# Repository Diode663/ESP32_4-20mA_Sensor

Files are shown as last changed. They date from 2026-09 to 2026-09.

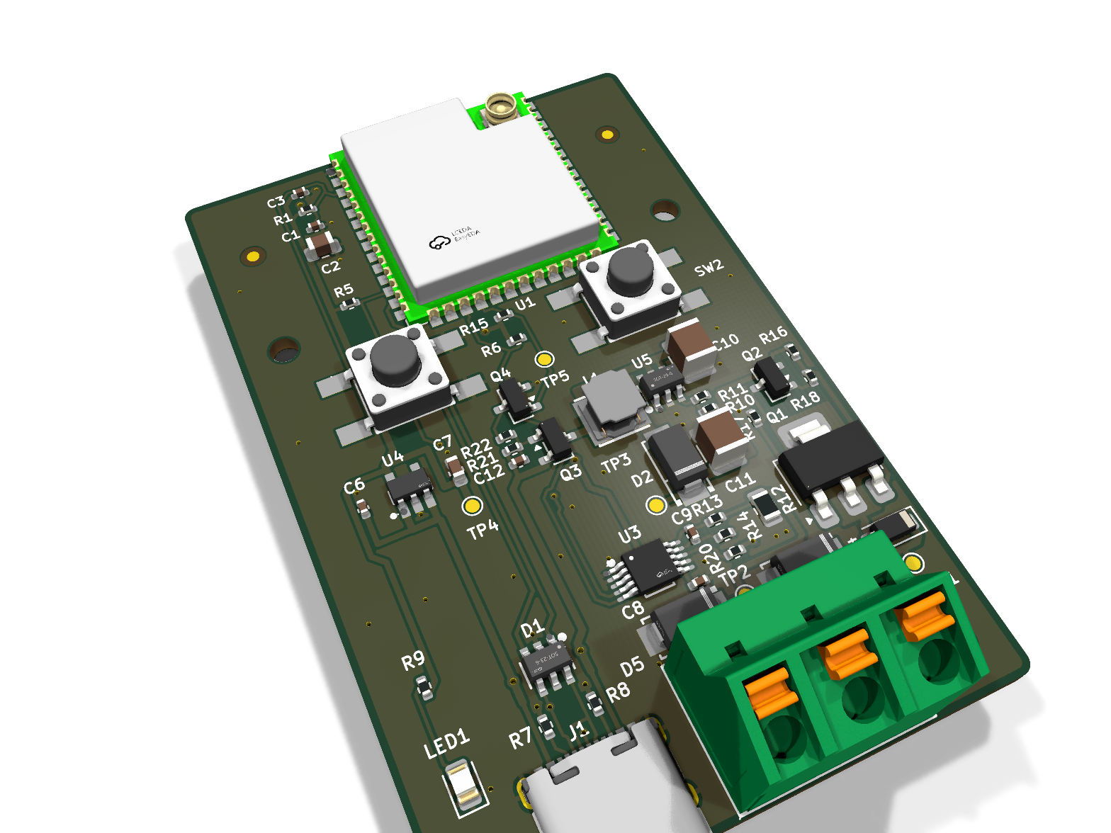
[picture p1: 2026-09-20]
render/pcb_angled.png

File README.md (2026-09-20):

# ESP32 4-20mA ESPHome Sensor Board

Single-channel industrial 4-20mA current-loop reader, USB-C powered, built for ESPHome.

## Rev G at a glance (2026-09-20)

Rev G is the result of a second, independent design review
(`docs/Design_Review_2026-09-20_second_pass.md`). Every circuit change below
was simulated first; the decks are in `sim/` and run on KiCad's own bundled
ngspice.

| Change | Why |
|---|---|
| Limiter is now **constant-current**: R19 removed, R16 18 ohm, Q1 -> BCP53-16 (SOT-223) | Rev F's foldback could park a transmitter at ~9 V / 14 mA after a short or a hot-plug and report that as the reading |
| **D4** (1N4148W) in series after Q1 | a surge on `LOOP_V` drove Q1 backwards into the 24 V rail from ~25 V, long before the TVS conducted |
| **D3 -> SMAJ28A to GND**, new **D5** SMAJ12A from `LOOP_RTN` to GND | one TVS across the pair handled only differential surges; common-mode went through the shunt into the INA226 |
| **Soft-start load switch** Q3/Q4/R21/R22/C12 ahead of the boost | VBUS saw ~27 uF at attach against USB's 10 uF limit; it now sees 1 uF, and `MT_EN` low truly disconnects the loop supply |
| **J2 is 3-pin**: GND, mA in, +24 V out | a 3-wire or self-powered (sourcing) transmitter could not be connected at all |
| **J2 is a one-piece push-in block**, KEFA KF250NH-5.0-3P (`C976567`) | no separate plug to order or lose; solid and ferruled wire pushes straight in, the orange button releases it or opens it for bare stranded wire |
| **U1 is the ESP32-S3-WROOM-1U-N4** (`C2980296`): U.FL connector, external antenna | antenna goes on the enclosure, not inside it. **The board is unchanged** - see below |
| L1 4.7 -> **22 uH** | a quarter of the ripple current at this light load |
| Boost and INA226 re-placed to their **datasheet layout figures** | switched-current loop 28 -> 19 mm^2 with C11's ground 3.8 mm from U5's (was 9.7); C8 1.5 mm from VS (was 8.0, on the wrong side of the chip) |
| Top M2 holes moved from the corners to y = 16.8 mm | they were level with the antenna, 9.6 mm from the module |
| `pcblib`: swaps changed footprints, DRC runs with `--schematic-parity` | the board had kept 1.5 mm test pads the schematic dropped for 1.0 mm, and nothing could see it |

**State:** 28 nets / 35 no-connects match the specification exactly, ERC 0
errors, schematic parity clean, placement DRC 4 (all deliberate silk-at-edge)
+ 5 library-internal, 52 parts + 4 holes + 3 fiducials, BOM 34 lines / 47
placements. **Placed and routed** - 0 unconnected, DRC unchanged at 4 + 5; see
[Routing](#routing).

**Firmware:** `firmware/` holds the ESPHome configuration, and both of the
things this board's firmware had to do are done there:

1. A reading is published as *unknown*, not as a plausible number, whenever
   the loop is not trustworthy - including `LOOP_V` below 20 V with current
   flowing. On a sustained short (`LOOP_V` < 3 V) it drops `MT_EN`, which now
   removes the supply entirely, retries three times and then latches off.
2. Two-point calibration at 4 mA and 20 mA, captured from Home Assistant with
   a reference source and stored in flash. R12's 1 % tolerance and 200 ppm/°C
   drift and R20's fixed gain error all come out together; one point cannot
   remove them.

The firmware is a reusable ESPHome package, pulled by URL, so another board
built from this design tracks the same definition.

It also classifies faults to NAMUR NE43 and detects a backwards-wired sourcing
transmitter, which reads as negative current through the shunt. Validated on
ESPHome 2026.9.0: config clean, and it compiles to 47 % of the N4's
application partition. See `firmware/README.md`.

### Going back to the PCB-antenna module

The -1U was swapped in **without touching the board**, deliberately. Espressif's
datasheet gives the -1 and the -1U one land pattern (Figures 10 and 11 carry
identical dimensions; the -1 only adds the antenna area), so the new footprint
`WIFIM-SMD_ESP32-S3-WROOM-1U` copies the old one's 61 pads and its origin
unchanged and differs only in body outline and 3D model. The outline, the
6.5 mm the antenna would overhang, the keep-clear at the top edge and the
lowered top mounting holes are all still laid out for the -1.

To revert, change one line in `generate_schematic.py` (the old line is kept
there as a comment) and re-run both generators. No copper moves.

With the -1U fitted the radio has **no antenna of its own**: the U.FL pigtail
and antenna in `bom/non-bom-items.csv` are required, and the connector is
U.FL / IPEX generation 1 - the smaller Gen 3/4 (MHF3/MHF4) plugs do not mate.

## Calibration

**Do this before you trust a reading.** R12 is a 1 % shunt with 200 ppm/°C
drift, and R20 adds a fixed 1.19 % gain error to the voltage reading. A single
point cannot remove both a gain and an offset error, which is why there are
two. The firmware ships with the identity calibration, so an uncalibrated
board is out by whatever its own components happen to be.

You need a loop calibrator, or any adjustable current source you trust to
better than the accuracy you want out of the board.

1. Wire the calibrator into **J2 pins 3 and 2** as if it were a 2-wire
   transmitter — the board supplies the 24 V and the calibrator sinks the
   current. An active source works too: push into pin 2, return on pin 1, and
   turn *Loop power* off first so the two supplies do not fight.
2. Set **4.000 mA**. Watch the `Loop current (raw)` entity and wait for it to
   settle — the median filter takes about 3 s, so give it ten.
3. Press **Calibrate: capture 4 mA**.
4. Set **20.000 mA**, wait again, press **Calibrate: capture 20 mA**.
5. Read the **Calibration** entity. It reports the pair you captured together
   with the resulting gain and offset, for example
   `4mA=4.0123  20mA=19.9871  gain=1.00212  offset=-0.0208 mA`.
   A gain more than a couple of percent from 1.000 means something is wrong —
   check the shunt and the wiring rather than accepting it.

A capture is **refused** if the raw reading is more than 2 mA away from the
reference it claims to be, and the log says so. That is deliberate: it stops a
mistimed press silently destroying the calibration.

The result is written to flash and survives reboots and OTA updates.
**Calibrate: reset to factory** puts back the values compiled into the YAML.

Recalibrate if the board's ambient temperature changes substantially: the
shunt's 200 ppm/°C over a 40 °C swing is 0.8 % of reading, about 0.13 mA
across the span. Full procedure and the entity list are in
[`firmware/README.md`](firmware/README.md).

## Project files

```
esp32-4to20ma-board.kicad_pro     Project file
esp32-4to20ma-board.kicad_sch     The schematic — one A2 sheet (generated)
schematic.pdf                     PDF of the schematic
esp32-4to20ma-board.kicad_pcb     Board, 40x61mm portrait — placed and routed
setup_fab.py                      Stackup, netclasses, board rules, .kicad_dru (run before routing)
route_board.py                    Routes the board: scripted critical nets + replayed autoroute + pours
routelib.py                       Routing library (from the kicad-pcb-placement skill): drawing, the
                                  Freerouting hand-off, replay, DRC and pour reports
routing/autoroute.json            Freerouting's result, replayed by route_board.py
routing/drc.json                  The last full DRC report
build_package.py                  Builds fab/: gerbers zip, BOM, CPL, order notes (DRC-gated)
jlc_cpl.py, jlc_rotations.json    CPL exporter and this board's sourced rotation corrections
jlc_compare.py                    Derives those corrections from JLCPCB's own footprints
fab/                              The JLCPCB upload, regenerated by build_package.py
place_components.py               Places every part; the source of truth for the layout
pcblib.py                         PCB builder (from the kicad-pcb-placement skill)
.pcbgen-backup/                   Backups of the board and of the original footprints
sym-lib-table / fp-lib-table      Project-local + KiCad-standard library references
libraries/                        Project-local symbols, footprints, 3D models from LCSC
datasheets/manifest.json          Which manufacturer datasheet was read for each
                                  IC, and where to get it — the PDFs themselves
                                  are copyrighted and not in this repository
firmware/                         ESPHome configuration — a shared package plus
                                  a thin per-device file. See firmware/README.md
bom/bom.csv                       BOM with LCSC part numbers, for JLCPCB turnkey
bom/non-bom-items.csv             Parts to order that aren't on the board
bom_report.py                     Regenerates bom/bom.csv from the schematic
docs/Design_Review_2026-09-20.md  Design review (schematic + placement, pre-fab)
docs/Design_Review_2026-09-20_second_pass.md   Second, independent review - what Rev G fixes
sim/                              ngspice decks for the limiter, surge path and USB inrush
analysis/                         Analyzer JSON per run, tracked by manifest.json
generate_schematic.py             Generates the schematic — the source of truth
schlib.py                         Schematic builder (from the kicad-schematic-layout skill)
.schgen-backup/                   Automatic backups of any sheet the generator overwrote
verify_schematic.py               Diffs KiCad's extracted netlist against the spec
netlist_report.py                 Regenerates netlist_report.txt
netlist_report.txt                Pin-level connectivity listing for rework
erc_report.txt                    Verification output (0 errors)
render/pcb_top.png                3D top view, written by place_components.py
render/pcb_angled.png             3D angled view
render/pcb_bottom.png             3D bottom view
render/copper_top.svg, copper_bottom.svg   The copper layers as drawn
render/pcb.svg                    Vector top view
render/pcb_top_pad_overlay.png    The top view with the real pad rectangles drawn
                                  over it — how the J2 pitch error and the three
                                  misplaced 3D models were caught
```

## Schematic organisation

The schematic is **one A2 sheet**. At 47 parts plus five test points the design still isn't complex
enough to justify hierarchy, which would only add page-flipping. The sheet has
four sections, tiled in signal-flow order:

```
USB-C INPUT & ESD   ->   3.3 V REGULATOR & LED   ->   ESP32-S3 MODULE
24 V BOOST CONVERTER   ->   LOOP CURRENT LIMITER   ->   LOOP TERMINAL & MEASUREMENT
TEST POINTS, sheet notes
```

One block per **circuit**, seven in all (it was twelve). The boost converter is
one block with its load switch, input and output in it, not three; the module is
one block with its reset, boot, pull-ups, decoupling and strapping notes, not
"module" and "support circuitry". Reference sheets for these parts are drawn the
same way - Adafruit's ESP32-S3 Feather divides its sheet into "POWER AND
FILTERING", "USB TO SERIAL CONVERTER", "LIPO CHARGING" and so on, with the module
and everything that serves it in one region.

Drawing conventions throughout:

- **Flow and orientation:** signals flow left to right; supplies come in from
  the top and grounds leave at the bottom.
- **Power rails:** `GND`, `+3V3`, `+5V` and `+24V` are drawn as power-port
  symbols, not text labels.
- **Links between sections:** the sections connect by net label — `USB_P` and
  `USB_N` from USB-C to the ESP32-S3, and `I2C_SDA` and `I2C_SCL` from the
  ESP32-S3 to the INA226.
- **Wires vs labels:** components are wired with real wires and junctions.
  Short labelled stubs are used only where a wire would cross another net: the
  USB-C flip pairing, the CC pulldowns, the MT3608's FB/SW pins and the INA226
  sense lines. There are no wire crossings on the sheet.
- **Blocks and notes:** each circuit is drawn inside `s.block_start(title)` /
  `s.block_end()`, with its design calculations as notes *inside* the block.
  No rectangle is typed by hand: `schlib` derives each outline from what is in
  the block (parts, field text, labels, notes, measured at KiCad's own glyph
  widths) plus 5 mm, and `arrange()` flows the blocks across the page in the
  order they are declared. `check_text()` then reads KiCad's render and fails
  on any string or part body within 0.8 mm of an outline. Run against the old
  hand-boxed sheet that check reports about a hundred such faults (`I2C_SCL`
  on the module box's edge, the strapping notes across another, `+24V` on the
  limiter's top line); on this sheet, none.

### Regenerating

`generate_schematic.py` is the source of truth. Edit it rather than the
`.kicad_sch` file, which gets regenerated:

```bash
python3 generate_schematic.py && python3 netlist_report.py
```

The generator re-checks the geometry and verifies the drawn netlist against its
`NETS` spec, using KiCad's own netlister. It also runs ERC, then a text check.
The text check reads KiCad's rendered SVG and flags any reference, value,
label or note that is drawn sideways, lies on a wire, or overlaps a part.

If the sheet was changed in KiCad since the last run, the generator refuses to
overwrite it. It backs the file up to `.schgen-backup/` first; port your edits
into the script, then rerun with `--force`.

### PCB after the switch to one sheet

Footprints are linked to schematic symbols by the symbols' sheet path, and
flattening the hierarchy changed every path. Update the PCB like this:

1. Run **Tools → Update PCB from Schematic**.
2. Tick **"Re-link footprints to schematic symbols based on their reference
   designators"**. All references are unchanged, so every footprint re-links.
3. Expect local net names to change prefix, e.g. `/USB-C Input…/CC1` → `/CC1`.
   The board has almost no routing yet, so nothing is lost.

From now on, UUIDs are deterministic, so regenerating won't break the links
again.

## Routing

The board is **routed**: 0 unconnected items, DRC at the same 4 + 5 it had as a
bare placement (four deliberate silk-at-edge warnings, five inside library
footprints), schematic parity clean. Two scripts, run in this order after
`place_components.py`:

```bash
"C:\Program Files\KiCad\10.0\bin\python.exe" setup_fab.py
"C:\Program Files\KiCad\10.0\bin\python.exe" route_board.py
```

`setup_fab.py` writes the JLCPCB 2-layer stackup (JLC0216A, 1.6 mm), the
netclasses (`USB` 0.25/0.20 mm pair, `POWER` 0.4 mm, `LOOP` 0.3 mm with 0.25 mm
clearance, `GND`) and a three-rule `.kicad_dru`. The board constraints are the
ones in *Fabrication rules* below, unchanged.

`route_board.py` is a **hybrid**. It removes every track, via and copper zone
and redraws them, so it is safe to run again after any placement change - and
it **discards hand edits to tracks**; change the script, or stop using it.

| Scripted (255 segments and vias) | Why it is not left to an autorouter |
|---|---|
| MT3608 boost | Figure 3: CIN returns to pin 2 *under* the IC, COUT returns down the east side of D2, the switch node is two stubs under 2 mm, FB is 1 mm from pin 3 to the divider |
| INA226 taps | Figure 30: the two taps enter the shunt pads on their inner faces as a pair; load current enters and leaves on the outer faces. R14.1 is on GND by name only, so the pour is kept off it - it sees the shunt pad and nothing else |
| USB-C fan-out, D1, the pair | see below |
| +5V, +3V3 and +24V trunks, the 24 V loop | widths, and the one place each may change layer |
| Q1's copper | tab and pin 2 are one area top and bottom (40 + 45 mm2), six vias under the body |
| every ground via, both pours | the bottom pour is **one unbroken piece** of 2179 mm2 |

Freerouting 2.4.1 does the rest - EN, IO0, MT_EN, I2C, the load-switch gate
network, the LED and the +3V3 branches: 113 segments, 7 vias. It runs only with
`route_board.py --autoroute`; its result is stored in `routing/autoroute.json`
and replayed on every ordinary run, so the board is reproducible (two runs give
byte-identical tracks) without Java and without re-rolling the autorouter. Run
`--autoroute` again if a part that only it touches moves. Runs differ: each one is
judged by KiCad's own DRC on a trial board and repeated (up to three times) until
nothing is left open, and `FREEROUTING_BEST_OF=3` keeps the best of three. Look at
the result either way - one re-roll here passed DRC with the bottom ground in two
pieces. It expects
`~/tools/freerouting/` (or `FREEROUTING_HOME`) to hold `freerouting-2.4.1.jar` and a Java
25 runtime; it runs headless, with the fan-out stage and telemetry off.

Three things about KiCad 10 + Freerouting 2.4.1 that cost time and are handled
in `routelib.py`: KiCad exports existing tracks as `(type route)`, which an
autorouter may rip up, so the DSN is patched to `(type protect)`; KiCad's
`ImportSpecctraSES` then refuses the session file, so the script reads the SES
itself and takes only unprotected items on nets it did not route; and
Freerouting does not count a track that ends inside a pad, off its centre, as
connected, so whatever it adds to a fully scripted net is dropped as a duplicate.

**USB.** J1's D+/D- pads read N P N P. The *outer* two (B7, B6) are the main
path - D- west, D+ east - which is the order both D1 (turned 180 degrees) and
module pins 13/14 want, so the pair never crosses itself. A6 joins D+ on the top
layer; A7 joins D- by the only bottom strap in the pair, 2.9 mm. The two VBUS
pins are joined on the board by a 4.8 mm bottom link under D1, which also feeds
D1's pin 5 (a receptacle's VBUS pins are only joined inside a plug). The pair
is 39.6 / 43.8 mm including those stubs; at the S3's 12 Mbit/s full speed the
4 mm difference is about 25 ps against an 83 ns bit.

**Where the bottom ground is cut**, all of it: the two USB-entry links above,
one SDA hop of 9.8 mm that passes under the pair at 45 degrees, +3V3 to the
pull-ups and U3 (39 mm in two runs, about 1 mA), and LOOP_V's sense tap to R20
(10.5 mm). Nothing crosses under the boost converter.

**Placement changes routing asked for** (all in `place_components.py`): D1
turned 180 degrees and moved up 1.5 mm; R7 and R8 moved into the lanes between
VBUS and the pair, 2 mm from their pins; R10/R11 moved beside U5, which lets
+24V reach the limiter on the top layer; C9 up 0.1 mm; R6 and R15 swapped so
each pull-up sits under its own pin (before that, MT_EN took a 25 mm detour
under the module).

Still open after routing: nothing has been measured. EMC and Q1's temperature
are as designed, not as tested.

## Fabrication package (JLCPCB)

```bash
"C:\Program Files\KiCad\10.0\bin\python.exe" build_package.py
```

writes `fab/`: `esp32-4to20ma-board_gerbers.zip` (9 layers + separate PTH and NPTH drill
files + drill maps), `_bom.csv` (34 lines, 47 parts), `_cpl.csv` (47 placements) and
`ORDER_NOTES.txt`. It refuses to build unless DRC is clean apart from the two accepted
errors inside J1's library footprint, the BOM is read from the board so it is exactly
what is placed, and the build stops if BOM and CPL designators differ or the board
disagrees with `bom/bom.csv`.

Three things to know before ordering:

- **Standard PCBA, not Economic.** JLCPCB lists the ESP32-S3-WROOM-1U-N4 (`C2980296`)
  as "PCBA Type: Standard Only". J2 is the one through-hole part; it is "Economic and
  Standard", wave-soldered, and rides along.
- **Rotations were derived, not guessed.** `jlc_compare.py` fetches JLCPCB's own
  footprint for each part's LCSC number and matches it to the board's, pad number to
  pad number. Every project-library footprint is already at JLCPCB's zero with zero
  origin offset. Only the four stock-KiCad transistor footprints differ - Q1 (SOT-223)
  and Q2, Q3, Q4 (SOT-23) need +180 - and those are in `jlc_rotations.json`, each with
  its evidence. None of it has been seen in JLCPCB's placement preview yet:
  `ORDER_NOTES.txt` says what each part should look like there. LED1's polarity rests on
  pad 1 being the cathode in their footprint (its silk says so; their symbol could not
  be fetched to confirm) - a reversed LED only stays dark.
- **All 34 lines were in stock at LCSC on 2026-09-20**, thinnest: U1 1,702, J2 1,990,
  R12 4,810, C10/C11 8,605. Nine manufacturer names in the BOM were wrong (the Samsung
  capacitors were listed as CCTC, the FOJAN resistors as Uniroyal, LED1 as
  "Nichia-compatible" - it is Nationstar) and were corrected in `generate_schematic.py`;
  every MPN and LCSC number was already right.

## PCB placement

Components are placed on a **40 × 61 mm** two-layer board,
portrait, with 1 mm rounded corners, by `place_components.py` on top of
`pcblib.py`. Run it with KiCad's Python:

```bash
"C:\Program Files\KiCad\10.0\bin\python.exe" place_components.py
```

**Re-running resets every part to the table.** Once you start adjusting
placement by hand, editing the `PLACEMENT` table is the only safe way to
change it. `pcblib` enforces this: it hashes the board each time it writes,
and if the file has changed since, it backs it up to `.pcbgen-backup/` and
refuses. Port your changes into the table, then run with `--force`.

Each run also:

- imports any footprint the schematic has and the board lacks, and reloads
  every footprint from its library, so schematic and `.kicad_mod` changes
  both reach the board without a trip through the KiCad GUI;
- re-links every footprint to its schematic symbol by UUID and assigns pad
  nets from KiCad's own netlist, so the ratsnest is right immediately and
  *Update PCB from Schematic* finds nothing to change;
- puts each reference designator where it clears pads, silkscreen, its
  neighbours and the board edge, at 0.15 mm stroke (JLCPCB's minimum);
- checks courtyard overlaps, **pad-to-pad gaps between different parts**,
  off-board parts and keep-out intrusions before saving, and aborts rather
  than writing a broken board. The pad-gap check matters: 8 of these 52
  footprints draw their courtyard around the body and leave the pads
  outside it (SW1 by 2.66 mm), so courtyard clearance flatters them. It
  caught the buttons sitting 0.35 mm from the module's pad row and the CC
  resistors 0.21 mm from J1 — both legal for DRC, both far too tight;
- runs DRC and **splits it in two** — placement problems, which are yours to
  fix, and problems inside a single library footprint, which moving parts
  cannot fix. Expect **4** and **5** respectively, 0 unconnected items, and
  `schematic parity: clean`. (Run it after moving a part and it will report
  shorts until `route_board.py` has been run again - the old tracks are still
  where the part used to be);
- prints the span of the critical nets, so the claims below are measurable
  rather than asserted;
- writes `render/pcb_top.png`, `render/pcb_angled.png` and `render/pcb.svg`.

All 5 placement-level warnings are `silk_edge_clearance`, on J1 where the
USB-C shell meets the board edge and on U1 where the module crosses the top
edge to overhang it - both deliberate.

`tidy_references` orders parts by `_part_extent()` (pads, silkscreen and
courtyard, deliberately blind to the text) with a natural sort on the
reference as tie-break, so repeated runs give byte-identical designator
positions. In Rev G it also searches further: the same eight spots with the
text turned upright, then both again up to 2 mm out, and it treats other
parts' courtyards as obstacles - pads and silk alone left the middle of the
SOT-223 looking like free board, and it put R12's designator there.

That still cannot solve the lower-right corner, which holds the limiter, the
sense network, two TVS diodes and the terminal. `REF_PINS` in
`place_components.py` places 18 designators by hand, each checked against DRC.

Five test points (`TP1`-`TP5`, 1.0 mm bare pads) sit on `LOOP_V`, `LOOP_RTN`,
`+24V`, `+3V3` and `MT_EN`. They are real schematic symbols - that is the only
way they get a net - but carry `in_bom=False`. Until Rev G the *board* still
held 1.5 mm pads: `pcblib` never propagated a footprint changed in the
schematic. It does now, and `Board.drc()` runs with `--schematic-parity`.

Four M2 holes: the bottom pair 3.5 mm in from the corners beside the
connectors, the top pair at y = 16.8 mm beside the buttons - 19 mm from the
antenna (Espressif asks for ~15 mm clear of metal) and 1.8 mm clear of the
button pads for a 4.6 mm standoff.

Three fiducials (`FID1`/`FID2`/`FID3`, 1 mm copper in a 2 mm mask opening)
sit at (4, 7), (36, 7) and (36, 54) mm — an L, 4 mm in from the edges, which
clears JLCPCB's 3.85 mm minimum. They are board-only footprints: no schematic
symbol, excluded from the BOM and from the placement file, so they cannot
become orphan designators in a PCBA upload.

`pcblib.py` is the shared library from the `kicad-pcb-placement` skill; it is
copied in so the project stays self-contained.

### Why the board is this shape

**Portrait, 40 × 61 mm.** About the minimum for this part set. The
measured extents are 2.40 mm of margin left and right — set by the M2
mounting holes, not by any component — J1's shell flush with the bottom edge,
and C3 1.80 mm from the top. Width is pinned by the bottom edge: J2's
courtyard is 12 mm wide (it includes the mating plug), J1's is about 10, and
the two corner mounting holes take 6 mm between them. Height is pinned by the
vertical stack: module 19 mm, buttons 7, boost 14, sense chain 10, connectors
10. The extra 1 mm over the first attempt buys ~1 mm of clearance either side
of the buttons.

**The antenna overhangs the top edge.** The board stops level with the start
of the module's pad rows, so 6.5 mm of antenna hangs in free air —
Espressif's best case, and better than any keep-out on a populated board. The
module is then soldered on three edges with that 6.5 mm unsupported, so the
enclosure needs clearance around it and must not press on it. There is no
antenna keep-out zone any more: the overhang replaced it. At routing time,
keep the ground pour back from the top edge.

**Both connectors are on the bottom edge**, as asked. Note that J2 is a
*vertical* plug-in header — the mating plug drops in from above — so its
position at the edge is for cable dressing, not because it needs edge access.

| Area | What's there | Why |
|---|---|---|
| Top, antenna overhanging | ESP32-S3 module, centred | No PCB under the antenna at all |
| Upper left | C3 at pin 2 (3V3), R1/C1 at EN, C2 bulk, R5 at pin 12 | The module's 3V3, EN and SDA pins are all on the left flank; each part sits level with the pin it serves |
| Below the module | RESET and BOOT buttons, R6 and R15 in the gap between them | SCL (17) and the loop enable IO10 (18) come out of the module's bottom edge, right where their pull-ups sit |
| Left, middle | AP2112K LDO + C6/C7 | Between its 5 V source at the bottom and its 3.3 V loads above |
| Right, middle | MT3608 boost: C10, L1, U5, D2, C11 in one tight loop, FB divider by the FB pin | Per the MT3608 datasheet, and the furthest point on the board from the antenna |
| Right, lower | INA226, shunt R12, R13/R14 tapping its two ends, C9 | Kelvin sense per the INA226 datasheet; U3 faces the shunt with its inputs and the MCU with its I²C |
| Bottom left | USB-C, D1 ESD clamp directly above it, CC pulldowns either side, LED on the left edge | D+/D− run connector → clamp → module with nothing in the way |
| Bottom right | 4-20 mA terminal J2, TVS D3 just above it aligned with its pins | Field wiring lands at the edge and is clamped immediately |

Measured after placement:

| Net | Span | Comment |
|---|---|---|
| `/MT_SW` | 5.45 mm | the boost switching node — the one that matters |
| `/LOOP_RTN` | 9.68 mm | terminal to shunt |
| Kelvin taps | 1.69 mm | R13 and R14 each sit against the shunt pad they measure |
| `/USB_P` / `/USB_N` | 35–36 mm | the cost of portrait: connector at the bottom, module at the top. Fine for the S3's 12 Mbps full-speed USB, but route them as a pair over unbroken ground |
| `/I2C_SDA` / `/I2C_SCL` | 28–35 mm | 400 kHz, length is irrelevant |

### Loop short-circuit protection

A boost converter cannot disconnect its output: `Vin -> L1 -> D2 -> Vout` is a
DC path that conducts with U5 disabled. Shorting Loop+ to Loop- therefore fed
~1.35 A from the 5 V rail straight through the shunt, destroying R12 (about
6 W in an 0805) and browning out the board.

The fix is a series element, which costs only compliance voltage, never
accuracy, because the transmitter regulates the loop current:

| | |
|---|---|
| Q1 | PNP pass element, **BCP53-16 in SOT-223** (80 V, 1.5 W) |
| R16 | 18 ohm sense; Q2 steals Q1's base drive once the drop across it reaches a Vbe |
| R18 | 1 k in Q2's base - limits its base current, nothing more |
| R17 | 47 k base bias, ~0.5 mA; BCP53-16 hFE >= 100 turns that into 50 mA |
| D4 | 1N4148W in series after Q1: blocks `LOOP_V` from driving Q1 backwards |

`Ilim = Vbe(Q2) / R16`: **35 / 33 / 30 / 27 mA at -20 / 25 / 60 / 85 C**
(`sim/6_rev_g_limiter.py`), so a 24 mA over-range reads at any temperature.
R16 + Q1 + D4 cost 1.2 V: **22.8 V at J2 with 20 mA flowing**.

**It is deliberately not a foldback limiter, and Rev F's was a mistake.** A
2-wire transmitter is a constant-current load: it draws the same current at
any voltage above its lift-off, so its load line can cross a foldback curve
twice, and the lower crossing is stable. After a short was cleared, or a
transmitter was plugged into a live J2, Rev F could sit at ~9 V / 14 mA
indefinitely with the process at 20 mA - and report 14 mA
(`sim/recover.py`). Its short-circuit current was also the small difference of
two ~0.6 V terms and fell to zero by ~65 C. Cold power-up happened to work,
which is why it looked fine.

The price is dissipation: a dead short puts the whole rail across Q1,
24 V x 35 mA = **0.85 W**. That is what the SOT-223 is for - pour `LOOP_C`
generously around the tab and stitch it to the bottom layer. Firmware should
also drop `MT_EN` on a sustained short; with the Rev G load switch that
removes the supply entirely rather than leaving 4.6 V behind.

### Field protection

Each field wire has its own TVS **to ground**, within 6 mm of its terminal
pin: D3 (SMAJ28A, clamps at 45 V) on `LOOP_V`, D5 (SMAJ12A, clamps under
20 V) on `LOOP_RTN`. Rev F had one SMAJ36A *across* the pair, which did
nothing for a common-mode surge: that returned through R12, and the INA226's
inputs saw `I x 3.32 ohm` through only 10 ohm. D5 sits at 80 mV in normal
operation and leaks nanoamps, so it costs no accuracy; and D3's leakage no
longer flows through the shunt.

D4 matters as much as the TVS. `LOOP_V` was Q1's collector, and a PNP's
collector-base junction is a diode: from ~25 V it conducted backwards, the
emitter-base junction avalanched at ~7 V of reverse bias, and the surge went
into the 24 V rail through R16 - toward U5's SW pin, rated 30 V absolute - all
before the old 36 V TVS reached breakdown (`sim/4_reverse_conduction.py`).
With D4 the reverse current is zero to beyond D3's clamp. It is a 1N4148W
rather than a Schottky because it sees the clamp minus the rail in reverse.

### Soft-start load switch

Q3 (AO3401A) sits between VBUS and everything the boost hangs on it: C10, and
C11 through L1/D2. Q4 (2N7002) turns it on from `MT_EN`; U5's own EN now rides
on its switched input. C12 is gate-to-**source** on purpose - a gate-to-drain
(Miller) capacitor was tried first and fails at hot-plug, because with the
drain at 0 V it drags the gate low as VBUS steps up and turns Q3 hard on for
the very edge it is meant to soften. Simulated (`sim/7_usb_inrush.py`): VBUS
sees **1.0 uF at attach, down from 26.8 uF** (USB allows 10), then a 0.33 A
peak 4 ms later as the boost input charges.

The INA226's VBUS tap moved to the **field side** of the limiter, so a short
shows up twice over: the current reads saturated (anything past 24.67 mA) and
the loop voltage collapses. Firmware can tell a shorted field pair from an
open one.

### J1's hole clearance, and why the rule moved

All four `hole_clearance` errors were inside J1's own footprint — its two
0.70 mm NPTH locating pegs against its own pads, nothing to do with placement.
JLCPCB publishes **0.20 mm** NPTH-to-track for 2-layer boards; this project was
running a stricter 0.25 mm, so half the errors existed only because of our own
rule. `min_hole_clearance` is now 0.20 mm and the count drops to two.

The two that remain (0.1812 mm, 0.019 mm inside JLCPCB's limit) are an
**accepted deviation**: they are on the *duplicated* GND pads — A1/B12 and
B1/A12 are the same nets on both sides of the receptacle — so a drill breakout
into one would not open the connection. If JLCPCB objects at DFM review, the
fallback is to trim those two pads by ~0.07 mm, which costs about 6 % of their
solder area and clears even the old rule.

### Fabrication rules (JLCPCB, 2-layer)

Board Setup now carries JLCPCB's published capabilities. Where the board was
already stricter it was left alone — being tighter than the fab is a design
choice, being looser is a defect:

| Rule | Was | Now | JLCPCB |
|---|---|---|---|
| Minimum clearance | **0.0 (off)** | 0.127 | 0.127 |
| Silkscreen line width (default) | 0.10 | 0.15 | 0.15 |
| Silkscreen text thickness (default) | 0.10 | 0.15 | 0.15 |
| Track width | 0.153 | 0.153 | 0.127 |
| Via diameter / annular ring | 0.5 / 0.13 | unchanged | 0.45 / 0.125 |
| Through-hole diameter | 0.3 | unchanged | 0.2 |
| Copper to board edge | 0.5 | unchanged | 0.3 required, 0.5 recommended |

The important one is **minimum clearance, which was 0.0** — DRC had no global
spacing floor at all, only the netclasses' own 0.2 mm. The track and via size
menus were empty and are now populated with 0.25/0.4/0.6/0.8 mm tracks and
0.6/0.3, 0.8/0.4 vias, all above JLCPCB's floor.

JLCPCB does not publish a hole-to-copper figure, so `min_hole_clearance`
stays at the widely cited 0.25 mm — which is what J1's four remaining errors
are measured against. See below.

### Library-footprint fixes

The EasyEDA-sourced footprints in `libraries/esp32-4to20ma-board.pretty/`
had three real problems. All three are now fixed; the originals are in
`.pcbgen-backup/footprints-*/`.

| Part | Was | Now | Why |
|---|---|---|---|
| U1 | 12 thermal vias in the ground pad, unnumbered, 0.25 mm drill, 0.075 mm ring, paste over an open hole | pad `41`, 0.30 mm drill, 0.60 mm pad (0.15 mm ring), no paste, mask opening on the front only | Unnumbered meant they carried no net, so they grounded nothing *and* read as a foreign net inside the pad they sit in — that alone was 24 clearance errors. The drill and ring were below the board minimums. Paste over an open hole wicks solder away from the joint; tenting the back stops it running through |
| J1 | two 0.7 mm locating pegs defined as plated holes with pad = drill, so no copper ring at all | `np_thru_hole` | They are mechanical locating posts, not connections |
| J2 | 3D model pointed at `WJ5.08-LI`, a different part | KiCad's `PhoenixContact_MSTBVA_2,5_2-G-5,08_1x02_Vertical` | Cosmetic. A stand-in of the same class, pitch and pin count — its body renders a little larger than the real WJ2EDGVC, which is 9.5 × 5.6 mm |

That took the footprint-level DRC count from **59 to 7**, and the board from
96 unconnected items to 88 (the 12 vias now join GND).

**A fourth problem, found on 2026-09-20 by looking at the 3D render:**

| Part | Was | Now | Why |
|---|---|---|---|
| J2 | pads at ±2.50 mm — a **5.00 mm pitch** | ±2.54 mm, **5.08 mm** | `C8445` is `WJ2EDGVC-5.08-02P`; LCSC's own parametrics say `P=5.08mm`. The footprint was 0.08 mm narrow across the pair. With a 1.70 mm drill and ~1.0 mm pins it would still have assembled, so DRC and the netlist never saw it — but it was wrong, and it is the kind of error that only shows up when a part will not seat |
| D2 / D3 / D5 (SMA) | courtyard ±2.16 × ±1.30 mm, drawn round the body — the 2 × 2 mm pads at ±2.2 stuck 1 mm out of it | ±3.45 × ±1.55 mm, pads + 0.25 | Rev G. With the pads outside the courtyard, a layout that was courtyard-legal put two SMAs dead against a test pad: DRC reported `shorting_items`. |
| L1 (FNR4030) | courtyard ±2.00 mm square; pads reach ±2.30 | ±2.55 × ±2.25 mm | Rev G, same cause. |
| J2 (3-pin) | — did not exist | `CONN-TH_WJ2EDGVC-5.08-3P` | Rev G. Derived from the corrected 2-pin footprint: same profile, one more 5.08 mm position, body 17.2 mm. LCSC `C8412`. **Superseded the same day by the KF250NH below; the footprint is kept in the library, unused.** |
| J2 (KF250NH-5.0-3P) | — new | `CONN-TH_KF250NH-5.0-3P`, with symbol and STEP/WRL model | From LCSC/EasyEDA (`C976567`) via `easyeda2kicad`. Checked against KEFA's drawing before use, because the last EasyEDA terminal footprint had the wrong pitch: 5.00 mm pitch, 14.1 × 10.0 mm body, pins 5.70 mm from the wire-entry face, Ø1.5 drill against Ø1.4 +0.1 — all correct. Symbol pins changed from *unspecified* to *passive*. |
| U1 (WROOM-1U) | — new | `WIFIM-SMD_ESP32-S3-WROOM-1U` | The **existing** footprint's 61 pads and origin copied unchanged, with the 19.2 mm body outline and the -1U 3D model from EasyEDA (`C2980296`). EasyEDA's own -1U footprint was *not* used: its pad centres sit 0.15 mm further in than the verified pattern already on the board. Model offset 0.54 mm, checked in the render. |

**And three 3D models were misplaced** — cosmetic for fabrication, since gerbers,
drill, paste and CPL all come from the 2D layers, but they make the render
useless for judging mechanical fit, which is exactly what a render is for:

| Part | Offset added | Why |
|---|---|---|
| U1 | `0, 3.700, 0` | The model is centred on its own body; the footprint origin is at the centre of the **pad array**, and the module's 6.5 mm antenna end carries no pads. The body was drawn 3.7 mm down the board |
| J1 | `0, -1.190, 0` | Same class of problem — the USB-C shell is not centred on the pad array |
| J2 | `-2.540, 0, 0` | The Phoenix stand-in's origin is on **pin 1**, not between the pins, so the body sat one half-pitch to the right |

Verified by measuring the rendered bodies against the footprints' silkscreen
outlines: all three now agree to within 0.2 mm. `render/pcb_top_pad_overlay.png`
is the render with the real pad rectangles drawn on top, which is how the
mismatch was confirmed rather than eyeballed.

`place_components.py` calls `refresh_footprints()` before placing, so
library fixes reach the board — KiCad stores its own copy of every
footprint, and editing a `.kicad_mod` alone changes nothing.

**Still open, both judgement calls rather than mistakes:**

- **4 × `hole_clearance` on J1.** The two NPTH locating pegs sit 0.18 mm and
  0.22 mm from the neighbouring USB-C pads, against a `min_hole_clearance`
  of 0.25 mm in Board Setup. That is the connector's real geometry, not an
  error — the part is simply dense. Check what your fab actually allows for
  a non-plated hole next to copper; if it is 0.15 mm, relax the rule rather
  than shaving the pads.
- **3 × `silk_over_copper`** on J1, SW1 and SW2, where each footprint's own
  outline crosses its own pads. Cosmetic; fabs clip silkscreen at the mask
  automatically.

**Not a footprint problem, but worth noting:** J2 is the *board-side header*
only. The mating plug — the screw-terminal half the field wires land in — is
a separate part and is not in the BOM. It is a vertical part: the plug drops
in from above, so nothing about it requires the board edge.

### Why it's no longer hierarchical

Rev B used a root block diagram plus four sub-sheets. The old sheets are in
`.schgen-backup/flatten-*/` and in KiCad's Local History.

## Design summary

- **MCU**: ESP32-S3-WROOM-1U-N4 (4MB flash, U.FL connector for an external antenna), dual-core LX7, Wi-Fi/BLE, **native USB** — no USB-UART bridge chip.
- **Power in**: USB-C receptacle, data+power (no PD negotiation — plain 5V/500mA sink). CC1/CC2 have 5.1kΩ pulldowns per USB-C spec. USBLC6-2SC6 ESD-protects the D+/D- lines, wired straight through to the S3's native USB pins (IO19/IO20).
- **Programming**: no bridge chip, no auto-reset transistors. Per Espressif's own ESP32-S3-WROOM-1 reference design, the chip's internal USB-Serial/JTAG Controller peripheral handles esptool's reset/bootloader-entry handshake directly over the native USB connection — GPIO0's default strapping (internal weak pull-up) plus GPIO46's default strapping (internal weak pull-down) already satisfy the "Joint Download Boot" condition, so esptool can flash and open a console with zero external reset circuitry. SW1 (RESET, EN→GND) and SW2 (BOOT, GPIO0→GND) are kept as manual fallback buttons, matching Espressif's reference.
- **3.3V rail**: AP2112K-3.3 LDO (600mA), powers the ESP32-S3 and INA226.
- **24V loop supply**: MT3608 boost converter, 5V→24V, fed through a soft-start load switch (Q3/Q4) and feeding the field terminal through a **constant-current limiter** (Q1/Q2, R16-R18, D4). `MT_EN` is held high by R15 (100k to 3.3V) and pulled low by IO10; it gates the load switch, so firmware can remove loop power entirely or power-cycle a stuck transmitter. L1 is 22µH. Feedback divider R10=390kΩ/R11=10kΩ gives exactly 0.6V×(1+39) = **24.00V**. Rated for far more than the 30mA the loop needs — this is the same MT3608 topology recommended in its own datasheet, just very lightly loaded here.
- **Current sensing**: INA226 (I2C, 16-bit, TI). Low-side shunt R12 = 3.32Ω 1% between the loop-return terminal and GND. The INA226's shunt input is fixed at ±81.92mV with no PGA, so the shunt alone sets the ceiling: 3.32Ω puts full scale at **24.67mA**, which reads a sensor driving 23.5mA over-range instead of clipping. 24mA gives 79.7mV (97% of range) and the 2.5µV LSB works out at 0.75µA — about 21,200 counts across the 4-20mA span, far beyond any transmitter's accuracy. (Rev C used 4.02Ω, which clipped at 20.4mA.) 10Ω series filter resistors (R13/R14) + a 100nF cap across the sense lines follow the INA226 datasheet's own recommended input-protection network (fig. 21) for exposed field wiring. INA226's VBUS pin reads the loop supply voltage as a diagnostic, tapped downstream of the limiter through **R20, a 10kΩ series resistor**: D3 clamps as high as 58.1V at its rated surge current, well past the INA226's 40V absolute maximum, and the pin is rated for only ±5mA. R20 holds the worst case to 1.8mA. It costs 1.19% of gain against the 830kΩ input impedance, which firmware corrects and which does not touch the current measurement.
- **Field wiring**: 3-position one-piece push-in spring terminal, 5.00mm pitch (KEFA KF250NH-5.0-3P, 16–20 AWG) — **1 = GND, 2 = mA in, 3 = +24V out**, numbered left to right looking into the wire entry. A 2-wire transmitter goes on 3-2; a self-powered (sourcing) output on 2-1; a 3-wire sensor uses all three, within the ~30mA limit. Each field wire has its own TVS to ground (SMAJ28A / SMAJ12A).
- **I2C**: GPIO8 (SDA) / GPIO9 (SCL), 4.7kΩ pull-ups — the conventional default I2C pins on ESP32-S3 boards.

## Why these specific parts

Every non-passive part was picked from real LCSC/JLCPCB stock and its **actual manufacturer datasheet was read** (not just the LCSC listing) to get the pinout and application values right — see `datasheets/`. In particular:
- ESP32-S3-WROOM-1's pinout, strapping-pin table, USB_D+/D- pin assignment (IO20/IO19), and Espressif's own peripheral reference schematic (section 6, which explicitly omits any external reset circuitry for the native-USB path) came straight from Espressif's datasheet.
- MT3608's feedback equation, recommended inductor/cap values, and diode rating came from the Aerosemi datasheet.
- INA226's shunt-sensing topology, pin functions, and input-filtering recommendation came from the TI datasheet.

## Why we switched from ESP32-WROOM-32E + CH340C

The board originally used a classic ESP32-WROOM-32E with a CH340C USB-UART bridge for flashing. We switched to a native-USB ESP32-S3 module after comparing both approaches:
- **Fewer parts, similar cost**: dropping CH340C + its 2 bypass caps + both 2N7002 auto-reset transistors + their 2 gate resistors (8 parts total) more than offsets the S3 module's slightly higher unit price — net BOM cost actually went *down* slightly.
- **Better dev experience**: native USB gives real USB-JTAG hardware debugging (impossible on the bridge-chip design without an external JTAG probe) and a driverless CDC-ACM console on modern OSes.
- **Trade-off accepted**: losing CH340C as a "sacrificial" USB layer — if the S3's native USB pins are ever ESD-damaged, both flashing and the wired console go down together, versus the old design where a blown bridge chip only killed flashing (OTA over Wi-Fi still worked). Given this board lives on a bench/in an enclosure rather than a harsh field environment, that trade-off was judged acceptable.

## Verification performed

- **Netlist equivalence**: `verify_schematic.py` exports the netlist with
  `kicad-cli` — KiCad's own connectivity engine, the same one the PCB uses — and
  diffs it against the `NETS` specification in `generate_schematic.py`, matching
  nets by their *set of pins*. All 28 nets and all 35 no-connects match exactly
  (the five test points included).
  This is what catches a mistyped coordinate silently shorting two nets.
- `kicad-cli sch erc` → **0 errors, 59 warnings**: 58 are the "Unspecified" pin
  electrical type carried by EasyEDA-converted symbols (cosmetic — the symbols
  simply don't declare input/output/power roles) and 1 is the expected
  cached-symbol-vs-library sync notice. Report in `erc_report.txt`.
- **Geometry guards** in `schlib.py` run on every build and fail the generate if
  any pin, wire end or label misses the 1.27 mm connection grid, or if a wire end
  connects to nothing. Both classes of defect are invisible to a netlist diff.
- Rotation handling was verified empirically against KiCad rather than assumed:
  placing a `Device:R` at each of 0/90/180/270 and reading back which pin landed
  where (rot 0 → pin 1 up, 90 → left, 180 → down, 270 → right).
- `kicad-happy` schematic analyzer: 33 components / 25 unique parts, zero missing MPNs.
- `kicad-cli pcb drc` on the (currently empty) board outline → 0 violations.

## Known limitations / things to look at before ordering

- **Two nets were renamed** when the rails became power symbols: `VUSB_5V` → `+5V`
  and `LOOP_24V` → `+24V`. The board currently has footprints placed but almost no
  routing, so just run **Tools → Update PCB from Schematic** and KiCad will carry the
  new names over; footprint associations are preserved by the stable UUIDs.
- **The board is routed but nothing has been built or measured.** See [Routing](#routing). The USB pair is coupled but not impedance-controlled: on a 1.6 mm two-layer board 90 Ω needs a coplanar geometry, and at USB Full-Speed (12 Mbps) over 40 mm it does not matter.
- INA226's Alert pin is left unconnected — intentional (the datasheet explicitly allows floating it when the alert function isn't used), but wire it to a spare GPIO if you want threshold interrupts later.
- GPIO3 (JTAG-source strapping pin) is left unconnected. The datasheet notes it has no internal pull resistor and should ideally be actively driven, but since this board doesn't break out a JTAG header, an undefined JTAG-source selection at boot has no functional effect — only relevant if you later add a JTAG connector.
- ~~No dedicated VBUS transient suppressor~~ — **this was wrong, and the datasheet says so.** ST's USBLC6-2 lists "Protects VBUS" in its features and specifies `VBR`, the breakdown voltage between VBUS and GND, at 6V minimum at 1mA: there is a zener inside the part between pin 5 and ground, and D1 pin 5 is on `+5V`. VBUS is protected. (The board's ESD analyzer flags this too, as `UC-002`; it is a false positive.)
- Only 1 channel, per the current 24V/30mA supply budget. See the earlier discussion if you want to scale to multiple loop-powered channels — the 24V rail current draw scales roughly linearly per channel.

## Ordering

`bom/bom.csv` is generated from the schematic by `bom_report.py` — run it after
any part change rather than editing the CSV's first seven columns by hand:

```bash
python bom_report.py
```

It regroups by LCSC number (the ordering key, so SW1 and SW2 merge into one
line despite having different values) and carries the spreadsheet's own
columns — LC_Stock, Chosen_Distributor, Validated, Notes — forward on each
re-run.

**Cost: about USD 7.20 per board** in components at LCSC's single-unit prices
on 2026-09-20 (Rev F was 6.31; the Rev G circuit changes add about 0.24, the -1U module 0.26 and the push-in terminal 0.37), 47 placements over 34
order lines. The module is about 61% of that ($4.41) and the INA226 another
12% ($0.79). Sixteen of the 34 lines are JLCPCB *extended* parts, so turnkey
assembly adds roughly $48 of one-off setup fees on top. Of the Rev G
additions, the 1N4148W, AO3401A and 2N7002 are basic; the BCP53-16, both TVS
diodes, the 18 ohm, the 22 uH and the 3-pin socket are extended. PCB, stencil
and M2 hardware are not included.

`bom/bom.csv` has every part's LCSC number, ready for JLCPCB's BOM/CPL turnkey flow once the PCB is routed and gerbers/CPL are exported (the `jlcpcb` skill covers that step). Anything that has to be ordered but isn't on the board lives in `bom/non-bom-items.csv`, hand-maintained since none of it is derivable from the schematic. Today that is the **U.FL pigtail and 2.4 GHz antenna** the -1U module needs - it has no antenna of its own. (Rev F and early Rev G also needed a mating plug for the pluggable terminal; the one-piece push-in block does not.) Candidates to add when you get to ordering: M2 screws and standoffs for the four mounting holes, a USB-C cable, and a stencil.

## Licence

Copyright Diode663 2026.

**Hardware** (the KiCad project, schematic, board, the project's own symbols and footprints,
fabrication outputs and documentation): this source describes Open Hardware and is licensed under
the CERN-OHL-P v2. You may redistribute and modify this source and make products using it under
the terms of the CERN-OHL-P v2 (<https://ohwr.org/cern_ohl_p_v2.txt>), a copy of which is in
[`LICENSE`](LICENSE). This source is distributed WITHOUT ANY EXPRESS OR IMPLIED WARRANTY,
INCLUDING OF MERCHANTABILITY, SATISFACTORY QUALITY AND FITNESS FOR A PARTICULAR PURPOSE. Please
see the CERN-OHL-P v2 for applicable conditions.

**Software** (every `*.py` file, and the ESPHome configuration in `firmware/`): MIT, see
[`LICENSE-MIT`](LICENSE-MIT). `schlib.py` and `pcblib.py` are copied in from
[kicad-claude-skills](https://github.com/Diode663/kicad-claude-skills) so the project stays
self-contained; they are MIT there too.

**Not covered by either licence** — third-party material, included for convenience and owned by
its respective rights holders:

- Footprints and 3D models obtained from LCSC / EasyEDA with `easyeda2kicad`: everything in
  `libraries/esp32-4to20ma-board.3dshapes/`, and in `libraries/esp32-4to20ma-board.pretty/` the
  `CONN-TH_KF250NH-5.0-3P`, `CONN-TH_WJ2EDGVC-5.08-2P`, `IND-SMD_L4.0-W4.0_FNR40XXS`,
  `MSOP-10_L3.0-W3.0-P0.50-LS5.0-BL`, `SMA_L4.3-W2.6-LS5.2-RD`, `SOT-23-6_L2.9-W1.6-P0.95-LS2.8-BL`,
  `SOT-25-5_L2.9-W1.6-P0.95-LS2.8-BL`, `SW-SMD_4P-L6.0-W6.0-P4.50-LS9.0_H5.0`,
  `USB-C-SMD_TYPE-C-16PIN-2MD-073` and `WIFIM-SMD_ESP32-S3-WROOM-1-N8` footprints. Several carry
  project corrections — pitch, courtyards, pad numbering and 3D offsets — which are documented in
  the library-footprint table above; `CONN-TH_WJ2EDGVC-5.08-3P` and `WIFIM-SMD_ESP32-S3-WROOM-1U`
  are derived from them.
- Manufacturer datasheets are **not** in this repository. `datasheets/manifest.json` records which
  ones were read and where they came from; fetch them from the manufacturers or LCSC.
- Part numbers, stock figures and prices in `bom/` are LCSC's.

Nothing here is affiliated with or endorsed by Espressif, Texas Instruments, Aerosemi, KEFA,
LCSC or JLCPCB.

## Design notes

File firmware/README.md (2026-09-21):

# Firmware — ESPHome

ESPHome configuration for the Rev G board. It turns the INA226's shunt reading
into a calibrated 4-20 mA measurement, classifies loop faults to NAMUR NE43,
and protects the board against a sustained field short.

Validated against **ESPHome 2026.9.0**: `esphome config` is clean,
`esphome compile` builds at **870 KB of the 1.835 MB** application partition
(47 %) with 30 % of RAM used, and `test/test_fault_logic.py` passes 30 checks.
There is real headroom on the N4 module.

## Files

```
package/esp32-4to20ma-board.yaml   The instrument. Everything hardware-specific
                                   and all the logic. Shared by every board.
loop-sensor-1.yaml                 One board: a name, a Wi-Fi network and the
                                   process scaling. Copy this per unit.
secrets.yaml.example               Copy to secrets.yaml and fill in.
```

The split exists so a logic fix reaches every unit at once. The device file
pulls the package straight from GitHub:

```yaml
packages:
  loop_board: github://Diode663/ESP32_4-20mA_Sensor/firmware/package/esp32-4to20ma-board.yaml@main
```

**Pin a tag rather than `@main`** on any instrument you care about — otherwise
an upstream edit rewrites its firmware the next time you flash it.

When you are working on the package *itself*, switch that line to the
commented `!include` next to it. With `github://` you compile whatever was last
**pushed**, not what is on your disk, which is a confusing half hour if you
forget.

## Getting started

```bash
cp secrets.yaml.example secrets.yaml   # then fill it in
esphome run loop-sensor-1.yaml
```

The first flash has to be over USB. The board enumerates as a native
USB-Serial-JTAG device — there is no bridge chip — so `esphome run` finds it
without a driver on any current OS. If it does not appear, hold **SW2 (BOOT)**,
tap **SW1 (RESET)**, release SW2, and try again.

## Calibrating

**Do this before you trust a reading.** R12 is a 1 % shunt with 200 ppm/°C
drift, and R20 adds a fixed 1.19 % to the voltage reading. A single point
cannot remove both a gain and an offset error, which is why there are two.

1. Wire a loop calibrator into **J2 pins 3 and 2** as if it were a 2-wire
   transmitter — the board supplies the 24 V and the calibrator sinks the
   current. (An active source works too: push into pin 2, return on pin 1, and
   turn *Loop power* off first.)
2. Set **4.000 mA**. Watch `Loop current (raw)` and wait for it to settle —
   the median filter takes about 3 s, so give it ten.
3. Press **Calibrate: capture 4 mA**.
4. Set **20.000 mA**, wait again, press **Calibrate: capture 20 mA**.
5. Read the **Calibration** entity. It reports the pair you captured plus the
   resulting gain and offset, e.g.
   `4mA=4.0123  20mA=19.9871  gain=1.00212  offset=-0.0208 mA`.

A capture is **refused** if the raw reading is more than 2 mA from the
reference, and the log says why. That is deliberate: it stops a mistimed press
silently destroying the calibration.

The result is stored in flash and survives reboots and OTA updates.
**Calibrate: reset to factory** puts back the values compiled into the YAML.

Recalibrate if the board's ambient changes a lot: 200 ppm/°C over a 40 °C swing
is 0.8 % of reading, about 0.13 mA across the span.

## Entities

| Entity | What it is |
|---|---|
| **Process value** | The scaled reading, in your engineering units. Goes **unknown** rather than wrong whenever the loop is not trustworthy |
| **Loop current** | mA, calibrated |
| **Loop fault** | Problem flag — true for any status from "Fault:" down |
| **Loop status** | The text below |
| **Loop power** | `MT_EN`. Off removes the 24 V supply entirely |
| *Loop current (raw)* | mA, uncalibrated. This is what you read while calibrating |
| *Loop supply voltage* | Measured at J2 pin 3, corrected for R20 |
| *Transmitter voltage* | The above, less the drop across the shunt — what the transmitter actually gets. Expect ~22.8 V at 20 mA |
| *Loop span* | Percent of 4-20 mA |
| *Reading valid* | True for OK, under-range and over-range |
| *Calibration* | The captured pair, gain and offset |
| *BOOT button* | SW2, readable as a user button after boot |
| *Board temperature*, *Uptime*, *Wi-Fi signal*, *IP address* | |
| **Buttons** | Capture 4 mA · Capture 20 mA · Reset to factory · Power-cycle the loop · Restart |

*Italic* entities are diagnostic.

## Loop status

| Status | Means | Look at |
|---|---|---|
| `OK` | 3.8–20.5 mA — NE43's measuring range, which is wider than 4–20 | |
| `Under-range` | 3.6–3.8 mA | Transmitter below zero and outside the measuring range |
| `Over-range` | 20.5–21.0 mA | Process above full scale |
| `Fault: low (NAMUR)` | below 3.6 mA | Transmitter signalling a fault, or a poor connection |
| `Fault: high (NAMUR)` | above 21 mA | Transmitter fault, or a partial short. Note the ADC clips at **24.67 mA** — the hardware limiter is higher, at ~33 mA, so a hard short reads as "pegged" |
| `Fault: open circuit` | under 0.1 mA | Nothing connected, or a broken wire |
| `Fault: reversed polarity` | negative current | A sourcing transmitter wired backwards across pins 1 and 2. It is also forward-biasing D5 — fix it |
| `Fault: supply low` | `LOOP_V` under 20 V with current flowing | Too much cable resistance, or a partial short |
| `Fault: field short` | `LOOP_V` under 3 V | The field pair is shorted |
| `Fault: short, latched off` | three cuts in a row | Clear the short, then turn *Loop power* back on |
| `Fault: no sensor data` | the INA226 is not answering | I²C, or the 3.3 V rail |
| `Loop power off` | *Loop power* is off | |

Note the bands: NE43's **measuring range is 3.8–20.5 mA**, not 4–20. A
transmitter sitting at 3.9 mA is reporting slightly below zero, not faulting,
so it reads `OK` and the process value goes slightly negative. Under- and
over-range are the strips between the measuring range and the failure
thresholds, and all three publish a reading. Everything below them does not.

## Short-circuit handling

The hardware limiter holds a dead short at about 33 mA, which puts 0.85 W into
Q1 against a 1.5 W package — survivable, but not something to leave running
unattended for days. So:

`LOOP_V` under 3 V for 3 s → drop `MT_EN` → wait 30 s → retry. After three
failures the board **latches off** and says so, and only a human turning *Loop
power* back on clears it. Ten minutes of healthy running resets the counter, so
an intermittent fault weeks apart never accumulates into a latch.

## Tests

```bash
python test/test_fault_logic.py
```

The fault classifier is an eleven-state precedence ladder inside a C++ lambda.
`esphome compile` proves it is valid C++; it cannot prove it is the *right*
C++. `test/test_fault_logic.py` executes the decision table — every state,
the precedence between them, the NE43 boundaries and the calibration maths,
including the degenerate case where both calibration points are captured at
the same current. It reads the thresholds **out of the package YAML**, so
changing a substitution cannot silently desynchronise the test from the
firmware. 30 checks, and it needs nothing but Python.

## Things worth knowing

- **The loop is powered before firmware runs.** R15 is a 100 kΩ pull-up on
  `MT_EN`, so the 24 V comes up with the 3.3 V rail and stays up until ESPHome
  configures GPIO10. The instrument therefore still works with dead firmware —
  but *Loop power* is **not a safety interlock**, and must not be used as one.
- **A dead INA226 cannot masquerade as a live one.** ESPHome's `ina226`
  component does *not* publish NaN when an I²C read fails — it sets an internal
  warning and returns, leaving every sensor holding its last good value
  indefinitely. A staleness watchdog therefore stamps `millis()` on each
  successful read; more than 5 s without one forces `Fault: no sensor data` and
  drops the current and voltage to unknown. Without it, a cracked joint or a
  brown-out on the 3.3 V rail would leave the board reporting the last current
  it happened to see, forever — the worst failure an instrument can have,
  because it looks entirely plausible.
- **There is no user LED.** LED1 is hardwired across the 3.3 V rail. All status
  goes to Home Assistant; there is nothing to look at on the board itself.
- **Current comes from the shunt-voltage register**, not the chip's current
  register. The shunt LSB is exactly 2.5 µV, so the conversion is
  deterministic — 753 nA per count — with no integer calibration register
  rounding in the way.
- **4 MB flash, no PSRAM.** The build uses less than half the app partition,
  but anything that pulls in Bluetooth (`esp32_ble_tracker`, `bluetooth_proxy`,
  `esp32_improv`) will not leave room for OTA. Do not add `psram:`.
- **Mains hum is rejected by brute force.** The INA226 has no 50/60 Hz notch
  and no averaging length lands on a whole number of mains cycles, so the
  1100 µs × 128 conversion and the 5-deep median do the work instead.

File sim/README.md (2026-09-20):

# Limiter simulations (ngspice)

KiCad ships ngspice as a DLL; `ngs.py` drives it through ctypes, so no separate
simulator install is needed. Run each script with KiCad's Python:

    "C:\Program Files\KiCad\10.0\bin\python.exe" sim\1_limiter_iv_curve.py

| Script | Shows |
|---|---|
| `1_limiter_iv_curve.py` | Current the Rev F foldback limiter can deliver vs. output voltage, -20..85 C |
| `start.py` | Cold power-up into a 2-wire transmitter (works: LOOP_V tracks the rail up) |
| `recover.py` | Short removed / transmitter hot-plugged with the rail already at 24 V (locks up) |
| `3_proposed_fix.py` | Constant-current limiter (R19 removed, R16 18 ohm): limit vs. temperature, recovery |
| `4_reverse_conduction.py` | LOOP_V driven above the rail: Q1 conducts backwards long before D3 breaks down |
| `5_firmware_recovery.py` | A stuck Rev F loop released by pulsing MT_EN low |
| `6_rev_g_limiter.py` | Rev G as built: limit and terminal voltage vs. temperature with worst-case hFE, and zero reverse current with D4 |
| `7_usb_inrush.py` | Capacitance VBUS sees at attach, Rev F vs. the Rev G load switch (and why C12 is gate-to-source) |

Q1/Q2 use the Fairchild 2N5401/MMBT5401 Gummel-Poon model. The transmitter is
modelled generously -- zero current below its lift-off voltage, then whatever
it can get through 50 ohm up to its set point. A real transmitter draws
quiescent current below lift-off, which makes the lock-up worse, not better.

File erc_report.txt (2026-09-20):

ERC report (2026-09-20T18:17:41, Encoding UTF8)
Report includes: Errors, Warnings, Exclusions

***** Sheet /
[pin_to_pin]: Pins of type Unspecified and Unspecified are connected
    ; warning
    @(53.34 mm, 68.58 mm): Symbol J1 Pin 14 [EH, Unspecified, Line]
    @(71.12 mm, 68.58 mm): Symbol J1 Pin B1A12 [GND, Unspecified, Line]
[pin_to_pin]: Pins of type Unspecified and Power input are connected
    ; warning
    @(53.34 mm, 96.52 mm): Symbol J1 Pin 13 [EH, Unspecified, Line]
    @(46.99 mm, 109.22 mm): Symbol #PWR001 Pin 1 [Power input, Line]
[pin_to_pin]: Pins of type Unspecified and Power input are connected
    ; warning
    @(71.12 mm, 68.58 mm): Symbol J1 Pin B1A12 [GND, Unspecified, Line]
    @(46.99 mm, 109.22 mm): Symbol #PWR001 Pin 1 [Power input, Line]
[pin_to_pin]: Pins of type Unspecified and Power input are connected
    ; warning
    @(71.12 mm, 71.12 mm): Symbol J1 Pin B4A9 [VBUS, Unspecified, Line]
    @(80.01 mm, 71.12 mm): Symbol #PWR003 Pin 1 [Power input, Line]
[pin_to_pin]: Pins of type Unspecified and Passive are connected
    ; warning
    @(71.12 mm, 73.66 mm): Symbol J1 Pin B5 [CC2, Unspecified, Line]
    @(106.68 mm, 107.95 mm): Symbol R8 Pin 1 [Passive, Line]
[pin_to_pin]: Pins of type Unspecified and Unspecified are connected
    ; warning
    @(71.12 mm, 78.74 mm): Symbol J1 Pin B6 [Dp2, Unspecified, Line]
    @(342.90 mm, 109.22 mm): Symbol U1 Pin 14 [IO20, Unspecified, Line]
[pin_to_pin]: Pins of type Unspecified and Unspecified are connected
    ; warning
    @(71.12 mm, 81.28 mm): Symbol J1 Pin A7 [Dn1, Unspecified, Line]
    @(71.12 mm, 86.36 mm): Symbol J1 Pin B7 [Dn2, Unspecified, Line]
[pin_to_pin]: Pins of type Unspecified and Unspecified are connected
    ; warning
    @(71.12 mm, 83.82 mm): Symbol J1 Pin A6 [Dp1, Unspecified, Line]
    @(71.12 mm, 78.74 mm): Symbol J1 Pin B6 [Dp2, Unspecified, Line]
[pin_to_pin]: Pins of type Unspecified and Unspecified are connected
    ; warning
    @(71.12 mm, 86.36 mm): Symbol J1 Pin B7 [Dn2, Unspecified, Line]
    @(342.90 mm, 106.68 mm): Symbol U1 Pin 13 [IO19, Unspecified, Line]
[pin_to_pin]: Pins of type Unspecified and Passive are connected
    ; warning
    @(71.12 mm, 88.90 mm): Symbol J1 Pin A5 [CC1, Unspecified, Line]
    @(93.98 mm, 107.95 mm): Symbol R7 Pin 1 [Passive, Line]
[pin_to_pin]: Pins of type Unspecified and Power input are connected
    ; warning
    @(71.12 mm, 93.98 mm): Symbol J1 Pin A4B9 [VBUS, Unspecified, Line]
    @(80.01 mm, 93.98 mm): Symbol #PWR005 Pin 1 [Power input, Line]
[pin_to_pin]: Pins of type Unspecified and Power input are connected
    ; warning
    @(71.12 mm, 96.52 mm): Symbol J1 Pin A1B12 [GND, Unspecified, Line]
    @(46.99 mm, 109.22 mm): Symbol #PWR001 Pin 1 [Power input, Line]
[pin_to_pin]: Pins of type Unspecified and Unspecified are connected
    ; warning
    @(115.57 mm, 69.85 mm): Symbol D1 Pin 6 [I/O1, Unspecified, Line]
    @(71.12 mm, 78.74 mm): Symbol J1 Pin B6 [Dp2, Unspecified, Line]
[pin_to_pin]: Pins of type Unspecified and Unspecified are connected
    ; warning
    @(115.57 mm, 92.71 mm): Symbol D1 Pin 1 [I/O1, Unspecified, Line]
    @(115.57 mm, 69.85 mm): Symbol D1 Pin 6 [I/O1, Unspecified, Line]
[pin_to_pin]: Pins of type Unspecified and Power input are connected
    ; warning
    @(118.11 mm, 69.85 mm): Symbol D1 Pin 5 [VBUS, Unspecified, Line]
    @(118.11 mm, 67.31 mm): Symbol #PWR009 Pin 1 [Power input, Line]
[pin_to_pin]: Pins of type Unspecified and Power input are connected
    ; warning
    @(118.11 mm, 92.71 mm): Symbol D1 Pin 2 [GND, Unspecified, Line]
    @(118.11 mm, 95.25 mm): Symbol #PWR008 Pin 1 [Power input, Line]
[pin_to_pin]: Pins of type Unspecified and Unspecified are connected
    ; warning
    @(120.65 mm, 69.85 mm): Symbol D1 Pin 4 [I/O2, Unspecified, Line]
    @(71.12 mm, 81.28 mm): Symbol J1 Pin A7 [Dn1, Unspecified, Line]
[pin_to_pin]: Pins of type Unspecified and Unspecified are connected
    ; warning
    @(120.65 mm, 92.71 mm): Symbol D1 Pin 3 [I/O2, Unspecified, Line]
    @(120.65 mm, 69.85 mm): Symbol D1 Pin 4 [I/O2, Unspecified, Line]
[pin_to_pin]: Pins of type Unspecified and Passive are connected
    ; warning
    @(130.81 mm, 207.01 mm): Symbol L1 Pin 1 [1, Unspecified, Line]
    @(114.30 mm, 210.82 mm): Symbol C10 Pin 1 [Passive, Line]
[pin_to_pin]: Pins of type Unspecified and Unspecified are connected
    ; warning
    @(140.97 mm, 207.01 mm): Symbol L1 Pin 2 [2, Unspecified, Line]
    @(171.45 mm, 224.79 mm): Symbol U5 Pin 1 [SW, Unspecified, Line]
[pin_to_pin]: Pins of type Unspecified and Unspecified are connected
    ; warning
    @(151.13 mm, 219.71 mm): Symbol U5 Pin 4 [EN, Unspecified, Line]
    @(151.13 mm, 222.25 mm): Symbol U5 Pin 5 [IN, Unspecified, Line]
[pin_to_pin]: Pins of type Unspecified and Passive are connected
    ; warning
    @(151.13 mm, 222.25 mm): Symbol U5 Pin 5 [IN, Unspecified, Line]
    @(114.30 mm, 210.82 mm): Symbol C10 Pin 1 [Passive, Line]
[pin_to_pin]: Pins of type Unspecified and Passive are connected
    ; warning
    @(171.45 mm, 219.71 mm): Symbol U5 Pin 3 [FB, Unspecified, Line]
    @(207.01 mm, 223.52 mm): Symbol R10 Pin 2 [Passive, Line]
[pin_to_pin]: Pins of type Unspecified and Power input are connected
    ; warning
    @(171.45 mm, 222.25 mm): Symbol U5 Pin 2 [GND, Unspecified, Line]
    @(184.15 mm, 232.41 mm): Symbol #PWR036 Pin 1 [Power input, Line]
[pin_to_pin]: Pins of type Unspecified and Unspecified are connected
    ; warning
    @(176.53 mm, 72.39 mm): Symbol U4 Pin 1 [VIN, Unspecified, Line]
    @(176.53 mm, 77.47 mm): Symbol U4 Pin 3 [EN, Unspecified, Line]
[pin_to_pin]: Pins of type Unspecified and Passive are connected
    ; warning
    @(176.53 mm, 74.93 mm): Symbol U4 Pin 2 [GND, Unspecified, Line]
    @(170.18 mm, 82.55 mm): Symbol C6 Pin 2 [Passive, Line]
[pin_to_pin]: Pins of type Unspecified and Power input are connected
    ; warning
    @(176.53 mm, 77.47 mm): Symbol U4 Pin 3 [EN, Unspecified, Line]
    @(173.99 mm, 77.47 mm): Symbol #PWR012 Pin 1 [Power input, Line]
[pin_to_pin]: Pins of type Unspecified and Unspecified are connected
    ; warning
    @(181.61 mm, 207.01 mm): Symbol D2 Pin 2 [A, Unspecified, Line]
    @(171.45 mm, 224.79 mm): Symbol U5 Pin 1 [SW, Unspecified, Line]
[pin_to_pin]: Pins of type Unspecified and Passive are connected
    ; warning
    @(191.77 mm, 207.01 mm): Symbol D2 Pin 1 [K, Unspecified, Line]
    @(207.01 mm, 215.90 mm): Symbol R10 Pin 1 [Passive, Line]
[pin_to_pin]: Pins of type Unspecified and Passive are connected
    ; warning
    @(201.93 mm, 72.39 mm): Symbol U4 Pin 5 [VOUT, Unspecified, Line]
    @(224.79 mm, 74.93 mm): Symbol C7 Pin 1 [Passive, Line]
[pin_to_pin]: Pins of type Unspecified and Unspecified are connected
    ; warning
    @(321.31 mm, 90.17 mm): Symbol SW1 Pin 1 [1, Unspecified, Line]
    @(321.31 mm, 95.25 mm): Symbol SW1 Pin 3 [3, Unspecified, Line]
[pin_to_pin]: Pins of type Unspecified and Passive are connected
    ; warning
    @(321.31 mm, 95.25 mm): Symbol SW1 Pin 3 [3, Unspecified, Line]
    @(316.23 mm, 77.47 mm): Symbol R1 Pin 2 [Passive, Line]
[pin_to_pin]: Pins of type Unspecified and Unspecified are connected
    ; warning
    @(331.47 mm, 90.17 mm): Symbol SW1 Pin 2 [2, Unspecified, Line]
    @(331.47 mm, 95.25 mm): Symbol SW1 Pin 4 [4, Unspecified, Line]
[pin_to_pin]: Pins of type Unspecified and Power input are connected
    ; warning
    @(331.47 mm, 95.25 mm): Symbol SW1 Pin 4 [4, Unspecified, Line]
    @(335.28 mm, 99.06 mm): Symbol #PWR023 Pin 1 [Power input, Line]
[pin_to_pin]: Pins of type Unspecified and Unspecified are connected
    ; warning
    @(342.90 mm, 76.20 mm): Symbol U1 Pin 1 [GND, Unspecified, Line]
    @(354.33 mm, 71.12 mm): Symbol U1 Pin 41 [GND, Unspecified, Line]
[pin_to_pin]: Pins of type Unspecified and Power input are connected
    ; warning
    @(342.90 mm, 78.74 mm): Symbol U1 Pin 2 [3V3, Unspecified, Line]
    @(335.28 mm, 78.74 mm): Symbol #PWR020 Pin 1 [Power input, Line]
[pin_to_pin]: Pins of type Unspecified and Passive are connected
    ; warning
    @(342.90 mm, 81.28 mm): Symbol U1 Pin 3 [EN, Unspecified, Line]
    @(316.23 mm, 77.47 mm): Symbol R1 Pin 2 [Passive, Line]
[pin_to_pin]: Pins of type Unspecified and Passive are connected
    ; warning
    @(342.90 mm, 104.14 mm): Symbol U1 Pin 12 [IO8, Unspecified, Line]
    @(290.83 mm, 95.25 mm): Symbol R5 Pin 2 [Passive, Line]
[pin_to_pin]: Pins of type Unspecified and Passive are connected
    ; warning
    @(342.90 mm, 116.84 mm): Symbol U1 Pin 17 [IO9, Unspecified, Line]
    @(273.05 mm, 95.25 mm): Symbol R6 Pin 2 [Passive, Line]
[pin_to_pin]: Pins of type Unspecified and Passive are connected
    ; warning
    @(342.90 mm, 119.38 mm): Symbol U1 Pin 18 [IO10, Unspecified, Line]
    @(129.54 mm, 229.87 mm): Symbol R15 Pin 2 [Passive, Line]
[pin_to_pin]: Pins of type Unspecified and Power input are connected
    ; warning
    @(354.33 mm, 71.12 mm): Symbol U1 Pin 41 [GND, Unspecified, Line]
    @(335.28 mm, 99.06 mm): Symbol #PWR023 Pin 1 [Power input, Line]
[pin_to_pin]: Pins of type Unspecified and Unspecified are connected
    ; warning
    @(365.76 mm, 76.20 mm): Symbol U1 Pin 40 [GND, Unspecified, Line]
    @(354.33 mm, 71.12 mm): Symbol U1 Pin 41 [GND, Unspecified, Line]
[pin_to_pin]: Pins of type Unspecified and Unspecified are connected
    ; warning
    @(374.65 mm, 135.89 mm): Symbol SW2 Pin 1 [1, Unspecified, Line]
    @(374.65 mm, 140.97 mm): Symbol SW2 Pin 3 [3, Unspecified, Line]
[pin_to_pin]: Pins of type Unspecified and Unspecified are connected
    ; warning
    @(374.65 mm, 140.97 mm): Symbol SW2 Pin 3 [3, Unspecified, Line]
    @(365.76 mm, 109.22 mm): Symbol U1 Pin 27 [IO0, Unspecified, Line]
[pin_to_pin]: Pins of type Unspecified and Unspecified are connected
    ; warning
    @(384.81 mm, 135.89 mm): Symbol SW2 Pin 2 [2, Unspecified, Line]
    @(384.81 mm, 140.97 mm): Symbol SW2 Pin 4 [4, Unspecified, Line]
[pin_to_pin]: Pins of type Unspecified and Power input are connected
    ; warning
    @(384.81 mm, 140.97 mm): Symbol SW2 Pin 4 [4, Unspecified, Line]
    @(389.89 mm, 144.78 mm): Symbol #PWR026 Pin 1 [Power input, Line]
[pin_to_pin]: Pins of type Unspecified and Unspecified are connected
    ; warning
    @(439.42 mm, 199.39 mm): Symbol U3 Pin 1 [A1, Unspecified, Line]
    @(439.42 mm, 201.93 mm): Symbol U3 Pin 2 [A0, Unspecified, Line]
[pin_to_pin]: Pins of type Unspecified and Power input are connected
    ; warning
    @(439.42 mm, 201.93 mm): Symbol U3 Pin 2 [A0, Unspecified, Line]
    @(429.26 mm, 199.39 mm): Symbol #PWR044 Pin 1 [Power input, Line]
[pin_to_pin]: Pins of type Unspecified and Passive are connected
    ; warning
    @(439.42 mm, 207.01 mm): Symbol U3 Pin 4 [SDA, Unspecified, Line]
    @(290.83 mm, 95.25 mm): Symbol R5 Pin 2 [Passive, Line]
[pin_to_pin]: Pins of type Unspecified and Passive are connected
    ; warning
    @(439.42 mm, 209.55 mm): Symbol U3 Pin 5 [SCL, Unspecified, Line]
    @(273.05 mm, 95.25 mm): Symbol R6 Pin 2 [Passive, Line]
[pin_to_pin]: Pins of type Unspecified and Passive are connected
    ; warning
    @(464.82 mm, 199.39 mm): Symbol U3 Pin 10 [VIN+, Unspecified, Line]
    @(483.87 mm, 218.44 mm): Symbol C9 Pin 1 [Passive, Line]
[pin_to_pin]: Pins of type Unspecified and Passive are connected
    ; warning
    @(464.82 mm, 201.93 mm): Symbol U3 Pin 9 [VIN-, Unspecified, Line]
    @(483.87 mm, 226.06 mm): Symbol C9 Pin 2 [Passive, Line]
[pin_to_pin]: Pins of type Unspecified and Passive are connected
    ; warning
    @(464.82 mm, 204.47 mm): Symbol U3 Pin 8 [VBUS, Unspecified, Line]
    @(486.41 mm, 187.96 mm): Symbol R20 Pin 2 [Passive, Line]
[pin_to_pin]: Pins of type Unspecified and Power input are connected
    ; warning
    @(464.82 mm, 207.01 mm): Symbol U3 Pin 7 [GND, Unspecified, Line]
    @(476.25 mm, 219.71 mm): Symbol #PWR047 Pin 1 [Power input, Line]
[pin_to_pin]: Pins of type Unspecified and Power input are connected
    ; warning
    @(464.82 mm, 209.55 mm): Symbol U3 Pin 6 [VS+, Unspecified, Line]
    @(468.63 mm, 214.63 mm): Symbol #PWR045 Pin 1 [Power input, Line]
[pin_to_pin]: Pins of type Unspecified and Passive are connected
    ; warning
    @(525.78 mm, 195.58 mm): Symbol D3 Pin 1 [C, Unspecified, Line]
    @(537.21 mm, 190.50 mm): Symbol J2 Pin 3 [3, Passive, Line]
[pin_to_pin]: Pins of type Unspecified and Power input are connected
    ; warning
    @(525.78 mm, 205.74 mm): Symbol D3 Pin 2 [A, Unspecified, Line]
    @(525.78 mm, 209.55 mm): Symbol #PWR050 Pin 1 [Power input, Line]
[pin_to_pin]: Pins of type Unspecified and Passive are connected
    ; warning
    @(525.78 mm, 222.25 mm): Symbol D5 Pin 1 [C, Unspecified, Line]
    @(502.92 mm, 222.25 mm): Symbol R12 Pin 1 [Passive, Line]
[pin_to_pin]: Pins of type Unspecified and Power input are connected
    ; warning
    @(525.78 mm, 232.41 mm): Symbol D5 Pin 2 [A, Unspecified, Line]
    @(525.78 mm, 236.22 mm): Symbol #PWR051 Pin 1 [Power input, Line]

 ** ERC messages: 59  Errors 0  Warnings 59

 ** Ignored checks:
    - Global label only appears once in the schematic
    - Four connection points are joined together
    - SPICE model issue
    - Assigned footprint doesn't match footprint filters

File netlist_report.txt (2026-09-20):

==============================================================================
ESP32 4-20 mA ESPHome Sensor Board -- connectivity report
Generated from generate_schematic.py; regenerate with netlist_report.py
==============================================================================

SECTION 1 -- COMPONENTS

Ref    Schematic block    Value                  LCSC       MPN
------------------------------------------------------------------------------
C1     Microcontroller    1uF                    C52923     CL05A105KA5NQNC
C2     Microcontroller    22uF                   C45783     CL21A226MAQNNNE
C3     Microcontroller    100nF                  C1525      CL05B104KO5NNNC
C6     Power Input        1uF                    C52923     CL05A105KA5NQNC
C7     Power Input        10uF                   C19702     CL10A106KP8NNNC
C8     4-20 Ma Loop       100nF                  C1525      CL05B104KO5NNNC
C9     4-20 Ma Loop       100nF                  C1525      CL05B104KO5NNNC
C10    24 V Loop Supply   10uF/50V               C2918502   CS3225X7R106K500NRL
C11    24 V Loop Supply   10uF/50V               C2918502   CS3225X7R106K500NRL
C12    24 V Loop Supply   100nF                  C1525      CL05B104KO5NNNC
D1     Power Input        USBLC6-2SC6            C2687116   USBLC6-2SC6
D2     24 V Loop Supply   SS34                   C8678      SS34
D3     4-20 Ma Loop       SMAJ28A                C353458    SMAJ28A
D4     4-20 Ma Loop       1N4148W                C81598     1N4148W
D5     4-20 Ma Loop       SMAJ12A                C113957    SMAJ12A
J1     Power Input        USB-C Receptacle       C2765186   TYPE-C 16PIN 2MD(073)
J2     4-20 Ma Loop       4-20mA Loop            C976567    KF250NH-5.0-3P
L1     24 V Loop Supply   22uH                   C167883    FNR4030S220MT
LED1   Power Input        Power                  C84256     NCD0805R1
Q1     4-20 Ma Loop       BCP53-16               C148109    BCP53-16
Q2     4-20 Ma Loop       MMBT5401               C8326      MMBT5401
Q3     24 V Loop Supply   AO3401A                C15127     AO3401A
Q4     24 V Loop Supply   2N7002                 C8545      2N7002
R1     Microcontroller    10k                    C25744     0402WGF1002TCE
R5     Microcontroller    4.7k                   C25900     0402WGF4701TCE
R6     Microcontroller    4.7k                   C25900     0402WGF4701TCE
R7     Power Input        5.1k                   C25905     0402WGF5101TCE
R8     Power Input        5.1k                   C25905     0402WGF5101TCE
R9     Power Input        330                    C25104     0402WGF3300TCE
R10    24 V Loop Supply   390k                   C2909352   FRC0402F3903TS
R11    24 V Loop Supply   10k                    C25744     0402WGF1002TCE
R12    4-20 Ma Loop       3.32                   C3013220   FRC0805F3R32TS
R13    4-20 Ma Loop       10                     C25077     0402WGF100JTCE
R14    4-20 Ma Loop       10                     C25077     0402WGF100JTCE
R15    24 V Loop Supply   100k                   C25741     0402WGF1003TCE
R16    4-20 Ma Loop       18                     C138043    RC0402FR-0718RL
R17    4-20 Ma Loop       47k                    C25792     0402WGF4702TCE
R18    4-20 Ma Loop       1k                     C11702     0402WGF1001TCE
R20    4-20 Ma Loop       10k                    C25744     0402WGF1002TCE
R21    24 V Loop Supply   390k                   C2909352   FRC0402F3903TS
R22    24 V Loop Supply   100k                   C25741     0402WGF1003TCE
SW1    Microcontroller    RESET                  C2837531   KH-6X6X5H-STM
SW2    Microcontroller    BOOT                   C2837531   KH-6X6X5H-STM
TP1    24 V Loop Supply   LOOP_V                 --         (test point, not in BOM)
TP2    24 V Loop Supply   LOOP_RTN               --         (test point, not in BOM)
TP3    24 V Loop Supply   +24V                   --         (test point, not in BOM)
TP4    24 V Loop Supply   +3V3                   --         (test point, not in BOM)
TP5    24 V Loop Supply   MT_EN                  --         (test point, not in BOM)
U1     Microcontroller    ESP32-S3-WROOM-1U-N4   C2980296   ESP32-S3-WROOM-1U-N4
U3     4-20 Ma Loop       INA226AIDGSR           C49851     INA226AIDGSR
U4     Power Input        AP2112K-3.3            C51118     AP2112K-3.3TRG1
U5     24 V Loop Supply   MT3608                 C84817     MT3608

SECTION 2 -- PIN CONNECTIONS

For each pin: the net it sits on, and the other pins on that net.
Pins on GND show only 'GND' -- the full ground membership is in Section 3.

--- C1  (1uF)  block: Microcontroller
   pin 1                   EN         U1.3 (EN), R1.2 (), SW1.1 (1), SW1.3 (3)
   pin 2                   GND        

--- C2  (22uF)  block: Microcontroller
   pin 1                   +3V3       U1.2 (3V3), U3.6 (VS+), U4.5 (VOUT), R1.1 (), R5.1 (), R6.1 (), R9.1 (), R15.1 (), C3.1 (), C7.1 (), C8.1 (), TP4.1 (1)
   pin 2                   GND        

--- C3  (100nF)  block: Microcontroller
   pin 1                   +3V3       U1.2 (3V3), U3.6 (VS+), U4.5 (VOUT), R1.1 (), R5.1 (), R6.1 (), R9.1 (), R15.1 (), C2.1 (), C7.1 (), C8.1 (), TP4.1 (1)
   pin 2                   GND        

--- C6  (1uF)  block: Power Input
   pin 1                   +5V        U4.1 (VIN), U4.3 (EN), J1.A4B9 (VBUS), J1.B4A9 (VBUS), D1.5 (VBUS), Q3.2 (S), R21.1 (), C12.1 ()
   pin 2                   GND        

--- C7  (10uF)  block: Power Input
   pin 1                   +3V3       U1.2 (3V3), U3.6 (VS+), U4.5 (VOUT), R1.1 (), R5.1 (), R6.1 (), R9.1 (), R15.1 (), C2.1 (), C3.1 (), C8.1 (), TP4.1 (1)
   pin 2                   GND        

--- C8  (100nF)  block: 4-20 Ma Loop
   pin 1                   +3V3       U1.2 (3V3), U3.6 (VS+), U4.5 (VOUT), R1.1 (), R5.1 (), R6.1 (), R9.1 (), R15.1 (), C2.1 (), C3.1 (), C7.1 (), TP4.1 (1)
   pin 2                   GND        

--- C9  (100nF)  block: 4-20 Ma Loop
   pin 1                   INA_INP    R13.2 (), U3.10 (VIN+)
   pin 2                   INA_INN    R14.2 (), U3.9 (VIN-)

--- C10  (10uF/50V)  block: 24 V Loop Supply
   pin 1                   VIN_SW     Q3.3 (D), U5.5 (IN), U5.4 (EN), L1.1 (1)
   pin 2                   GND        

--- C11  (10uF/50V)  block: 24 V Loop Supply
   pin 1                   +24V       D2.1 (K), R10.1 (), R16.1 (), Q2.2 (E), TP3.1 (1)
   pin 2                   GND        

--- C12  (100nF)  block: 24 V Loop Supply
   pin 1                   +5V        U4.1 (VIN), U4.3 (EN), J1.A4B9 (VBUS), J1.B4A9 (VBUS), D1.5 (VBUS), C6.1 (), Q3.2 (S), R21.1 ()
   pin 2                   SW_GATE    Q3.1 (G), R21.2 (), R22.1 ()

--- D1  (USBLC6-2SC6)  block: Power Input
   pin 1      I/O1         USB_P      J1.A6 (Dp1), J1.B6 (Dp2), D1.6 (I/O1), U1.14 (IO20)
   pin 2      GND          GND        
   pin 3      I/O2         USB_N      J1.A7 (Dn1), J1.B7 (Dn2), D1.4 (I/O2), U1.13 (IO19)
   pin 4      I/O2         USB_N      J1.A7 (Dn1), J1.B7 (Dn2), D1.3 (I/O2), U1.13 (IO19)
   pin 5      VBUS         +5V        U4.1 (VIN), U4.3 (EN), J1.A4B9 (VBUS), J1.B4A9 (VBUS), C6.1 (), Q3.2 (S), R21.1 (), C12.1 ()
   pin 6      I/O1         USB_P      J1.A6 (Dp1), J1.B6 (Dp2), D1.1 (I/O1), U1.14 (IO20)

--- D2  (SS34)  block: 24 V Loop Supply
   pin 1      K            +24V       C11.1 (), R10.1 (), R16.1 (), Q2.2 (E), TP3.1 (1)
   pin 2      A            MT_SW      U5.1 (SW), L1.2 (2)

--- D3  (SMAJ28A)  block: 4-20 Ma Loop
   pin 1      C            LOOP_V     D4.1 (K), J2.3 (3), R20.1 (), TP1.1 (1)
   pin 2      A            GND        

--- D4  (1N4148W)  block: 4-20 Ma Loop
   pin 1      K            LOOP_V     J2.3 (3), D3.1 (C), R20.1 (), TP1.1 (1)
   pin 2      A            LOOP_C     Q1.2 (C), Q1.4 (C)

--- D5  (SMAJ12A)  block: 4-20 Ma Loop
   pin 1      C            LOOP_RTN   J2.2 (2), R12.1 (), R13.1 (), TP2.1 (1)
   pin 2      A            GND        

--- J1  (USB-C Receptacle)  block: Power Input
   pin 13     EH           GND        
   pin 14     EH           GND        
   pin A1B12  GND          GND        
   pin A4B9   VBUS         +5V        U4.1 (VIN), U4.3 (EN), J1.B4A9 (VBUS), D1.5 (VBUS), C6.1 (), Q3.2 (S), R21.1 (), C12.1 ()
   pin A5     CC1          CC1        R7.1 ()
   pin A6     Dp1          USB_P      J1.B6 (Dp2), D1.1 (I/O1), D1.6 (I/O1), U1.14 (IO20)
   pin A7     Dn1          USB_N      J1.B7 (Dn2), D1.3 (I/O2), D1.4 (I/O2), U1.13 (IO19)
   pin A8     SBU1         (NC)       -- not connected --
   pin B1A12  GND          GND        
   pin B4A9   VBUS         +5V        U4.1 (VIN), U4.3 (EN), J1.A4B9 (VBUS), D1.5 (VBUS), C6.1 (), Q3.2 (S), R21.1 (), C12.1 ()
   pin B5     CC2          CC2        R8.1 ()
   pin B6     Dp2          USB_P      J1.A6 (Dp1), D1.1 (I/O1), D1.6 (I/O1), U1.14 (IO20)
   pin B7     Dn2          USB_N      J1.A7 (Dn1), D1.3 (I/O2), D1.4 (I/O2), U1.13 (IO19)
   pin B8     SBU2         (NC)       -- not connected --

--- J2  (4-20mA Loop)  block: 4-20 Ma Loop
   pin 1      1            GND        
   pin 2      2            LOOP_RTN   R12.1 (), R13.1 (), D5.1 (C), TP2.1 (1)
   pin 3      3            LOOP_V     D4.1 (K), D3.1 (C), R20.1 (), TP1.1 (1)

--- L1  (22uH)  block: 24 V Loop Supply
   pin 1      1            VIN_SW     Q3.3 (D), U5.5 (IN), U5.4 (EN), C10.1 ()
   pin 2      2            MT_SW      U5.1 (SW), D2.2 (A)

--- LED1  (Power)  block: Power Input
   pin 1      K            GND        
   pin 2      A            LED_A      R9.2 ()

--- Q1  (BCP53-16)  block: 4-20 Ma Loop
   pin 1      B            LOOP_DRV   Q2.3 (C), R17.1 ()
   pin 2      C            LOOP_C     Q1.4 (C), D4.2 (A)
   pin 3      E            LOOP_SNS   R16.2 (), R18.1 ()
   pin 4      C            LOOP_C     Q1.2 (C), D4.2 (A)

--- Q2  (MMBT5401)  block: 4-20 Ma Loop
   pin 1      B            LOOP_FB    R18.2 ()
   pin 2      E            +24V       D2.1 (K), C11.1 (), R10.1 (), R16.1 (), TP3.1 (1)
   pin 3      C            LOOP_DRV   Q1.1 (B), R17.1 ()

--- Q3  (AO3401A)  block: 24 V Loop Supply
   pin 1      G            SW_GATE    R21.2 (), C12.2 (), R22.1 ()
   pin 2      S            +5V        U4.1 (VIN), U4.3 (EN), J1.A4B9 (VBUS), J1.B4A9 (VBUS), D1.5 (VBUS), C6.1 (), R21.1 (), C12.1 ()
   pin 3      D            VIN_SW     U5.5 (IN), U5.4 (EN), L1.1 (1), C10.1 ()

--- Q4  (2N7002)  block: 24 V Loop Supply
   pin 1      G            MT_EN      U1.18 (IO10), R15.2 (), TP5.1 (1)
   pin 2      S            GND        
   pin 3      D            SW_PD      R22.2 ()

--- R1  (10k)  block: Microcontroller
   pin 1                   +3V3       U1.2 (3V3), U3.6 (VS+), U4.5 (VOUT), R5.1 (), R6.1 (), R9.1 (), R15.1 (), C2.1 (), C3.1 (), C7.1 (), C8.1 (), TP4.1 (1)
   pin 2                   EN         U1.3 (EN), SW1.1 (1), SW1.3 (3), C1.1 ()

--- R5  (4.7k)  block: Microcontroller
   pin 1                   +3V3       U1.2 (3V3), U3.6 (VS+), U4.5 (VOUT), R1.1 (), R6.1 (), R9.1 (), R15.1 (), C2.1 (), C3.1 (), C7.1 (), C8.1 (), TP4.1 (1)
   pin 2                   I2C_SDA    U1.12 (IO8), U3.4 (SDA)

--- R6  (4.7k)  block: Microcontroller
   pin 1                   +3V3       U1.2 (3V3), U3.6 (VS+), U4.5 (VOUT), R1.1 (), R5.1 (), R9.1 (), R15.1 (), C2.1 (), C3.1 (), C7.1 (), C8.1 (), TP4.1 (1)
   pin 2                   I2C_SCL    U1.17 (IO9), U3.5 (SCL)

--- R7  (5.1k)  block: Power Input
   pin 1                   CC1        J1.A5 (CC1)
   pin 2                   GND        

--- R8  (5.1k)  block: Power Input
   pin 1                   CC2        J1.B5 (CC2)
   pin 2                   GND        

--- R9  (330)  block: Power Input
   pin 1                   +3V3       U1.2 (3V3), U3.6 (VS+), U4.5 (VOUT), R1.1 (), R5.1 (), R6.1 (), R15.1 (), C2.1 (), C3.1 (), C7.1 (), C8.1 (), TP4.1 (1)
   pin 2                   LED_A      LED1.2 (A)

--- R10  (390k)  block: 24 V Loop Supply
   pin 1                   +24V       D2.1 (K), C11.1 (), R16.1 (), Q2.2 (E), TP3.1 (1)
   pin 2                   MT_FB      U5.3 (FB), R11.1 ()

--- R11  (10k)  block: 24 V Loop Supply
   pin 1                   MT_FB      U5.3 (FB), R10.2 ()
   pin 2                   GND        

--- R12  (3.32)  block: 4-20 Ma Loop
   pin 1                   LOOP_RTN   J2.2 (2), R13.1 (), D5.1 (C), TP2.1 (1)
   pin 2                   GND        

--- R13  (10)  block: 4-20 Ma Loop
   pin 1                   LOOP_RTN   J2.2 (2), R12.1 (), D5.1 (C), TP2.1 (1)
   pin 2                   INA_INP    U3.10 (VIN+), C9.1 ()

--- R14  (10)  block: 4-20 Ma Loop
   pin 1                   GND        
   pin 2                   INA_INN    U3.9 (VIN-), C9.2 ()

--- R15  (100k)  block: 24 V Loop Supply
   pin 1                   +3V3       U1.2 (3V3), U3.6 (VS+), U4.5 (VOUT), R1.1 (), R5.1 (), R6.1 (), R9.1 (), C2.1 (), C3.1 (), C7.1 (), C8.1 (), TP4.1 (1)
   pin 2                   MT_EN      U1.18 (IO10), Q4.1 (G), TP5.1 (1)

--- R16  (18)  block: 4-20 Ma Loop
   pin 1                   +24V       D2.1 (K), C11.1 (), R10.1 (), Q2.2 (E), TP3.1 (1)
   pin 2                   LOOP_SNS   Q1.3 (E), R18.1 ()

--- R17  (47k)  block: 4-20 Ma Loop
   pin 1                   LOOP_DRV   Q1.1 (B), Q2.3 (C)
   pin 2                   GND        

--- R18  (1k)  block: 4-20 Ma Loop
   pin 1                   LOOP_SNS   R16.2 (), Q1.3 (E)
   pin 2                   LOOP_FB    Q2.1 (B)

--- R20  (10k)  block: 4-20 Ma Loop
   pin 1                   LOOP_V     D4.1 (K), J2.3 (3), D3.1 (C), TP1.1 (1)
   pin 2                   INA_VBUS   U3.8 (VBUS)

--- R21  (390k)  block: 24 V Loop Supply
   pin 1                   +5V        U4.1 (VIN), U4.3 (EN), J1.A4B9 (VBUS), J1.B4A9 (VBUS), D1.5 (VBUS), C6.1 (), Q3.2 (S), C12.1 ()
   pin 2                   SW_GATE    Q3.1 (G), C12.2 (), R22.1 ()

--- R22  (100k)  block: 24 V Loop Supply
   pin 1                   SW_GATE    Q3.1 (G), R21.2 (), C12.2 ()
   pin 2                   SW_PD      Q4.3 (D)

--- SW1  (RESET)  block: Microcontroller
   pin 1      1            EN         U1.3 (EN), R1.2 (), SW1.3 (3), C1.1 ()
   pin 2      2            GND        
   pin 3      3            EN         U1.3 (EN), R1.2 (), SW1.1 (1), C1.1 ()
   pin 4      4            GND        

--- SW2  (BOOT)  block: Microcontroller
   pin 1      1            IO0        U1.27 (IO0), SW2.3 (3)
   pin 2      2            GND        
   pin 3      3            IO0        U1.27 (IO0), SW2.1 (1)
   pin 4      4            GND        

--- TP1  (LOOP_V)  block: 24 V Loop Supply
   pin 1      1            LOOP_V     D4.1 (K), J2.3 (3), D3.1 (C), R20.1 ()

--- TP2  (LOOP_RTN)  block: 24 V Loop Supply
   pin 1      1            LOOP_RTN   J2.2 (2), R12.1 (), R13.1 (), D5.1 (C)

--- TP3  (+24V)  block: 24 V Loop Supply
   pin 1      1            +24V       D2.1 (K), C11.1 (), R10.1 (), R16.1 (), Q2.2 (E)

--- TP4  (+3V3)  block: 24 V Loop Supply
   pin 1      1            +3V3       U1.2 (3V3), U3.6 (VS+), U4.5 (VOUT), R1.1 (), R5.1 (), R6.1 (), R9.1 (), R15.1 (), C2.1 (), C3.1 (), C7.1 (), C8.1 ()

--- TP5  (MT_EN)  block: 24 V Loop Supply
   pin 1      1            MT_EN      U1.18 (IO10), Q4.1 (G), R15.2 ()

--- U1  (ESP32-S3-WROOM-1U-N4)  block: Microcontroller
   pin 1      GND          GND        
   pin 2      3V3          +3V3       U3.6 (VS+), U4.5 (VOUT), R1.1 (), R5.1 (), R6.1 (), R9.1 (), R15.1 (), C2.1 (), C3.1 (), C7.1 (), C8.1 (), TP4.1 (1)
   pin 3      EN           EN         R1.2 (), SW1.1 (1), SW1.3 (3), C1.1 ()
   pin 4      IO4          (NC)       -- not connected --
   pin 5      IO5          (NC)       -- not connected --
   pin 6      IO6          (NC)       -- not connected --
   pin 7      IO7          (NC)       -- not connected --
   pin 8      IO15         (NC)       -- not connected --
   pin 9      IO16         (NC)       -- not connected --
   pin 10     IO17         (NC)       -- not connected --
   pin 11     IO18         (NC)       -- not connected --
   pin 12     IO8          I2C_SDA    U3.4 (SDA), R5.2 ()
   pin 13     IO19         USB_N      J1.A7 (Dn1), J1.B7 (Dn2), D1.3 (I/O2), D1.4 (I/O2)
   pin 14     IO20         USB_P      J1.A6 (Dp1), J1.B6 (Dp2), D1.1 (I/O1), D1.6 (I/O1)
   pin 15     IO3          (NC)       -- not connected --
   pin 16     IO46         (NC)       -- not connected --
   pin 17     IO9          I2C_SCL    U3.5 (SCL), R6.2 ()
   pin 18     IO10         MT_EN      Q4.1 (G), R15.2 (), TP5.1 (1)
   pin 19     IO11         (NC)       -- not connected --
   pin 20     IO12         (NC)       -- not connected --
   pin 21     IO13         (NC)       -- not connected --
   pin 22     IO14         (NC)       -- not connected --
   pin 23     IO21         (NC)       -- not connected --
   pin 24     IO47         (NC)       -- not connected --
   pin 25     IO48         (NC)       -- not connected --
   pin 26     IO45         (NC)       -- not connected --
   pin 27     IO0          IO0        SW2.1 (1), SW2.3 (3)
   pin 28     IO35         (NC)       -- not connected --
   pin 29     IO36         (NC)       -- not connected --
   pin 30     IO37         (NC)       -- not connected --
   pin 31     IO38         (NC)       -- not connected --
   pin 32     IO39         (NC)       -- not connected --
   pin 33     IO40         (NC)       -- not connected --
   pin 34     IO41         (NC)       -- not connected --
   pin 35     IO42         (NC)       -- not connected --
   pin 36     RXD0         (NC)       -- not connected --
   pin 37     TXD0         (NC)       -- not connected --
   pin 38     IO2          (NC)       -- not connected --
   pin 39     IO1          (NC)       -- not connected --
   pin 40     GND          GND        
   pin 41     GND          GND        

--- U3  (INA226AIDGSR)  block: 4-20 Ma Loop
   pin 1      A1           GND        
   pin 2      A0           GND        
   pin 3      Alert        (NC)       -- not connected --
   pin 4      SDA          I2C_SDA    U1.12 (IO8), R5.2 ()
   pin 5      SCL          I2C_SCL    U1.17 (IO9), R6.2 ()
   pin 6      VS+          +3V3       U1.2 (3V3), U4.5 (VOUT), R1.1 (), R5.1 (), R6.1 (), R9.1 (), R15.1 (), C2.1 (), C3.1 (), C7.1 (), C8.1 (), TP4.1 (1)
   pin 7      GND          GND        
   pin 8      VBUS         INA_VBUS   R20.2 ()
   pin 9      VIN-         INA_INN    R14.2 (), C9.2 ()
   pin 10     VIN+         INA_INP    R13.2 (), C9.1 ()

--- U4  (AP2112K-3.3)  block: Power Input
   pin 1      VIN          +5V        U4.3 (EN), J1.A4B9 (VBUS), J1.B4A9 (VBUS), D1.5 (VBUS), C6.1 (), Q3.2 (S), R21.1 (), C12.1 ()
   pin 2      GND          GND        
   pin 3      EN           +5V        U4.1 (VIN), J1.A4B9 (VBUS), J1.B4A9 (VBUS), D1.5 (VBUS), C6.1 (), Q3.2 (S), R21.1 (), C12.1 ()
   pin 4      NC           (NC)       -- not connected --
   pin 5      VOUT         +3V3       U1.2 (3V3), U3.6 (VS+), R1.1 (), R5.1 (), R6.1 (), R9.1 (), R15.1 (), C2.1 (), C3.1 (), C7.1 (), C8.1 (), TP4.1 (1)

--- U5  (MT3608)  block: 24 V Loop Supply
   pin 1      SW           MT_SW      L1.2 (2), D2.2 (A)
   pin 2      GND          GND        
   pin 3      FB           MT_FB      R10.2 (), R11.1 ()
   pin 4      EN           VIN_SW     Q3.3 (D), U5.5 (IN), L1.1 (1), C10.1 ()
   pin 5      IN           VIN_SW     Q3.3 (D), U5.4 (EN), L1.1 (1), C10.1 ()
   pin 6      NC           (NC)       -- not connected --

SECTION 3 -- NETS

+24V  (6 pins)
   C11.1, D2.1, Q2.2, R10.1, R16.1, TP3.1

+3V3  (13 pins)
   C2.1, C3.1, C7.1, C8.1, R1.1, R5.1, R6.1, R9.1, R15.1, TP4.1, U1.2, U3.6, U4.5

+5V  (9 pins)
   C6.1, C12.1, D1.5, J1.A4B9, J1.B4A9, Q3.2, R21.1, U4.1, U4.3

GND  (36 pins)
   C1.2, C2.2, C3.2, C6.2, C7.2, C8.2, C10.2, C11.2, D1.2, D3.2, D5.2, J1.A1B12, J1.B1A12, J1.13, J1.14, J2.1, LED1.1, Q4.2, R7.2, R8.2, R11.2, R12.2, R14.1, R17.2, SW1.2, SW1.4, SW2.2, SW2.4, U1.1, U1.40, U1.41, U3.1, U3.2, U3.7, U4.2, U5.2

CC1  (2 pins)
   J1.A5, R7.1

CC2  (2 pins)
   J1.B5, R8.1

EN  (5 pins)
   C1.1, R1.2, SW1.1, SW1.3, U1.3

I2C_SCL  (3 pins)
   R6.2, U1.17, U3.5

I2C_SDA  (3 pins)
   R5.2, U1.12, U3.4

INA_INN  (3 pins)
   C9.2, R14.2, U3.9

INA_INP  (3 pins)
   C9.1, R13.2, U3.10

INA_VBUS  (2 pins)
   R20.2, U3.8

IO0  (3 pins)
   SW2.1, SW2.3, U1.27

LED_A  (2 pins)
   LED1.2, R9.2

LOOP_C  (3 pins)
   D4.2, Q1.2, Q1.4

LOOP_DRV  (3 pins)
   Q1.1, Q2.3, R17.1

LOOP_FB  (2 pins)
   Q2.1, R18.2

LOOP_RTN  (5 pins)
   D5.1, J2.2, R12.1, R13.1, TP2.1

LOOP_SNS  (3 pins)
   Q1.3, R16.2, R18.1

LOOP_V  (5 pins)
   D3.1, D4.1, J2.3, R20.1, TP1.1

MT_EN  (4 pins)
   Q4.1, R15.2, TP5.1, U1.18

MT_FB  (3 pins)
   R10.2, R11.1, U5.3

MT_SW  (3 pins)
   D2.2, L1.2, U5.1

SW_GATE  (4 pins)
   C12.2, Q3.1, R21.2, R22.1

SW_PD  (2 pins)
   Q4.3, R22.2

USB_N  (5 pins)
   D1.3, D1.4, J1.A7, J1.B7, U1.13

USB_P  (5 pins)
   D1.1, D1.6, J1.A6, J1.B6, U1.14

VIN_SW  (5 pins)
   C10.1, L1.1, Q3.3, U5.5, U5.4

SECTION 4 -- NOTES FOR REWORK

Layout
  One A3 sheet, four blocks in signal-flow order:
    Power Input      USB-C input, ESD clamp, AP2112K 3.3 V LDO, power LED
    Microcontroller  ESP32-S3-WROOM-1-N4, reset/boot buttons, I2C pull-ups
    24 V Loop Supply MT3608 boost, 5 V -> 24 V loop supply
    4-20 Ma Loop     loop terminal, 4.02 ohm shunt, INA226 current monitor

Power rails are power-port symbols (global nets). Blocks connect by net label:
USB_P/USB_N (USB-C -> ESP32-S3) and I2C_SDA/I2C_SCL (ESP32-S3 -> INA226).

Polarity / orientation
  D2  SS34 Schottky: cathode (pin 1) to +24V, anode (pin 2) to the switch node.
  D3  SMAJ36A TVS: cathode (pin 1) to +24V, anode (pin 2) to the loop return.
  LED1 anode (pin 2) from R9, cathode (pin 1) to GND.
  R13 pin 2 is the INA226 side; R14 pin 1 is the ground side.

ESP32-S3 strapping pins -- do not repurpose without checking
  IO0  (pin 27) internal pull-up; SW2 pulls it low for download mode.
  IO46 (pin 16) internal pull-down; must stay low at reset. Left NC.
  IO45 (pin 26) VDD_SPI select; must stay low on the -N4 module. Left NC.
  IO3  (pin 15) no internal pull; JTAG source select only. Left NC.

Calculated values
  R10/R11  MT3608 feedback: Vout = 0.6 x (1 + 390k/10k) = 24.00 V
  R12      shunt: 20 mA x 4.02 ohm = 80.4 mV = 98% of INA226 full scale
  R7/R8    USB-C CC pulldowns, 5.1 k = UFP advertising default current
  R5/R6    I2C pull-ups, 4.7 k for 400 kHz on a short single-target bus
  R9       LED: (3.3 - 1.9) / 330 = 4.2 mA

Two-pin nets (CC1, CC2, LED_A, MT_SW, MT_FB, INA_INP, INA_INN, LOOP_RTN) are
point-to-point and can be rerouted freely. GND, +3V3, +5V and +24V are shared
rails -- check Section 3 before moving anything on them.

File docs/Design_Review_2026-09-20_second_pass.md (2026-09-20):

# ESP32 4-20 mA Sensor Board — Second-Pass Design Review

**Date:** 2026-09-20 · **Reviewed:** Rev F as on disk (46 footprints, placed, unrouted) · **Resolved in:** Rev G
**Scope:** an independent pass over the whole design. The first review
(`Design_Review_2026-09-20.md`) was read only to avoid repeating it; its
conclusions were not taken as given.

## Resolution — Rev G, same day

Everything below was fixed except **M-1 (shunt grade), which the designer
accepted**: 0.8 % of reading over a 40 °C swing is within what this board is
for. If that changes, the fix is a drop-in 0805.

| # | Status | What was done |
|---|---|---|
| C-1 | **Fixed** | R19 removed, R16 → 18 Ω (`C138043`), Q1 → BCP53-16 SOT-223 (`C148109`). Simulated with worst-case hFE and D4 in circuit: 35 / 33 / 30 / 27 mA at −20 / 25 / 60 / 85 °C, 22.8 V at J2 at 20 mA (`sim/6_rev_g_limiter.py`) |
| H-1 | **Fixed** | D4 1N4148W (`C81598`) in series after Q1; D3 → SMAJ28A (`C353458`). Reverse current into the rail is zero out to 46 V |
| H-2 | **Fixed** | D3 re-referenced to GND; new D5 SMAJ12A (`C113957`) from `LOOP_RTN` to GND. Each within 6 mm of its terminal pin |
| M-1 | **Accepted** | No change, by decision |
| M-2 | **Fixed** | U3 turned so IN+/IN− face the shunt, as TI's Figure 30. C8 is now 1.5 mm from VS and 2.2 mm from GND (was 8.0 mm, wrong side); C9 1.8 mm from the input pins |
| M-3 | **Fixed** | Boost laid out as the MT3608 datasheet's Figure 3. Switched-current loop 26 → 19 mm round, 28 → 19 mm²; C11's ground 9.7 → 3.8 mm from U5's. The SMA diode's own length is now what sets it — a SOD-123 Schottky would shrink it further, not done |
| M-4 | **Fixed** | `pcblib.sync_footprints()` swaps a footprint whose ID no longer matches its symbol and can prune orphans; `Board.drc()` runs with `--schematic-parity`. Both the project and skill copies. Parity is clean |
| L-1 | **Fixed** | Title block Rev G, 2026-09-20; stale docstring corrected |
| L-2 | **Fixed** | Soft-start load switch Q3/Q4/R21/R22/C12. VBUS sees 1.0 µF at attach, down from 26.8. My first version (Miller capacitor) failed in simulation and was replaced — see `sim/7_usb_inrush.py` |
| L-3 | **Fixed** | Top M2 holes moved to y = 16.8 mm: 19 mm from the antenna, 1.8 mm clear of the button pads for a 4.6 mm standoff |
| L-4 | **Fixed** | L1 → 22 µH `FNR4030S220MT` (`C167883`), same footprint, Isat 1.2 A |
| L-5 | **Fixed** | J2 is 3-pin. (First as a pluggable `C8412`; replaced the same day by the one-piece push-in block below, which also changed the pin order) |
| L-6 | **Documented** | Two-point calibration and the loop-voltage validity check are firmware requirements, stated at the top of the README |

**Found on the way**, all fixed:

- The SMA and FNR4030 footprints drew their courtyards round the body and left
  the pads outside. A courtyard-legal layout put two TVS diodes dead against a
  test pad and DRC reported `shorting_items`. Both courtyards now enclose the
  pads.
- `schlib` mis-ordered properties when flattening a symbol that `extends`
  another and adds fields its parent lacks (`Transistor_FET:AO3401A`), failing
  the native-format check. Fixed in both copies.
- `tidy_references` treated only pads and silk as obstacles, so it printed
  R12's designator in the middle of the SOT-223. It now avoids other parts'
  courtyards and searches upright text and further out.

**Verified end state:** 28 nets / 35 no-connects exact match, ERC 0 errors,
0 wire crossings, 0 text problems, native format matches KiCad's own save;
schematic parity clean, placement DRC 5 (all deliberate silk-at-edge) + 5
library-internal, no overlaps, placement deterministic across runs; BOM 34
lines / 47 placements.

**Two part changes requested after the review, same day:**

- **U1 → ESP32-S3-WROOM-1U-N4** (`C2980296`), U.FL connector. The board was
  deliberately left untouched so the PCB-antenna module can be refitted: the
  two modules share one land pattern in Espressif's datasheet, so the new
  footprint reuses the existing pads and origin exactly. Reverting is one line.
  The radio now depends on the pigtail and antenna in `bom/non-bom-items.csv`.
- **J2 → KEFA KF250NH-5.0-3P** (`C976567`), a one-piece push-in spring
  terminal. Footprint, symbol and 3D model came from LCSC/EasyEDA and were
  checked against KEFA's drawing before use. Pinout is now **1 = GND,
  2 = mA in, 3 = +24 V out**, left to right looking into the wire entry, which
  keeps +24 V under the limiter and GND beside D5 with nothing crossing behind
  the block. The mating plug is no longer needed. Push-in is for solid or
  ferruled wire; bare stranded needs the button held while inserting.

State after both: 28 nets exact, ERC 0 errors, parity clean, placement DRC 4
(all silk-at-edge) + 5 library-internal, BOM 34 lines / 47 placements.

**Routed, same day.** `setup_fab.py` + `route_board.py`: critical nets scripted
(boost per MT3608 Figure 3, Kelvin taps per INA226 Figure 30, USB entry, power
trunks, the 24 V loop, Q1's copper, all ground vias and both pours), the rest by
Freerouting 2.4.1 and replayed from `routing/autoroute.json`. 0 unconnected, DRC
unchanged at 4 + 5, parity clean, bottom ground in one piece, no via in any pad,
reproducible. What was listed below as routing advice is now what the board
does; it is kept as the record of why. Still open: nothing has been measured.

**Still open — all of it routing:** no copper, so EMC and thermal remain
provisional. When routing: pour `LOOP_C` around Q1's tab and stitch it through;
ground pour on both layers, stitched round the boost; keep the pour back from
the top edge; run IN+/IN− as a pair from R12's pads.

---

## The review as written (Rev F)

**Verdict: do not route yet.** Two circuit changes (C-1, H-1) alter the parts
list and the placement, so routing now would be routing the wrong board.

| # | Severity | Finding | Evidence |
|---|---|---|---|
| C-1 | **Critical** | Foldback limiter can lock a transmitter at ~9 V and report a plausible but wrong current | ngspice |
| H-1 | **High** | A surge on `LOOP_V` goes backwards through Q1 into the 24 V rail; D3 never gets to clamp | datasheet + ngspice |
| H-2 | Medium-High | `LOOP_RTN` has no clamp to ground; a common-mode surge reaches the INA226 inputs through 10 Ω | circuit analysis |
| M-1 | Medium | Shunt is 1 % / ±200 ppm/°C — it, not the INA226, sets the accuracy | LCSC parametrics |
| M-2 | Medium | INA226 bypass cap `C8` is 8 mm from the VS pin, on the wrong side of the chip | measured from board |
| M-3 | Medium | Boost hot loop encloses 28 mm²; SW pin has only 5.5 V of headroom | measured + datasheet |
| M-4 | Medium | Board carries 1.5 mm test pads; schematic and docs say 1.0 mm | `kicad-cli pcb drc --schematic-parity` |
| L-1…L-6 | Low | Stale title block, USB inrush capacitance, metal screws by the antenna, inductor value, 2-wire-only terminal, calibration | see below |

---

## C-1. The foldback limiter locks up into a constant-current load

A foldback limiter and a 4-20 mA transmitter are a bad pairing, for a textbook
reason: foldback assumes the load draws *less* as the voltage falls. A loop
transmitter draws the *same* current at any voltage above its lift-off, and
when starved it saturates and takes everything on offer. So the two curves can
cross twice — once at the proper operating point near 23 V, and once part-way
down the foldback slope — and the lower crossing is stable.

What the limiter can actually deliver (`sim/1_limiter_iv_curve.py`):

| `LOOP_V` | −20 °C | 25 °C | 50 °C | 70 °C | 85 °C |
|---|---|---|---|---|---|
| 0 V (short) | 8.2 mA | 4.0 mA | 1.6 mA | **0** | **0** |
| 8 V | 17.0 | 13.0 | 10.6 | 8.7 | 7.3 |
| 12 V | 21.4 | 17.4 | 15.1 | 13.2 | 11.8 |
| 23 V | 32.6 | 29.3 | 27.1 | 25.3 | 24.0 |

The short-circuit current is `(Vbe − 24 V × 1/44) / 20 Ω` — the small difference
of two ~0.6 V numbers, one of which moves −2 mV/°C. It is 4 mA at 25 °C and
**zero from about 65 °C up** (the 0.55 mA left is R19's own divider current;
Q1 is fully off).

The consequence, short removed or a discharged transmitter plugged into a live
J2, rail already at 24 V (`sim/recover.py`, lift-off 8 V):

| Process demand | 0 °C | 25 °C | 50 °C | 70 °C |
|---|---|---|---|---|
| 4–8 mA | ok | ok | ok | ok |
| 12 mA | ok | ok | **8.6 V / 11.3 mA** | **8.5 V / 9.3 mA** |
| 16 mA | ok | **8.7 V / 13.8 mA** | stuck | stuck |
| 20–22 mA | **8.9 V / 16.2 mA** | **8.7 V / 13.8 mA** | stuck | stuck |

The board then reports 13.8 mA while the process is at 20 mA. Nothing looks
broken. For a measuring instrument that is the worst available failure mode.
Cases near the boundary (for example 12 V lift-off, 20 mA, 25 °C) went either
way between runs — on real hardware those will be decided by part tolerance.

Cold power-up is fine (`sim/start.py`): `LOOP_V` tracks the rail up and Vce
never gets large. That is why the first review's "doubles as a soft start"
reads as true — it only examined that case. The model is also generous: it
gives the transmitter zero current below lift-off. Real ones draw quiescent
current there, which makes this worse.

**Fix (recommended) — constant-current limit, bigger pass transistor:**

| Change | From | To |
|---|---|---|
| `R19` | 43 k | **remove** (this is the foldback) |
| `R16` | 20 Ω | **18 Ω** — holds ≥ 27 mA at 85 °C so a 24 mA over-range still reads |
| `Q1` | MMBT5401, SOT-23, 0.3 W | **BCP53-16, SOT-223, 1.5 W** — LCSC `C148109`, 91 k in stock. Pinout 1 = B, 2/4 = C, 3 = E |
| `R18` | 1 k | keep — it now just limits Q2's base current |

Simulated (`sim/3_proposed_fix.py`): limit 37 / 33 / 30 / 27 mA at
−20 / 25 / 60 / 85 °C, recovery correct at every temperature and lift-off
tested. A dead short costs Q1 0.66–0.89 W, which is what the SOT-223 is for —
give its tab a few cm² of copper. This also retires M-1 from the first review
on its merits rather than by acceptance.

There is no way to keep the SOT-23: any limiter that delivers 22 mA at a 10 V
output must drop 14 V × 22 mA ≈ 0.3 W in the pass device at that point.

**Firmware, do this regardless:** the INA226 already reads `LOOP_V`. If it is
below ~20 V while the current is above 3.5 mA, the reading is invalid — flag
it. On Rev F boards that is also the recovery: pulse `MT_EN` low for ~0.5 s and
the loop restarts cleanly (`sim/5_firmware_recovery.py`, all four cases
recover). With the hardware fix, the same check becomes a short-circuit alarm,
and dropping `MT_EN` during a short cuts Q1 to 4.6 V × 33 mA = 0.15 W.

---

## H-1. Surge on `LOOP_V` goes backwards through Q1; D3 never clamps

D3 (SMAJ36A) starts conducting at 40 V. But `LOOP_V` is Q1's collector, and a
PNP's collector-base junction is a diode: once `LOOP_V` passes ~25 V it
forward-biases, lifts the base, and at about 7 V of reverse bias Q1's
emitter-base junction avalanches (V(BR)EBO is 5 V minimum). From there the
surge has a path into the +24 V rail through nothing but R16's 20 Ω.

`sim/4_reverse_conduction.py`: 40 mA reverse at 28 V, 100 mA at 32 V, then
amps — all before D3 reaches breakdown. What takes the surge instead:

- **Q1's emitter-base junction** in avalanche, which permanently degrades hFE
  even when it survives;
- **C11 and the rail** — ~5 µF effective at 24 V bias, pumped upward, with
  **U5's SW pin rated 30 V absolute maximum** (MT3608 datasheet) sitting one
  Schottky drop away.

Removing R19 for C-1 closes the other reverse path (`LOOP_V` → R19 → Q2's
collector-base → rail).

**Fix:** a series diode, anode at Q1's collector, cathode to `LOOP_V`.
**1N4148W**, SOD-123, LCSC `C81598`, JLCPCB basic, 75 V reverse. It carries at
most the 37 mA limit and costs ~0.7 V, leaving ~22.6 V at the terminal —
still far above any transmitter's lift-off plus cable drop. Not an SS34: a
40 V Schottky would see 58 − 24 = 34 V in reverse at D3's clamp, too close.

Worth doing at the same time: **D3 → SMAJ28A** (`C353458`; 28 V stand-off
against a 24.7 V worst-case rail, clamps at 45 V instead of 58 V). That is
kinder to the transmitter, which is typically rated 30–36 V, and to U3's bus
pin.

## H-2. `LOOP_RTN` has no clamp to ground

D3 sits *across* the terminal, so it handles differential surges only. A
common-mode surge — both field wires lifted against board ground, the usual
case on a long cable — returns through `LOOP_RTN` → R12 → GND. The INA226
inputs see `I × 3.32 Ω` through only 10 Ω: 12 A is enough to pass their 40 V
absolute maximum, and R12 is an 0805.

**Fix:** re-reference D3 from `LOOP_V` to **GND**, and add a second TVS from
`LOOP_RTN` to GND — **SMAJ12A** (`C113957`), which clamps under 20 V and at
80 mV of normal bias leaks nanoamps, so it costs no accuracy. Bonus: D3's
leakage currently flows through the shunt and is measured as loop current;
referenced to ground it no longer is.

Severity depends on where this gets installed. On a bench with a metre of
cable, low. On a plant floor, high. The first review calls the board
"industrial", so I have rated it for that.

---

## M-1. The shunt sets the accuracy, and it is the wrong grade

`R12` (`C3013220`) is thick film, **±1 %, ±200 ppm/°C**. The INA226 it feeds
is 0.1 % with 10 µV offset. A one-point calibration removes the 1 %; nothing
removes the drift — 40 °C of enclosure swing is **0.8 % of reading**, roughly
eight times everything else in the chain combined.

**Fix:** thin film, 0.1 %, ≤ 25 ppm/°C, same 0805 footprint. 3.3 Ω is a
standard value and moves full scale from 24.67 to 24.82 mA. I could not
confirm a specific in-stock LCSC number — the parametric search was returning
errors — so this one needs sourcing by hand.

## M-2. C8 is not decoupling U3

U3 is rotated 180°, so VS (pin 6) and GND (pin 7) are on its **south** side at
(26.05, 46.66) and (26.55, 46.66). C8 is at (31.5, 40.4): north-east of the
chip, **8.0 mm** from the pin it serves. It wants to be within ~2 mm, west of
pins 6/7 — about where TP1 is now. TP1 can move; C8 cannot.

## M-3. Boost hot loop

The loop that carries the switched current — U5.SW → D2 → C11 → GND → U5.GND —
measures **26 mm around and 28 mm² enclosed**; C11's ground pad is 9.7 mm from
U5's. With SW at 24.5 V against a **30 V absolute maximum**, ringing has 5.5 V
of headroom, and loop inductance is what sets the ringing. It is also 10 mm
from a part resolving 2.5 µV, on two layers.

**Fix:** put C11 directly between D2's cathode and U5 pin 2, so the loop closes
in a few millimetres. C11 and D2 can swap sides: C11 at roughly (31, 37.5),
D2 rotated to land its cathode on it. Then re-run placement DRC.

## M-4. The board has the wrong test-point footprint

`kicad-cli pcb drc --schematic-parity` reports five `footprint_symbol_mismatch`:
the board holds `TestPoint_Pad_D1.5mm`, the schematic `D1.0mm`. The README,
the first review and the comment in `place_components.py` all say 1.5 mm was
rejected. It was rejected in the schematic only.

Cause: `pcblib.sync_footprints()` imports parts the board *lacks*, and
`refresh_footprints()` reloads each by the ID the board *already has*. Nothing
compares the symbol's Footprint field to the board's, so a changed footprint
never propagates. Every clearance quoted for TP1/TP2 was measured with the
larger pad. **Fix:** make `sync_footprints()` replace a footprint whose ID
differs from its symbol's, and add `--schematic-parity` to `Board.drc()` so
this class of error cannot hide again.

---

## Low

- **L-1. The schematic says Rev C, 2026-09-10.** `generate_schematic.py` has
  `REV = "C"`, and its docstring still says "one A3 sheet" and "33 parts". The
  PDF delivered today carries that title block. The design is Rev F, A2, 46
  parts.
- **L-2. ~21 µF on VBUS at plug-in** (C6 + C10, plus C11 through L1/D2, which
  a boost cannot disconnect) against USB's 10 µF limit. Works on every real
  host; not compliant.
- **L-3. Metal M2 hardware level with the antenna.** H1/H2 are 9.6 mm from
  the module's flanks. Espressif asks for ~15 mm clear of metal. Nylon screws
  and standoffs at the top pair, or move them down beside the buttons.
- **L-4. L1 = 4.7 µH is the bottom of the MT3608's 4.7–22 µH range.** At
  0.17 A average input the converter is deep in discontinuous mode with
  ~0.7 A peaks. 22 µH in the same FNR4030 footprint cuts peak current and
  ripple about fourfold — worthwhile next to a µV measurement.
- **L-5. Two-wire sensors only.** J2 has no GND pin, so a 3-wire or
  self-powered (sourcing) 4-20 mA output cannot be connected at all. A 3-pin
  terminal — `LOOP_V`, `LOOP_RTN`, `GND` — adds that for one pin.
- **L-6. Calibrate at two points.** R13/R14 interact with the INA226's input
  bias network, and R20 costs 1.19 % on the bus reading. Both are fixed
  scalars, but this datasheet revision does not give the figure for the first,
  so measure it: 4 mA and 20 mA from a reference source.

## Checked and correct

ESP32-S3 pin assignments (IO8/IO9 I²C, IO19/IO20 USB, IO10 enable, strapping
pins) · INA226 pinout and 0x40 address · MT3608 pinout, 0.6 V reference,
24.00 V divider, 79 % duty against a 90 % limit · AP2112K pinout and output
capacitance · USB-C CC pull-downs · USBLC6 pinout · EN reset RC · netlist
matches the specification exactly (24 nets, 35 no-connects) · ERC 0 errors ·
DRC unchanged at 6 placement + 5 library · `C2913197` really is the -N4.

Analyzer false positives, all three: `PU-001` (Alert is open-drain and
deliberately unused), `UC-002` (USBLC6 pin 5 is on VBUS), `VM-001` (`MT_EN`
is pulled to 3.3 V and the MT3608's EN threshold is 1.5 V — no level shifter
needed).

## Correction to the first review

It states SPICE "was not performed" because no simulator is installed. KiCad
ships ngspice as `bin/ngspice.dll`. `sim/ngs.py` drives it through ctypes;
every simulation cited here is reproducible from `sim/`.

## Not done

No routing exists, so EMC and thermal remain provisional, as before. No gerber
review. Lifecycle data is still unavailable without distributor API keys.
Surge behaviour is analysed and simulated at DC, not against an IEC 61000-4-5
waveform.

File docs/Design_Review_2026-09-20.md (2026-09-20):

# ESP32 4-20 mA Sensor Board — Design Review

**Project:** esp32-4to20ma-board (KiCad 10.0, single A2 sheet, 2-layer PCB, placed but unrouted)
**Date:** 2026-09-20
**Revision reviewed:** Rev E — adds the foldback current limiter, moves the INA226 bus tap to the field side, applies JLCPCB fabrication rules
**Analyzers run:** `analyze_schematic.py`, `analyze_pcb.py --full`, `cross_analysis.py`, `analyze_emc.py`, `analyze_thermal.py`, `lifecycle_audit.py`, `summarize_findings.py` (run folder `analysis/2026-09-20_1224`)

---

## Update — 2026-09-20, later the same day

Three of the five blockers below have been closed. The findings are left in
place, annotated, so the reasoning stays readable rather than being edited out
of history.

| Was | Now |
|---|---|
| **H-1** INA226 VBUS over-voltage | **FIXED** — `R20`, 10 kΩ 0402 (`C25744`, same part as R1/R11, so no new BOM line) in series from `LOOP_V` to `U3` pin 8. New net `INA_VBUS`. Placed at (31.00, 44.00) mm |
| **F-4 / UC-002** VBUS ESD unconfirmed | **RESOLVED — false positive, datasheet-verified.** See the corrected entry below |
| **FD-001** no fiducials | **FIXED** — `FID1`/`FID2`/`FID3` at (4, 7), (36, 7), (36, 54) mm |
| **M-1** Q1 thermal margin | **closed — risk accepted by the designer**, 2026-09-20 |
| **TE-001** no test points | **DONE** — TP1-TP5 on `LOOP_V`, `LOOP_RTN`, `+24V`, `+3V3`, `MT_EN` |
| **GP-002 / VS-001** no ground plane, no stitching | still open — resolve at routing |
| **J1 hole clearance** | **closed** — board rule relaxed 0.25 → 0.20 mm, JLCPCB's own published NPTH-to-track minimum. See below |

Netlist re-verified after the change: 24 nets, 35 no-connects, exact match to
the specification. DRC is now **7 placement-level** and **7 library-internal**,
with 101 unconnected items pending routing. Five of the seven are the
deliberate `silk_edge_clearance` warnings on J1 and U1. The other two —
`C8`/`R18` at 0.11 mm and `C9`/`R13` clipped by a mask opening — are
reference-designator artefacts, cosmetic, and **not** attributable to R20,
whose own designator is pinned by hand and clear. I could not originally claim
they pre-dated this change, because `pcblib`'s `tidy_references` was not
idempotent. **That has since been fixed** — it ordered parts by a bounding box
that included the reference text, and since every 0402 has the same extent the
tie fell through to KiCad's footprint write order, which changes on every save.
It now sorts on pads/silk/courtyard only, with the reference as tie-break.
Three consecutive runs now give byte-identical designator positions, and the
placement DRC count is a stable 7.

Test points (TE-001) **have since been added** — see below.

### Test points added, same day

Five 1.0 mm bare pads, each within a few mm of the net it probes so the stub
stays short on a two-layer board:

| Ref | Net | Position (mm) | Sits by |
|---|---|---|---|
| TP1 | `LOOP_V` | 24.00, 46.75 | between U3 and the TVS |
| TP2 | `LOOP_RTN` | 22.00, 50.25 | the clear area west of the TVS |
| TP3 | `+24V` | 21.00, 34.00 | the boost output cap |
| TP4 | `+3V3` | 11.50, 35.00 | the LDO output, beside C7 |
| TP5 | `MT_EN` | 20.00, 26.50 | under R15's pull-up |

They carry `in_bom=False`, so the BOM stays at **30 order lines** against 41
placements. 1.5 mm pads were tried first and rejected: the extra courtyard
pushed TP1 and TP2 out of the pockets beside the parts they probe.

**One cosmetic cost, stated plainly:** TP2's designator grazes J2's and R13's
silkscreen by 0.07-0.09 mm. That corner of the board holds the shunt, the
Kelvin taps, the TVS and the terminal, and it has room for the pad but not for
a third designator. Silk-on-silk is a printing nicety, not an electrical or
assembly problem, and the alternative — moving TP2 into open copper 7 mm away
— would have cost a real stub trace on a dense two-layer board. Placement DRC
is therefore **6** — down from 7 — and library-internal DRC is **5**.

TP2 was first placed in that pocket and moved out to (22.00, 50.25). Two
reasons: its designator had nowhere readable to go, printing on top of R13's,
and a probe wedged 0.6 mm from the terminal block risks shorting to J2. The
stub out to it carries no current, so the only cost is a little copper. R13's
designator is pinned by hand at (33.90, 50.41), 1.6 mm from its own pad, which
freed the contested gap for D3 and also cleared a `silk_over_copper` on C9.

---

### Found while checking the render, same day

Reviewing the 3D render turned up a defect none of the analyzers, DRC or the
netlist diff could see, because all of them work from the 2D layers:

**J2's footprint had a 5.00 mm pad pitch on a 5.08 mm part.** `C8445` is
`WJ2EDGVC-5.08-02P`; LCSC's parametrics state `P=5.08mm`. The pads sat at
±2.50 mm instead of ±2.54 mm — 0.08 mm narrow across the pair. With a 1.70 mm
drill it would still have assembled, which is precisely why nothing flagged it.
Fixed to ±2.54 mm.

Three 3D models were also misplaced — **cosmetic for fabrication**, since
gerbers, drill, paste and the CPL all derive from the 2D layers, but disabling
for mechanical and enclosure work: U1 by 3.70 mm in Y (the footprint origin is
the centre of the pad array, not of the module body, because the antenna end
carries no pads), J1 by 1.19 mm in Y, and J2 by 2.54 mm in X (the Phoenix
stand-in's origin is on pin 1). All three now agree with their silkscreen
outlines to within 0.2 mm, verified by measuring the rendered bodies rather
than by eye.

**The copper was checked and is correct.** U1's pads match Espressif's land
pattern (1.27 mm pitch, three rows, 19.3 × 19.1 mm extent) and J1's match the
16-pin USB-C 2MD pattern (0.5 mm pitch, ±3.2 mm outer pads).
`render/pcb_top_pad_overlay.png` shows the render with the real pad rectangles
drawn over it.

---

## Overview

Single-channel industrial 4-20 mA current-loop reader. USB-C in, AP2112K LDO for
3.3 V, MT3608 boost for the 24 V loop supply, foldback current limiter feeding a
pluggable field terminal, low-side shunt read by an INA226 over I²C, ESP32-S3
module with the antenna cantilevered off the board edge.

40 components, 31 unique parts, 58 nets, 40 × 61 mm two-layer board. 44
footprints on the PCB — the four extra are NPTH mounting holes, which have no
schematic symbol by design.

**Bottom line:** the design is internally clean — 0 ERC errors, the drawn netlist
matches its maintained specification exactly, 100 % MPN coverage, and every IC
pinout I could check against a manufacturer PDF is correct. One finding is worth
fixing before fabrication: the INA226's bus-voltage pin sits on the field side of
the terminal with no series resistance, where the TVS can clamp above the pin's
absolute maximum. A second is a thermal margin that disappears at the top of the
temperature range. Neither is a show-stopper, and both have cheap fixes.

The board is **not ready to fabricate**, but only because it is not routed —
there is no copper, no ground plane and no stitching yet. Those are the next
step, not defects.

---

## Critical Findings

### H-1. The INA226's VBUS pin can be driven past its absolute maximum by the TVS

**Severity: HIGH — FIXED 2026-09-20. Evidence: datasheet-verified.**

> **Resolved.** `R20` (10 kΩ, 0402, `C25744`) now sits between `LOOP_V` and
> `U3` pin 8, creating the net `INA_VBUS`. The analysis below is the reasoning
> that led to it, kept as written.

`U3` pin 8 (VBUS) connects directly to `LOOP_V`, the field-side node, with no
series resistance. That node is clamped by `D3` (SMAJ36A).

| Quantity | Value | Source |
|---|---|---|
| INA226 V_VBUS absolute maximum | **−0.3 V to 40 V** | INA226 datasheet §6.1 Absolute Maximum Ratings |
| INA226 input current into any pin | **±5 mA** | same table |
| SMAJ36A breakdown voltage V_BR | **40 V minimum** | SMAJ36A datasheet (Littelfuse / Bourns) |
| SMAJ36A clamping voltage V_C | **58.1 V at I_PP 6.9 A**, 10/1000 µs | same |

So the TVS only *begins* conducting at the INA226's absolute maximum, and under
a real surge it holds the node as high as 58 V — about 18 V beyond the rating,
with nothing to limit the current into the pin's internal clamp.

Note this is a **pre-existing topology issue, not something Rev E introduced**.
Before the limiter, `+24V` *was* the field node, so pin 8 had the same exposure.
Moving the tap to `LOOP_V` kept it.

The differential inputs are already protected: `R13`/`R14` (10 Ω) are the series
elements TI's own input-protection network calls for. VBUS simply never got the
same treatment.

**Fix:** a series resistor from `LOOP_V` to `U3` pin 8. 10 kΩ limits the clamp
current to (58.1 − 40)/10 k ≈ **1.8 mA**, inside the ±5 mA pin rating. The cost
is a gain error on the bus reading: VBUS input impedance is **830 kΩ**
(datasheet §6.5), so 10 kΩ in series is a **1.19 %** error. That reading is a
diagnostic, not the measurement, and the error is a fixed scalar you can
calibrate out in firmware.

### M-1. Q1 has almost no thermal margin during a sustained short at high ambient

> **Closed 2026-09-20 — risk accepted by the designer.** No change made. The
> analysis below stands as written; it is recorded here so the decision is
> traceable rather than forgotten. If the enclosure is later specified above
> ~60 °C ambient, re-open it.

**Severity: MEDIUM. Evidence: datasheet-verified figures, hand calculation.**

The foldback holds a dead short at ~5 mA with ~23.9 V across `Q1`, so it
dissipates **≈ 0.128 W** continuously for as long as the fault persists.

| Quantity | Value | Source |
|---|---|---|
| P_D at 25 °C (LCSC C8326, JSCJ) | 300 mW | LCSC listing for C8326 |
| P_D at 25 °C (onsemi MMBT5401) | 350 mW | onsemi MMBT5401 datasheet |
| Derating | 2.8 mW/°C | onsemi datasheet |

At 25 °C ambient, 0.128 W is a comfortable 43 % of the JSCJ part's rating. At
**85 °C ambient the derated rating is ~132 mW**, and 128 mW is **97 % of it** —
no margin, in the one condition (a shorted field pair, indefinitely) that the
circuit exists to survive.

**Fix, pick one:**
- Tighten the foldback — raising `R18` from 1 k to 1.2 k drops the short-circuit
  current to ~3 mA and the dissipation to ~0.07 W, at the cost of a lower
  start-up current into a capacitive transmitter.
- Move `Q1` to SOT-89 (e.g. a BCP-series PNP), roughly 500 mW–1 W.
- Accept it, and state a maximum ambient in the product documentation.

The choice depends on the enclosure's internal temperature, which I do not know.

---

## Component Summary

| Metric | Value |
|---|---|
| Components (schematic) | 40 |
| Unique parts | 31 |
| Nets | 58 |
| Components missing an MPN | **0** |
| PCB footprints | 44 (40 parts + 4 NPTH mounting holes) |
| SMD / THT | 39 / 1 (J2, the pluggable terminal) |
| Board | 40 × 61 mm, 2 layers |

100 % MPN and LCSC coverage — the sourcing gate (SS-001/002) does not fire.

---

## Power Tree

```
USB-C VBUS (5 V)
├── AP2112K (U4) ──> +3V3 ──> ESP32-S3 (U1), INA226 VS (U3), pull-ups
└── MT3608 boost (U5) ──> +24V ──> foldback limiter (R16/Q1/Q2/R17/R18/R19)
                                    └── LOOP_V ──> J2 field terminal, D3 TVS,
                                                   INA226 VBUS monitor
```

Rails detected and voltages resolved: `+24V` 24.0 V, `+5V` 5.0 V, `+3V3` 3.3 V,
`GND`. The analyzer's estimated +5 V load is 240 mA (U4 only); it does not model
the boost's input draw, so treat that as a floor, not a budget.

**Boost output, datasheet-verified:** MT3608 FB = 0.588 / **0.600** / 0.612 V
(datasheet electrical characteristics). With R10/R11 = 390 k/10 k,
V_out = 0.6 × (1 + 39) = **24.00 V** nominal, ±2 % from FB tolerance alone,
before resistor tolerance. Confirmed by the analyzer's own divider detection
(VD-DET, R10/R11).

---

## Analyzer Verification

### Component count
Schematic 40 / PCB 44. **Match**, once the four NPTH mounting holes — which are
board-only by construction and carry no symbol — are accounted for. `pcblib`
marks them excluded from BOM and position files, so they do not appear as
schematic-parity errors.

### Component pinout verification

Verified against manufacturer PDFs, not KiCad library symbols:

| Ref | Part | Pins checked | Source | Status |
|---|---|---|---|---|
| U5 | MT3608 | SW=1, GND=2, FB=3, EN=4, VIN=5, NC=6 | MT3608 datasheet, pin-description table | **Datasheet-verified — matches** |
| U3 | INA226 | A1=1, A0=2, Alert=3, SDA=4, SCL=5, VS=6, GND=7, VBUS=8, IN−=9, IN+=10 | INA226 datasheet, pinout diagram | **Datasheet-verified — matches** |
| Q1, Q2 | MMBT5401 SOT-23 | **1 = Base, 2 = Emitter, 3 = Collector** | onsemi MMBT5401 datasheet, "1-Base, 2-Emitter, 3-Collector" | **Datasheet-verified — matches `Q_PNP_BEC`** |
| U1 | ESP32-S3-WROOM-1 | 3V3=2, EN=3, IO8=12, IO19=13, IO20=14, IO9=17, IO10=18, IO0=27, GND=1/40/41 | Espressif datasheet (on disk) + footprint pad measurement | Datasheet-verified |
| U4 | AP2112K-3.3 | 5-pin SOT-25 | Datasheet on disk | Datasheet-verified |
| D1, D2, D3, J1, J2, SW1/2, L1, LED1 | — | — | No datasheet obtainable | **Unverified — see Review Limits** |

The transistor check matters most here. The skill's guidance is explicit that
SOT-23 BJTs exist in at least six pinout variants and that checking a symbol
against the `.kicad_sym` file is circular. I had originally confirmed `Q_PNP_BEC`
by noting that KiCad's own `MMBT3906` symbol extends it — that is a library
cross-check, not a datasheet check. The onsemi PDF settles it independently.

### Net tracing

All four new limiter nets traced end to end against the raw schematic and
confirmed against the netlist the generator verifies on every run:

| Net | Pins | Correct? |
|---|---|---|
| `+24V` | D2.1, C11.1, R10.1, R16.1, Q2.2 (emitter) | Yes — rail stops at the limiter |
| `LOOP_SNS` | R16.2, Q1.2 (emitter), R18.1 | Yes — sense node |
| `LOOP_DRV` | Q1.1 (base), Q2.3 (collector), R17.1 | Yes — Q2 steals base drive |
| `LOOP_FB` | Q2.1 (base), R18.2, R19.1 | Yes — foldback divider tap |
| `LOOP_V` | Q1.3 (collector), R19.2, J2.1, D3.1, U3.8 | Yes — field side |

`d.verify(NETS, NO_CONNECT)` compares KiCad's own extracted netlist against the
maintained specification by pin set on every generator run, and reports
"netlist matches the specification exactly" (23 nets drawn, 23 expected).

### PCB verification
Board outline 40.0 × 61.0 mm confirmed against the raw `.kicad_pcb`. Zero
courtyard overlaps; minimum pad-to-pad gap between different parts ≥ 0.5 mm
(checked by `pcblib.check()`, which measures pads rather than courtyards because
11 of the 40 footprints have pads outside their own courtyard). No
schematic-parity findings.

### Gerber verification
Not applicable — no fabrication outputs exist yet.

---

## Signal Analysis Review

### Current sense — the core of the instrument

**Shunt sizing, datasheet-verified.** INA226 shunt input range is
**−81.9175 to +81.92 mV** (datasheet §6.5), fixed, with no PGA. The shunt alone
sets the measurement ceiling:

- R12 = 3.32 Ω → full scale **24.67 mA**
- At 24 mA: 79.7 mV, 97 % of range
- 2.5 µV LSB → **0.75 µA** resolution, ~21 200 counts across 4–20 mA

This correctly accommodates a sensor driving 23.5 mA over-range, which the
previous 4.02 Ω shunt (20.4 mA ceiling) would have clipped.

**Kelvin connection.** R13/R14 tap the shunt's own pads at 1.69 mm — measured
from the placed board, not asserted. R13/R14 (10 Ω) plus C9 (100 nF) form the
differential input filter TI's datasheet recommends for exposed field wiring.

**Common-mode.** Low-side sensing puts the INA226's inputs at ~80 mV, far inside
the −0.3 V to 40 V pin rating.

### Foldback current limiter

`Itrip = (0.65 − Vce × f) / R16`, with `f = R18/(R18+R19) = 1 k/44 k = 0.0227`:

| Condition | Vce | Limit | Q1 dissipation |
|---|---|---|---|
| Running | ~0.2 V | 32 mA | negligible |
| Hard short | ~23.9 V | 5 mA | 0.128 W — see M-1 |

Design intent is sound: the limit rises with output voltage, so the foldback
doubles as a soft start rather than latching a transmitter off. Compliance cost
is ~0.7 V (0.43 V across R16 plus Q1 saturation), leaving 23.3 V at the terminal
against sensors specified to 20 V.

**This circuit exists for a real reason** worth restating: a boost converter
cannot disconnect its output. `Vin → L1 → D2 → Vout` conducts with U5 disabled,
so before Rev E a shorted field pair drove ~1.35 A from the 5 V rail through the
shunt — roughly 6 W in an 0805. Disabling the boost in firmware does not fix
that; only a series element does.

### Protection devices
`D1` USBLC6-2SC6 on the USB data lines (PD-DET, "esd_ic"). `D3` SMAJ36A across
the field terminal. See F-4 in False Positives for the VBUS ESD question.

### RC filters
`R1`/`C1` at 15.92 Hz — the ESP32-S3 reset RC, ~10 ms rise on EN. Correct by
intent.

### Simulation verification
**Not performed.** `ngspice`, `ltspice` and `xyce` are all absent from this
machine, so the `spice` skill has no simulator to drive. The divider and filter
values above were checked arithmetically against datasheet reference voltages
instead. This is a real gap: SPICE is what catches value-computation errors that
static analysis misses.

---

## Power Analysis

Decoupling detected on `+5V` and `+3V3` (DC-DET, DO-DET). The module's HF cap
`C3` sits at U1 pin 2 and the bulk `C2` below it; `C8` bypasses the INA226 at
VS. No IC power pin reaches its rail only through a capacitor (no PP-001).

No rail-source findings (RS-001/002/003) — every rail has a declared source.

---

## PCB Layout Analysis

The board is **placed but unrouted**: 0 tracks, 0 vias, 0 zones, 0 copper layers
in use. Everything below is placement-stage only.

**Placement quality**, measured rather than asserted:

| Net | Span | Comment |
|---|---|---|
| `/MT_SW` | 5.45 mm | Boost switching node — the one that matters for EMI |
| Kelvin taps | 1.69 mm | R13/R14 against the shunt pads they measure |
| `/LOOP_RTN` | 9.68 mm | Terminal to shunt |
| `/USB_DP` / `/USB_DM` | 35–37 mm | The cost of portrait layout; fine for 12 Mbps full-speed USB, but route as a close pair over unbroken ground |
| `/I2C_SDA` / `/I2C_SCL` | 25–32 mm | 400 kHz, length irrelevant |

**Antenna.** The ESP32-S3 module's antenna cantilevers 6.5 mm off the top edge,
so there is no PCB under it at all — Espressif's best case. PM-002 flags J1 at
0.03 mm from the board edge and the module antenna at the edge; both are
deliberate. Mechanically the module is soldered on three edges with 6.5 mm
unsupported, so the enclosure must not press on it.

**DFM.** JLCPCB standard tier, **0 violations**, board 40 × 61 mm.

**Fabrication rules.** Board Setup now carries JLCPCB's 2-layer capabilities.
The significant find during this revision: `min_clearance` was **0.0** — DRC had
no global spacing floor at all, only the netclasses' own 0.2 mm. Now 0.127 mm.
Silkscreen line width and text thickness were 0.10 mm against JLCPCB's 0.15 mm
minimum. Rules already stricter than the fab (track 0.153, via 0.5/0.13, hole
0.3, edge 0.5) were deliberately left alone.

---

## Thermal Analysis

`analyze_thermal.py` ran and returned **0 findings with the score SKIPPED** —
correctly, because thermal modelling needs PCB copper and via data and the board
has neither yet. Re-run it after routing and pouring.

The Q1 calculation in M-1 is a hand calculation from datasheet θ figures, not
analyzer output, and is labelled as such.

The other dissipating parts are undemanding: the shunt burns 1.9 mW at 24 mA;
the LDO drops 1.7 V at up to ~240 mA (≈0.4 W in SOT-25) — that one is worth
re-checking once the copper pour exists, since it is the largest steady
dissipation on the board.

---

## EMC / Cross-Domain Analysis

**Cross-domain (`cross_analysis.py`): 0 findings.** No connector current-capacity
problems, no decoupling-adequacy gaps, no schematic/PCB sync errors.

**EMC risk score 86.5**, 4 findings — all attributable to the unrouted state:

| Rule | Severity | Finding | Assessment |
|---|---|---|---|
| GP-002 | error | No ground plane zones detected | Expected — not routed. **Must be resolved before fab** |
| VS-001 | warning | Via stitching may be insufficient | Expected — no vias yet |
| GP-001 | info | Return path analysis unavailable | Consequence of the above |
| EE-001 | info | Board cavity resonance frequencies | Informational |

The EMC assessment is therefore **provisional**. Re-run it after routing — with
a 24 V switching node and a 2.4 GHz radio on the same board, the ground pour and
stitching around the boost are the decisive factors and none of them exist yet.

---

## Component Lifecycle

Audit **ran but returned no usable data**: 30 components checked, all 30
`unknown`. LCSC is the only distributor configured on this machine and it does
not expose lifecycle status, so every result is `unknown` by construction. No
DigiKey, Mouser or element14 credentials are set.

Temperature audit: 0 of 30 checked against the industrial range, same cause.

**Not a clean bill of health — an absence of data.** For a board intended for
industrial field wiring, the −40/+85 °C coverage of every part is worth
confirming before production, especially the electrolytic-free but
ceramic-heavy power path.

Sourcing risk from the earlier BOM pass still stands: the **ESP32-S3-WROOM-1-N4
is the only line under 5 000 in stock** (4 715). Fine for prototypes, worth
watching for a production run.

---

## Manufacturing / DFM / Testability

| Finding | Severity | Assessment |
|---|---|---|
| FD-001 — no fiducials, 39 SMD components | high | **FIXED 2026-09-20.** Three `Fiducial_1mm_Mask2mm` at (4, 7), (36, 7) and (36, 54) mm — an L configuration, 4 mm in from the edges against JLCPCB's 3.85 mm guidance, and as far apart as the parts allow. Board-only footprints: no schematic symbol, excluded from the BOM and from the position file, so they cannot appear as orphan designators in a PCBA upload |
| TE-001 — test point coverage 0/54 nets | warning | **Real but a judgement call.** At minimum consider pads on `LOOP_V`, `LOOP_RTN`, `+24V`, `+3V3` and `MT_EN` — bring-up on a board with no test points means probing 0402 terminations |
| OR-001 — 11 passives deviate from 90° orientation | info | Placement choice; parts were oriented to face the pins they serve. No assembly impact at this scale |
| TB-001 ×9 — 0402 tombstoning risk "medium" | info | Inherent to 0402 with asymmetric thermal mass; the footprints are symmetric. Accept |
| Unique extended parts | — | 15 of 30 BOM lines are JLCPCB *extended*, none preferred → ~$45 one-off setup fees |

Assembly is single-sided (all 40 parts on top), which keeps it to JLCPCB's
Economic tier apart from the one through-hole part (J2, the terminal block),
which pushes it to Standard.

---

## False Positives / Reviewer Overrides

Findings reviewed and judged benign, kept here so you can see they were
considered:

| Rule | Finding | Why dismissed |
|---|---|---|
| **VM-001** | "Net MT_EN: 5.0 V / 3.3 V domain crossing without level shifter" | **False positive.** The analyzer infers U5's domain from its VIN rail. EN is a logic input: **V_IH 1.5 V min, V_IL 0.4 V max, absolute max 26 V** (MT3608 datasheet). A 3.3 V GPIO drive is well above threshold and far below the limit, and R15 pulls to +3V3 — not +5V — so the ESP32 pin sees nothing above 3.3 V either. Datasheet-verified |
| **PU-001** | "U3 pin Alert missing pull-up resistor" | **False positive.** Alert is an open-drain *output*, deliberately in `NO_CONNECT`. An unused output needs no pull-up |
| **LD-DET** | "LED driver Q2" | **False positive.** Q2 is the limiter's sense transistor. Pattern-matcher overreach |
| **RT-001 ×23** | Unrouted nets | Expected — the board is placed, not routed |
| **VD-004** | "C10 (10 µF/50 V) is over-designed for +5V" | **Deliberate.** C10 and C11 are the same part number so the BOM carries one line instead of two; the 50 V part is required at C11 on the 24 V rail |
| **PM-002** | J1 0.03 mm from board edge; RF module antenna at edge | **Deliberate.** The USB-C opening is flush by design and the antenna overhang is the point |
| **F-4: UC-002** | "No ESD/TVS protection on VBUS at J1" | **False positive — confirmed 2026-09-20 against ST's datasheet** (USBLC6-2, Doc ID 11265 Rev 5). Its feature list opens with "2 data-line protection / Protects VBUS", and Table 2 specifies **V_BR, breakdown voltage between VBUS and GND, 6 V minimum at I_R = 1 mA** — an internal zener from pin 5 to ground. The SOT23-6L pinout is **1 = I/O1, 2 = GND, 3 = I/O2, 4 = I/O2, 5 = VBUS, 6 = I/O1**, which matches D1's wiring exactly (pins 1/6 on `USB_P`, 3/4 on `USB_N`, 5 on `+5V`, 2 on `GND`). My earlier description of it as a "5-line device" was wrong: it protects two data lines *and* VBUS. Caveat: the BOM part is `C2687116`, a second source rather than genuine ST — its LCSC parametrics (5 V standoff, 6 V, SOT-23-6) are consistent, but only the ST part is datasheet-verified |

---

## Not Performed / Review Limits

- **SPICE simulation not performed** — no simulator installed (`ngspice`,
  `ltspice`, `xyce` all absent). Divider and filter values were checked
  arithmetically against datasheet reference voltages instead.
- **Gerber analysis not performed** — no fabrication outputs exist yet.
- **Lifecycle audit produced no usable data** — LCSC-only, which returns
  `unknown` for all statuses. No DigiKey/Mouser/element14 credentials.
- **Thermal analyzer returned SKIPPED** — needs PCB copper and vias, which do
  not exist pre-routing.
- **Datasheet coverage is 4 of 31 unique parts** (ESP32-S3, INA226, AP2112K,
  MT3608), plus MMBT5401, SMAJ36A and — added in the 2026-09-20 update —
  USBLC6-2, obtained from the web during this review.
  An LCSC sync attempt returned no additional datasheet URLs. Pin-level claims
  for **D2, J1, J2, SW1/SW2, L1, LED1** are therefore *unverified* — they
  are inference from the footprint and net names, not datasheet checks.
- **No structured datasheet extraction cache** (`datasheets/extracted/`) — all
  datasheet checks in this review were done by reading the PDFs directly.
- **No deep-review JSON** (`analysis/deep_review.json`) — the per-IC deep pass
  was done inline in this document rather than through the gated pipeline.
- **No previous review delta** — this is the first design review of this board,
  so there is nothing to diff against. Future reviews can diff
  `analysis/2026-09-20_1224`.
- **EMC assessment is provisional** — see above.

---

## Verdict

**Not ready to fabricate — but the gap is routing, not design.**

Blocking, in order:

1. **Route the board**, pour ground on both layers and stitch it, then re-run
   the EMC and thermal analyses. GP-002 and VS-001 resolve here.
2. ~~**H-1 — add a series resistor to the INA226's VBUS pin.**~~ Done: `R20`.
3. ~~**Decide on M-1** — Q1's thermal margin at high ambient.~~ Risk accepted.
4. ~~**Confirm F-4** — whether the USBLC6-2SC6 clamps VBUS.~~ Done: it does.
5. ~~**Add fiducials**; consider test points.~~ Both done.
6. ~~**Decide J1's hole clearance.**~~ Resolved: the rule was the problem, not
   the board. See *J1 hole clearance* below — two 0.1812 mm items remain as a
   documented, accepted deviation.

Then, before ordering: remember J2's mating plug (C71370) is not on the board
and not in the BOM — it is in `bom/non-bom-items.csv`.

---

## J1 hole clearance — resolved 2026-09-20

All four `hole_clearance` errors were **inside J1's own footprint**: its two
0.70 mm NPTH locating pegs against its own signal pads. Not a placement
mistake, and nothing about the layout could fix them.

| Pads | Actual | JLCPCB min (0.20 mm) | Old board rule (0.25 mm) |
|---|---|---|---|
| A4B9 / B4A9 (`+5V`) | 0.2219 mm | passes | failed |
| A1B12 / B1A12 (`GND`) | 0.1812 mm | fails by 0.019 mm | failed |

JLCPCB publishes **0.20 mm NPTH-to-track** for 2-layer boards, so half these
errors existed only because the project's rule was stricter than the fab's.
`min_hole_clearance` is now **0.20 mm** — the fab's real number — and the
count drops from four errors to two.

**The two remaining are an accepted deviation, not an oversight.** They are
0.019 mm inside JLCPCB's limit, on a connector that ships by the million with
this exact land pattern, and — the part that actually matters — the affected
pads are the **duplicated** GND pads: `A1` and `B12` are the same net and so
are `B1` and `A12`, each appearing on both sides of the receptacle. A drill
breakout into one would not open the connection.

Two alternatives were considered and not taken. Shrinking the pegs to 0.60 mm
would clear both, but the connector's post diameter could not be obtained and
0.70 mm suggests ~0.6 mm posts, which would make it an interference fit.
Trimming the two GND pads by ~0.07 mm would clear even the old 0.25 mm rule at
the cost of ~6 % of their solder area; that remains the fallback if JLCPCB
objects at DFM review.

`min_hole_to_hole` was deliberately left at 0.25 mm — it was not implicated.

What is already solid: the netlist matches its specification exactly and is
re-verified on every generator run; every IC pinout that could be checked
against a manufacturer PDF is correct, including the transistor pinout that is
the classic silent killer; the shunt sizing is right for the stated 24 mA
requirement with margin; the current limiter addresses a genuine failure mode
with a correct topology; and placement measurements back the layout claims
rather than asserting them.

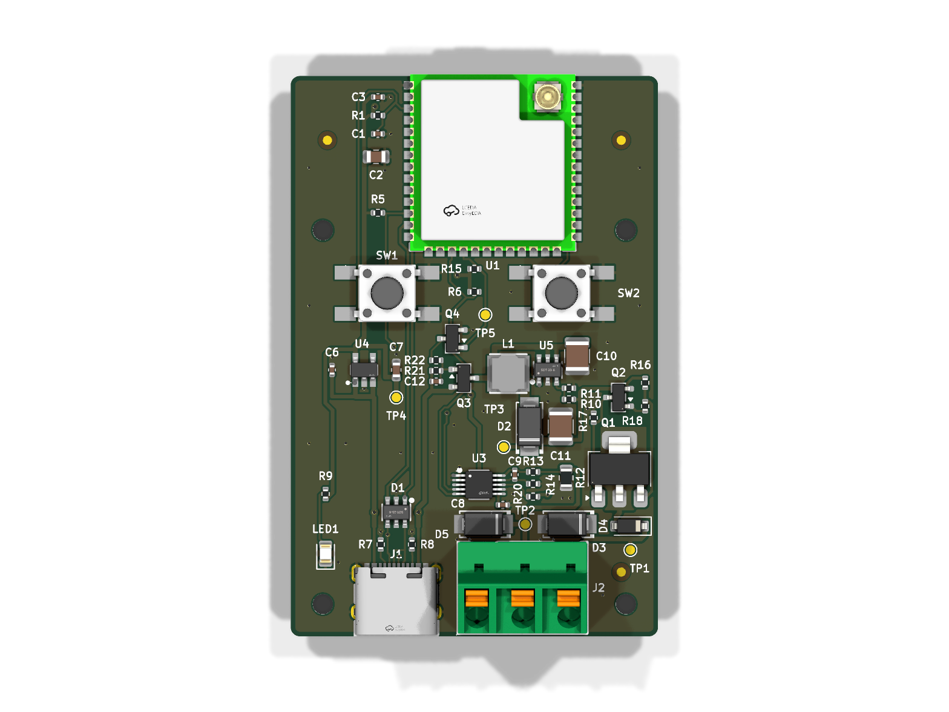
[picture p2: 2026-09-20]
render/pcb_top.png

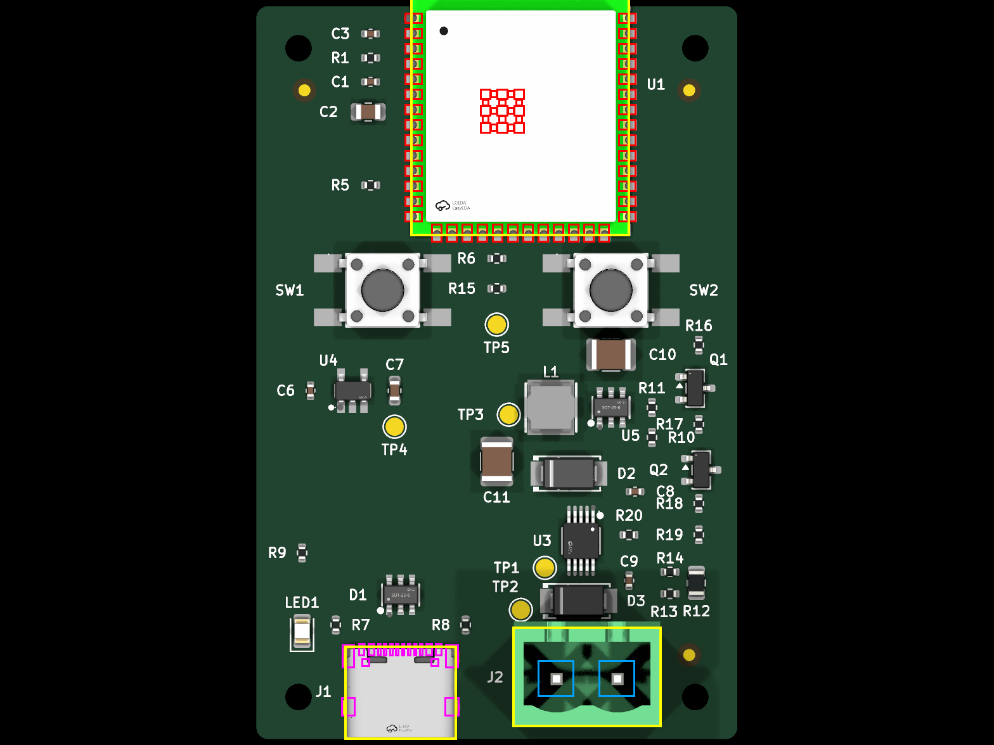
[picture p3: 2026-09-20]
render/pcb_top_pad_overlay.png

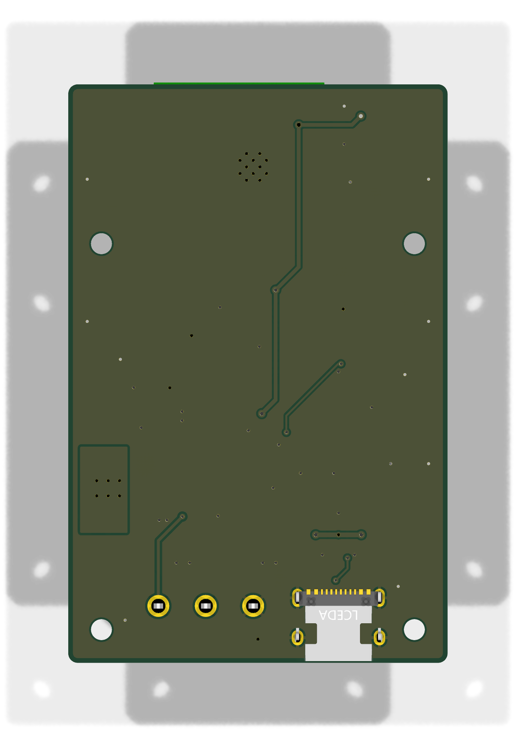
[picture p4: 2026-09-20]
render/pcb_bottom.png

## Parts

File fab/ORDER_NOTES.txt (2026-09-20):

JLCPCB order settings for esp32-4to20ma-board (Rev G, 2026-09-20)

PCB
  Layers 2, 40 x 61 mm, thickness 1.6 mm, outer copper 1 oz, FR-4 (stackup JLC0216A).
  Surface finish: LeadFree HASL is fine; nothing finer than 0.5 mm pitch (U3, MSOP-10).
  Via covering: tented. Smallest via 0.6 mm / 0.3 mm hole, smallest track 0.2 mm,
  smallest clearance 0.15 mm (USB fan-out), copper to edge 0.5 mm: all in the
  no-surcharge tier.
  Impedance control: NO. Two layers, and the USB is full speed (12 Mbit/s).
  Remove order number: optional; no "JLCJLCJLCJLC" location is drawn on this board.
  The ESP32 module's footprint reaches 0.19 mm past the TOP board edge and J1's and
  J2's bodies reach the BOTTOM edge: intentional, say so if their engineer asks.

PCB assembly
  PCBA type: STANDARD, not Economic. U1 (ESP32-S3-WROOM-1U-N4, C2980296) is listed
  "PCBA Type: Standard Only" in JLCPCB's parts library (checked 2026-09-20). J2
  (KF250NH-5.0-3P, C976567) is "Economic and Standard", assembly type "Wave Soldering":
  it is the one through-hole part and rides along in a Standard order.
  Side: top only. Tooling holes: added by JLCPCB. Fiducials FID1-FID3 are on the board.
  Files: *_bom.csv and *_cpl.csv from this folder.
  Not populated by design, in neither file: H1-H4 (holes), FID1-3, TP1-TP5 (pads).

  Placement corrections (jlc_rotations.json, each with its evidence): every polarised
  part was compared pad by pad with JLCPCB's own footprint for its LCSC number. The
  project-library parts are already at JLCPCB's zero. Only the four stock-KiCad
  transistor footprints needed a correction: Q1 (SOT-223), Q2 Q3 Q4 (SOT-23), +180.
  NONE of this has been seen in their preview yet. LOOK AT THESE after uploading the CPL:
    Q1         tab (the wide pin) toward the TOP of the board, its three pins toward the bottom
    Q2 Q4      the single pin (collector / drain) on the LEFT, the pair on the right
    Q3         the single pin (drain) on the RIGHT, the pair on the left
    D2         cathode band at the BOTTOM (pad 1, the +24V end, beside C11)
    D3 D5 D4   cathode band on the RIGHT (pad 1: LOOP_V on D3 and D4, LOOP_RTN on D5)
    LED1       cathode toward the BOTTOM edge. Its polarity rests on pad 1 = cathode in their
               LED0805-RD footprint (its closed silk end is on the pad-1 side, as in KiCad's);
               their symbol could not be fetched to confirm. A reversed LED only stays dark.
    U1         module's RF can over the board, U.FL connector at the top-right corner
    U3 U4 U5 D1  pin-1 dot on the silkscreen mark
    J1         contacts on the pads, opening toward the bottom edge
    J2         wire entries toward the bottom edge, orange buttons behind them

Also order (bom/non-bom-items.csv): a U.FL / IPEX Gen 1 pigtail and a 2.4 GHz antenna.
The -1U module has no antenna of its own.

First board bring-up
  Before plugging a sensor in: +5V, +3V3 at TP4, then MT_EN high and +24V at TP3.
  Short LOOP_V (TP1) to LOOP_RTN (TP2) through a meter: expect about 33 mA, and the
  firmware should drop MT_EN within its timeout. Q1 runs warm in that test (0.85 W).
  Two-point calibration at 4 and 20 mA (firmware/README.md).

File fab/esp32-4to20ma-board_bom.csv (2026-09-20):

Comment | Designator | Footprint | LCSC Part # | MPN | Manufacturer | Quantity
1uF | C1,C6 | C_0402_1005Metric | C52923 | CL05A105KA5NQNC | Samsung Electro-Mechanics | 2
22uF | C2 | C_0805_2012Metric | C45783 | CL21A226MAQNNNE | Samsung Electro-Mechanics | 1
100nF | C3,C8,C9,C12 | C_0402_1005Metric | C1525 | CL05B104KO5NNNC | Samsung Electro-Mechanics | 4
10uF | C7 | C_0603_1608Metric | C19702 | CL10A106KP8NNNC | Samsung Electro-Mechanics | 1
10uF/50V | C10,C11 | C_1210_3225Metric | C2918502 | CS3225X7R106K500NRL | Samwha | 2
USBLC6-2SC6 | D1 | SOT-23-6_L2.9-W1.6-P0.95-LS2.8-BL | C2687116 | USBLC6-2SC6 | UMW | 1
SS34 | D2 | SMA_L4.3-W2.6-LS5.2-RD | C8678 | SS34 | MDD | 1
SMAJ28A | D3 | SMA_L4.3-W2.6-LS5.2-RD | C353458 | SMAJ28A | Jingdao Microelectronics | 1
1N4148W | D4 | D_SOD-123 | C81598 | 1N4148W | ST (Semtech) | 1
SMAJ12A | D5 | SMA_L4.3-W2.6-LS5.2-RD | C113957 | SMAJ12A | MDD | 1
USB-C Receptacle | J1 | USB-C-SMD_TYPE-C-16PIN-2MD-073 | C2765186 | TYPE-C 16PIN 2MD(073) | SHOU HAN | 1
4-20mA Loop | J2 | CONN-TH_KF250NH-5.0-3P | C976567 | KF250NH-5.0-3P | Cixi Kefa | 1
22uH | L1 | IND-SMD_L4.0-W4.0_FNR40XXS | C167883 | FNR4030S220MT | cjiang | 1
Power | LED1 | LED_0805_2012Metric | C84256 | NCD0805R1 | Nationstar | 1
BCP53-16 | Q1 | SOT-223 | C148109 | BCP53-16 | JSCJ | 1
MMBT5401 | Q2 | SOT-23 | C8326 | MMBT5401 | JSCJ | 1
AO3401A | Q3 | SOT-23 | C15127 | AO3401A | Alpha & Omega | 1
2N7002 | Q4 | SOT-23 | C8545 | 2N7002 | JSCJ | 1
10k | R1,R11,R20 | R_0402_1005Metric | C25744 | 0402WGF1002TCE | Uniroyal | 3
4.7k | R5,R6 | R_0402_1005Metric | C25900 | 0402WGF4701TCE | Uniroyal | 2
5.1k | R7,R8 | R_0402_1005Metric | C25905 | 0402WGF5101TCE | Uniroyal | 2
330 | R9 | R_0402_1005Metric | C25104 | 0402WGF3300TCE | Uniroyal | 1
390k | R10,R21 | R_0402_1005Metric | C2909352 | FRC0402F3903TS | FOJAN | 2
3.32 | R12 | R_0805_2012Metric | C3013220 | FRC0805F3R32TS | FOJAN | 1
10 | R13,R14 | R_0402_1005Metric | C25077 | 0402WGF100JTCE | Uniroyal | 2
100k | R15,R22 | R_0402_1005Metric | C25741 | 0402WGF1003TCE | Uniroyal | 2
18 | R16 | R_0402_1005Metric | C138043 | RC0402FR-0718RL | Yageo | 1
47k | R17 | R_0402_1005Metric | C25792 | 0402WGF4702TCE | Uniroyal | 1
1k | R18 | R_0402_1005Metric | C11702 | 0402WGF1001TCE | Uniroyal | 1
KH-6X6X5H-STM | SW1,SW2 | SW-SMD_4P-L6.0-W6.0-P4.50-LS9.0_H5.0 | C2837531 | KH-6X6X5H-STM | Kinghelm | 2
ESP32-S3-WROOM-1U-N4 | U1 | WIFIM-SMD_ESP32-S3-WROOM-1U | C2980296 | ESP32-S3-WROOM-1U-N4 | Espressif | 1
INA226AIDGSR | U3 | MSOP-10_L3.0-W3.0-P0.50-LS5.0-BL | C49851 | INA226AIDGSR | Texas Instruments | 1
AP2112K-3.3 | U4 | SOT-25-5_L2.9-W1.6-P0.95-LS2.8-BL | C51118 | AP2112K-3.3TRG1 | Diodes Inc | 1
MT3608 | U5 | SOT-23-6_L2.9-W1.6-P0.95-LS2.8-BL | C84817 | MT3608 | Aerosemi | 1

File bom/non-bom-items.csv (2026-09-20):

Item | Qty | Description | MPN | Manufacturer | LCSC | Unit_USD | Datasheet | Notes
Antenna pigtail | 1 | U.FL / IPEX Gen 1 (MHF1) to SMA bulkhead, ~12 cm | KH-FLSMA-IPEX113-120 | Kinghelm | C5441709 |  | https://www.lcsc.com/product-detail/C5441709.html | The ESP32-S3-WROOM-1U has NO antenna of its own: without this and the antenna below the radio does not work. The module's connector is U.FL / IPEX generation 1 - Gen 3 and Gen 4 (MHF3/MHF4) are smaller and do not mate. Only 30 in stock at LCSC on 2026-09-20; it is a commodity part, any Gen 1 pigtail of a length that suits the enclosure will do. Check the SMA gender against the antenna (standard SMA, not RP-SMA).
2.4 GHz antenna | 1 | 2.4 GHz 3 dBi whip, SMA male, 50 mm | BW2.4GJWX50-10ZJ | BAT WIRELESS | C497016 |  | https://www.lcsc.com/product-detail/C497016.html | Mates with the pigtail's bulkhead SMA through the enclosure wall. 1,961 in stock 2026-09-20. Any 2.4 GHz SMA antenna works; pick by enclosure.

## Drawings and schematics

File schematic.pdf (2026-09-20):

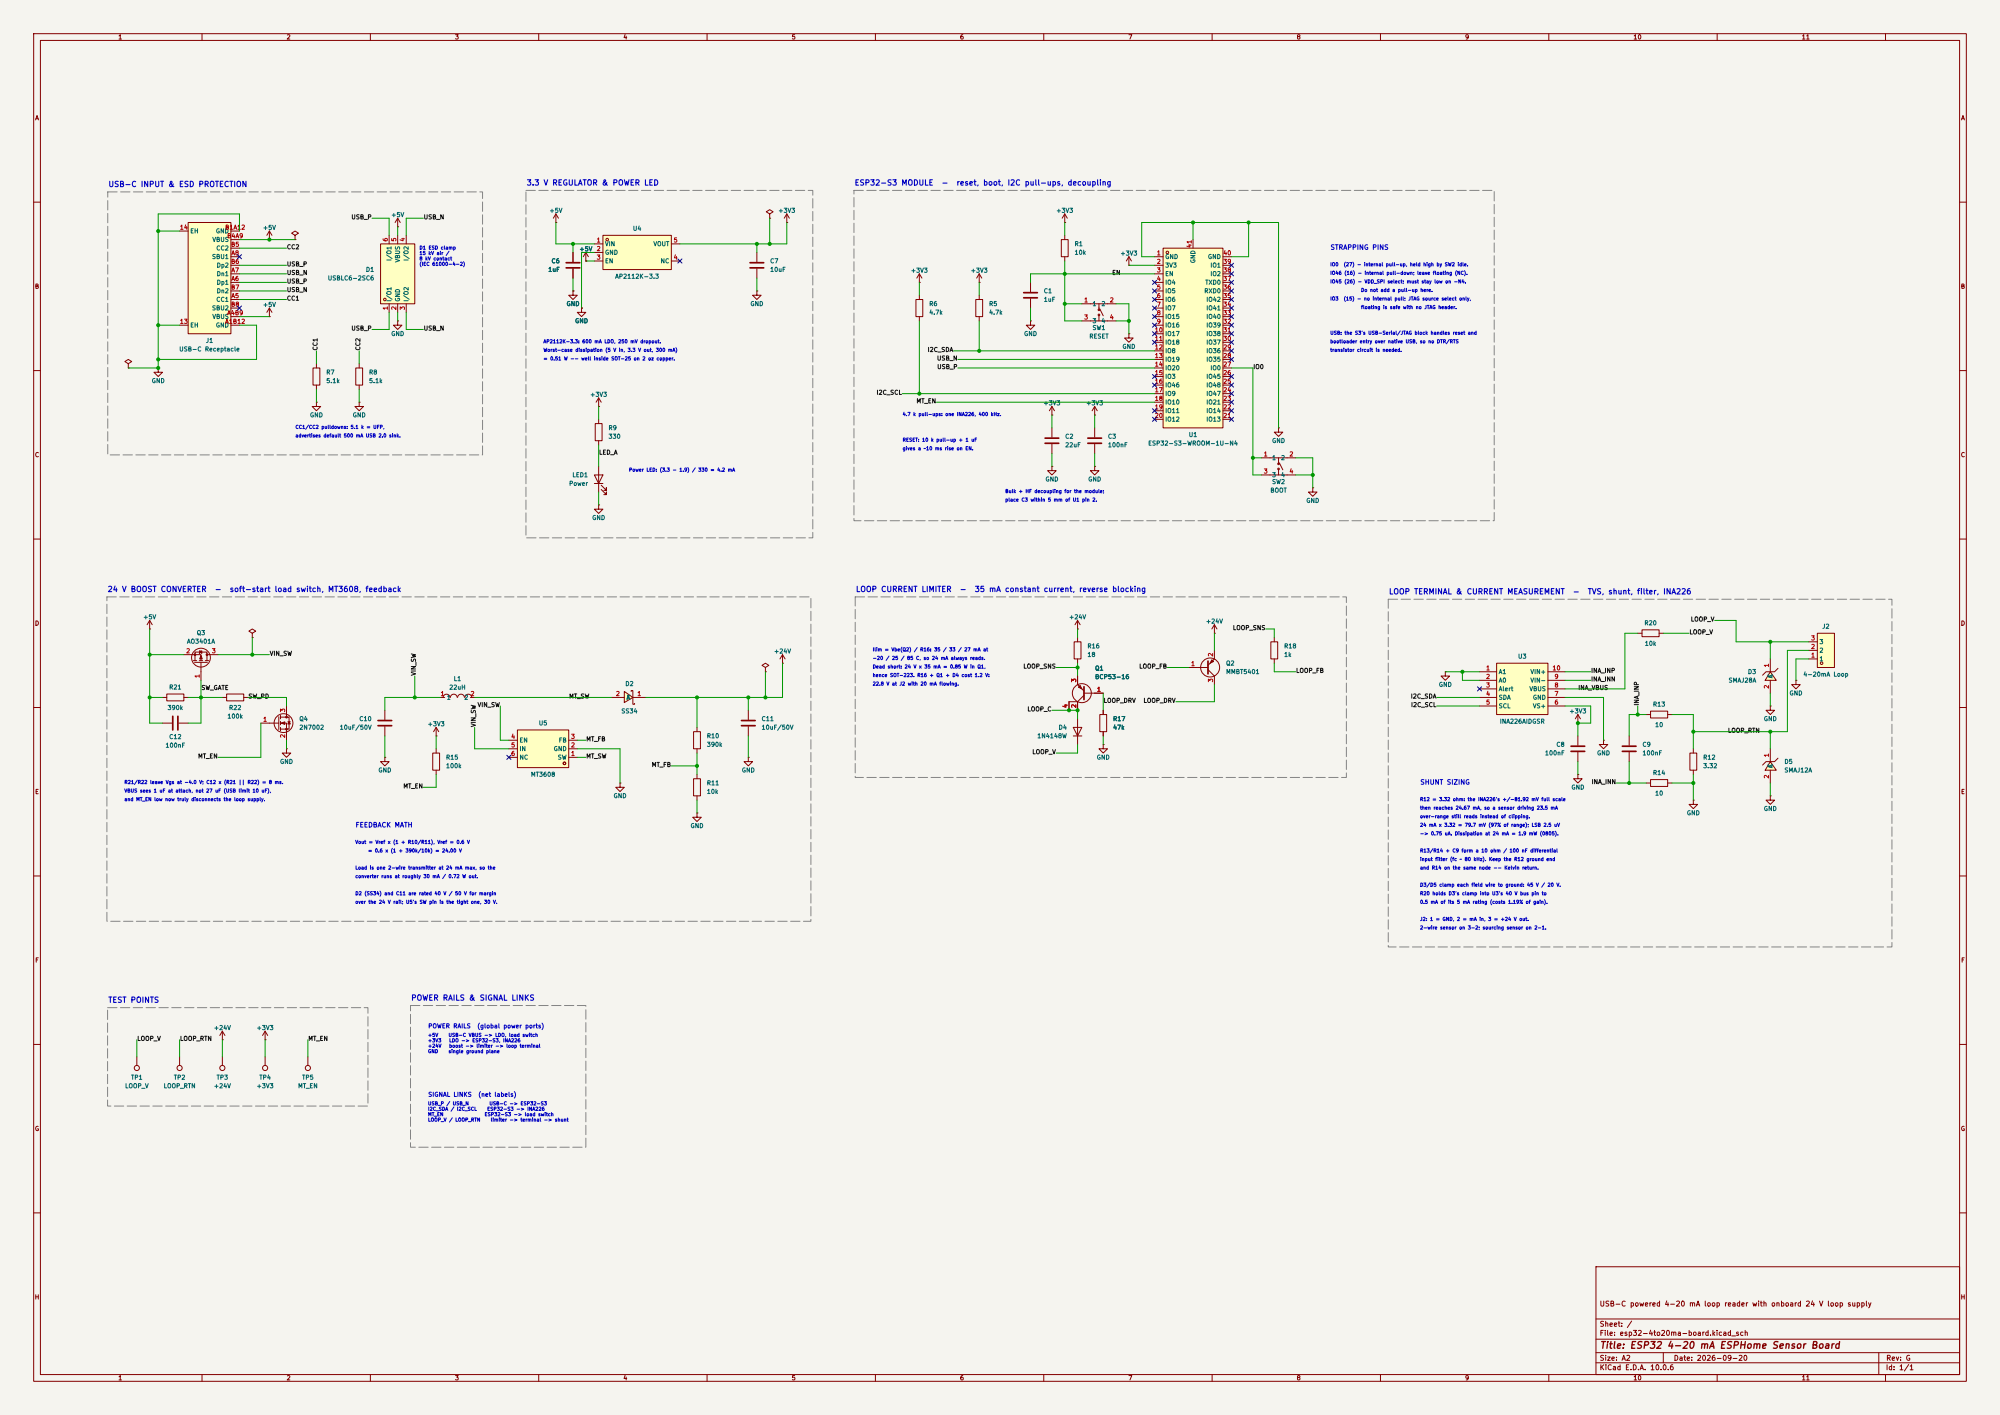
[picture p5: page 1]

D1 ESD clamp 15 kV air /

IO0 (27) - internal pull-up, held high by SW2 idle. Do not add a pull-up here. 24 V BOOST CONVERTER - soft-start load switch, MT3608, feedback

IO46 (16) - internal pull-down; leave floating (NC).
IO45 (26) - VDD_SPI select; must stay low on -N4.

IO3 (15) - no internal pull; JTAG source select only, floating is safe with no JTAG header. bootloader entry over native USB, so no DTR/RTS

USB: the S3's USB-Serial/JTAG block handles reset and

AP2112K-3.3: 600 mA LDO, 250 mV dropout.
Worst-case dissipation (5 V in, 3.3 V out, 300 mA)

transistor circuit is needed.

place C3 within 5 mm of U1 pin 2.

LOOP TERMINAL & CURRENT MEASUREMENT - TVS, shunt, filter, INA226

Ilim = Vbe(Q2) / R16: 35 / 33 / 27 mA at hence SOT-223. R16 + Q1 + D4 cost 1.2 V: -20 / 25 / 85 C, so 24 mA always reads. POWER RAILS & SIGNAL LINKS

22.8 V at J2 with 20 mA flowing.

R21/R22 leave Vgs at -4.0 V; C12 x (R21 || R22) = 8 ms. and MT_EN low now truly disconnects the loop supply.
VBUS sees 1 uF at attach, not 27 uF (USB limit 10 uF),

R12 = 3.32 ohm: the INA226's +/-81.92 mV full scale
over-range still reads instead of clipping. then reaches 24.67 mA, so a sensor driving 23.5 mA

input filter (fc ~ 80 kHz). Keep the R12 ground end D3/D5 clamp each field wire to ground: 45 V / 20 V. J2: 1 = GND, 2 = mA in, 3 = +24 V out. 0.5 mA of its 5 mA rating (costs 1.19% of gain). and R14 on the same node -- Kelvin return. -> 0.75 uA. Dissipation at 24 mA = 1.9 mW (0805). R13/R14 + C9 form a 10 ohm / 100 nF differential 24 mA x 3.32 = 79.7 mV (97% of range); LSB 2.5 uV 2-wire sensor on 3-2; sourcing sensor on 2-1.

converter runs at roughly 30 mA / 0.72 W out. Vout = Vref x (1 + R10/R11), Vref = 0.6 V

Load is one 2-wire transmitter at 24 mA max, so the over the 24 V rail; U5's SW pin is the tight one, 30 V. SIGNAL LINKS (net labels)

R20 holds D3's clamp into U3's 40 V bus pin to

USB-C powered 4-20 mA loop reader with onboard 24 V loop supply +24V

Sheet: /
File: esp32-4to20ma-board.kicad_sch
Title: ESP32 4-20 mA ESPHome Sensor Board

Size: A2 | Rev: G
KiCad E.D.A. 10.0.6 | Id: 1/1

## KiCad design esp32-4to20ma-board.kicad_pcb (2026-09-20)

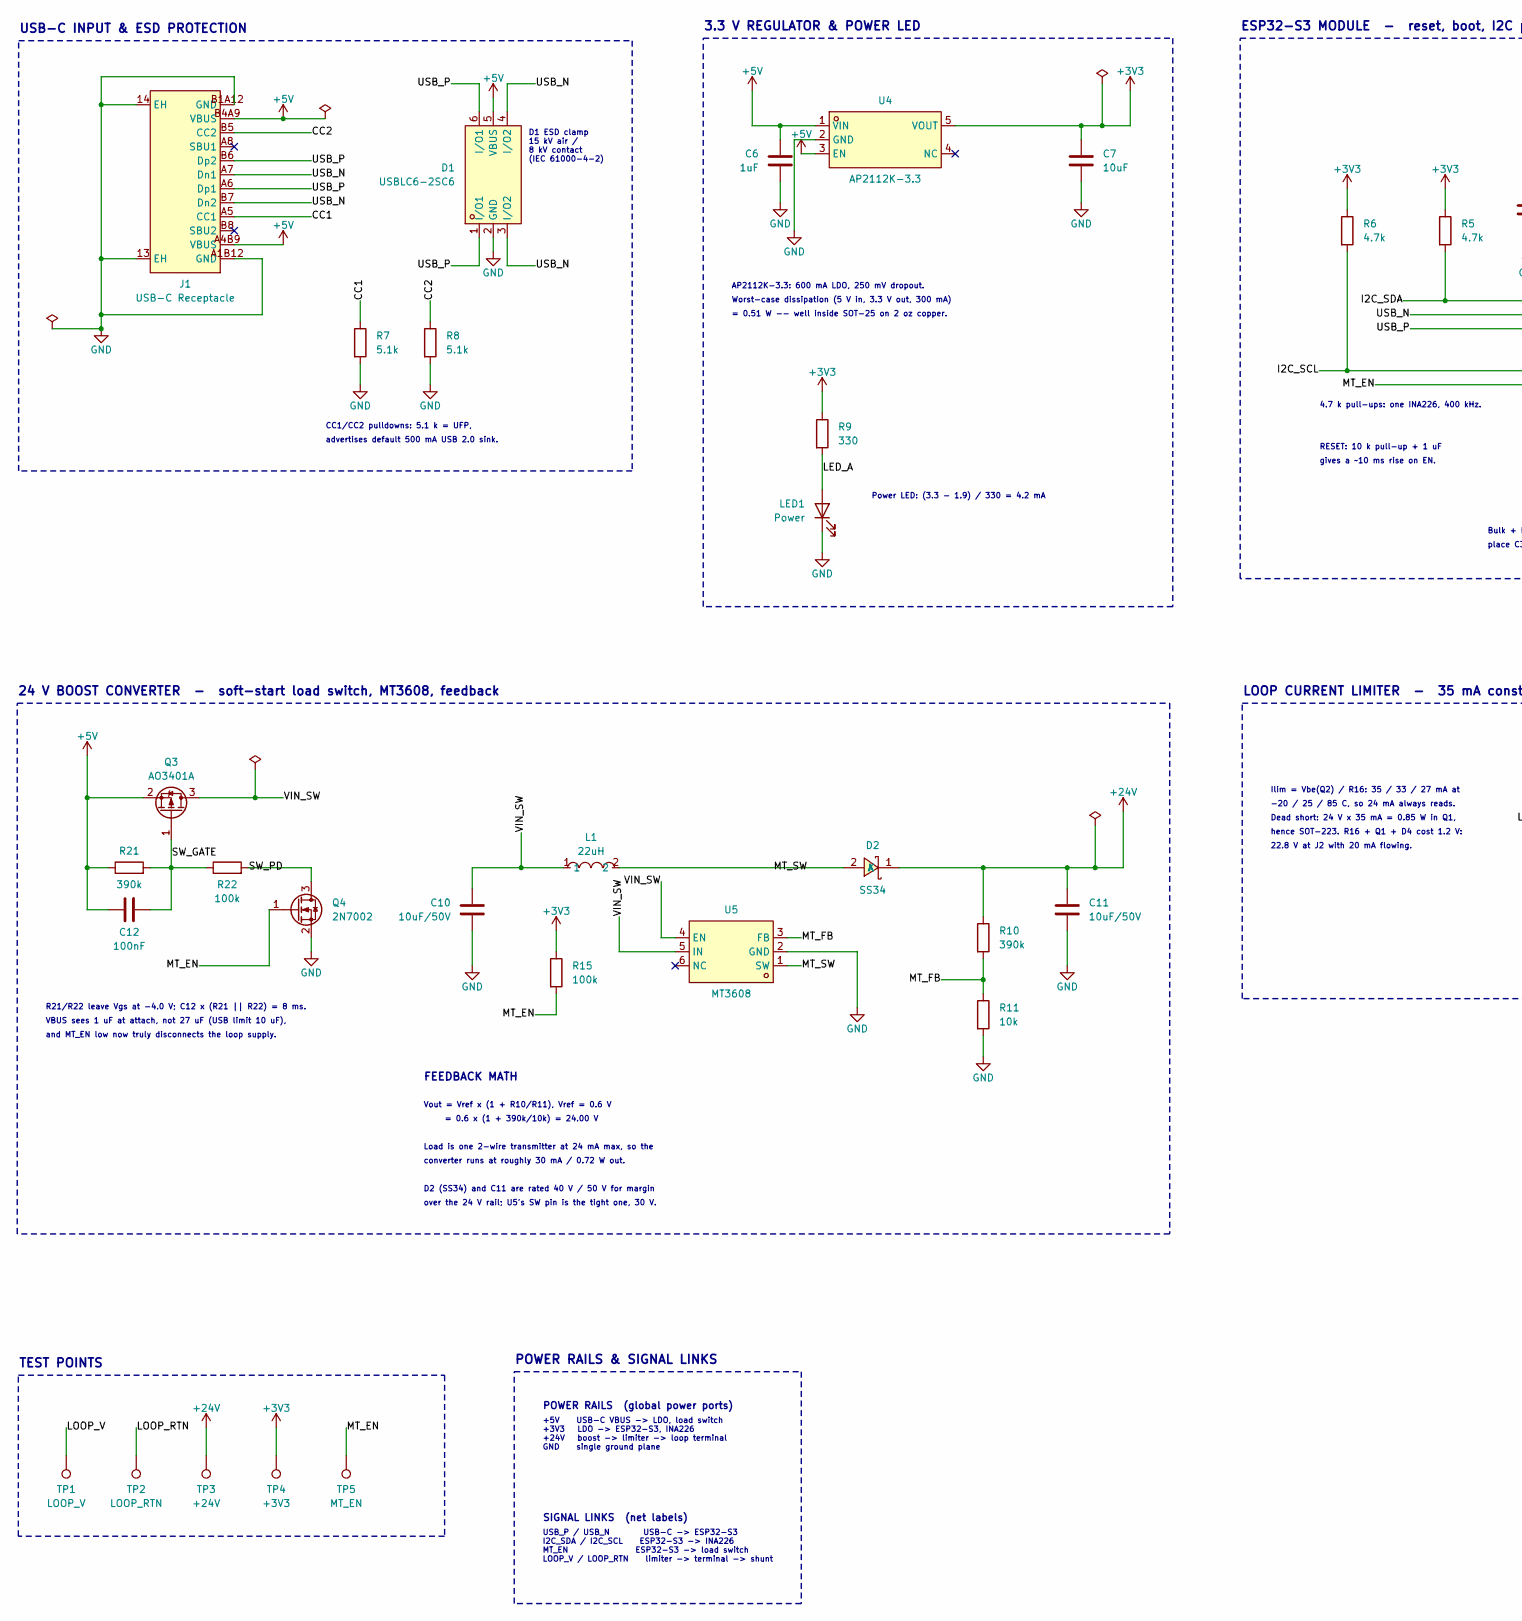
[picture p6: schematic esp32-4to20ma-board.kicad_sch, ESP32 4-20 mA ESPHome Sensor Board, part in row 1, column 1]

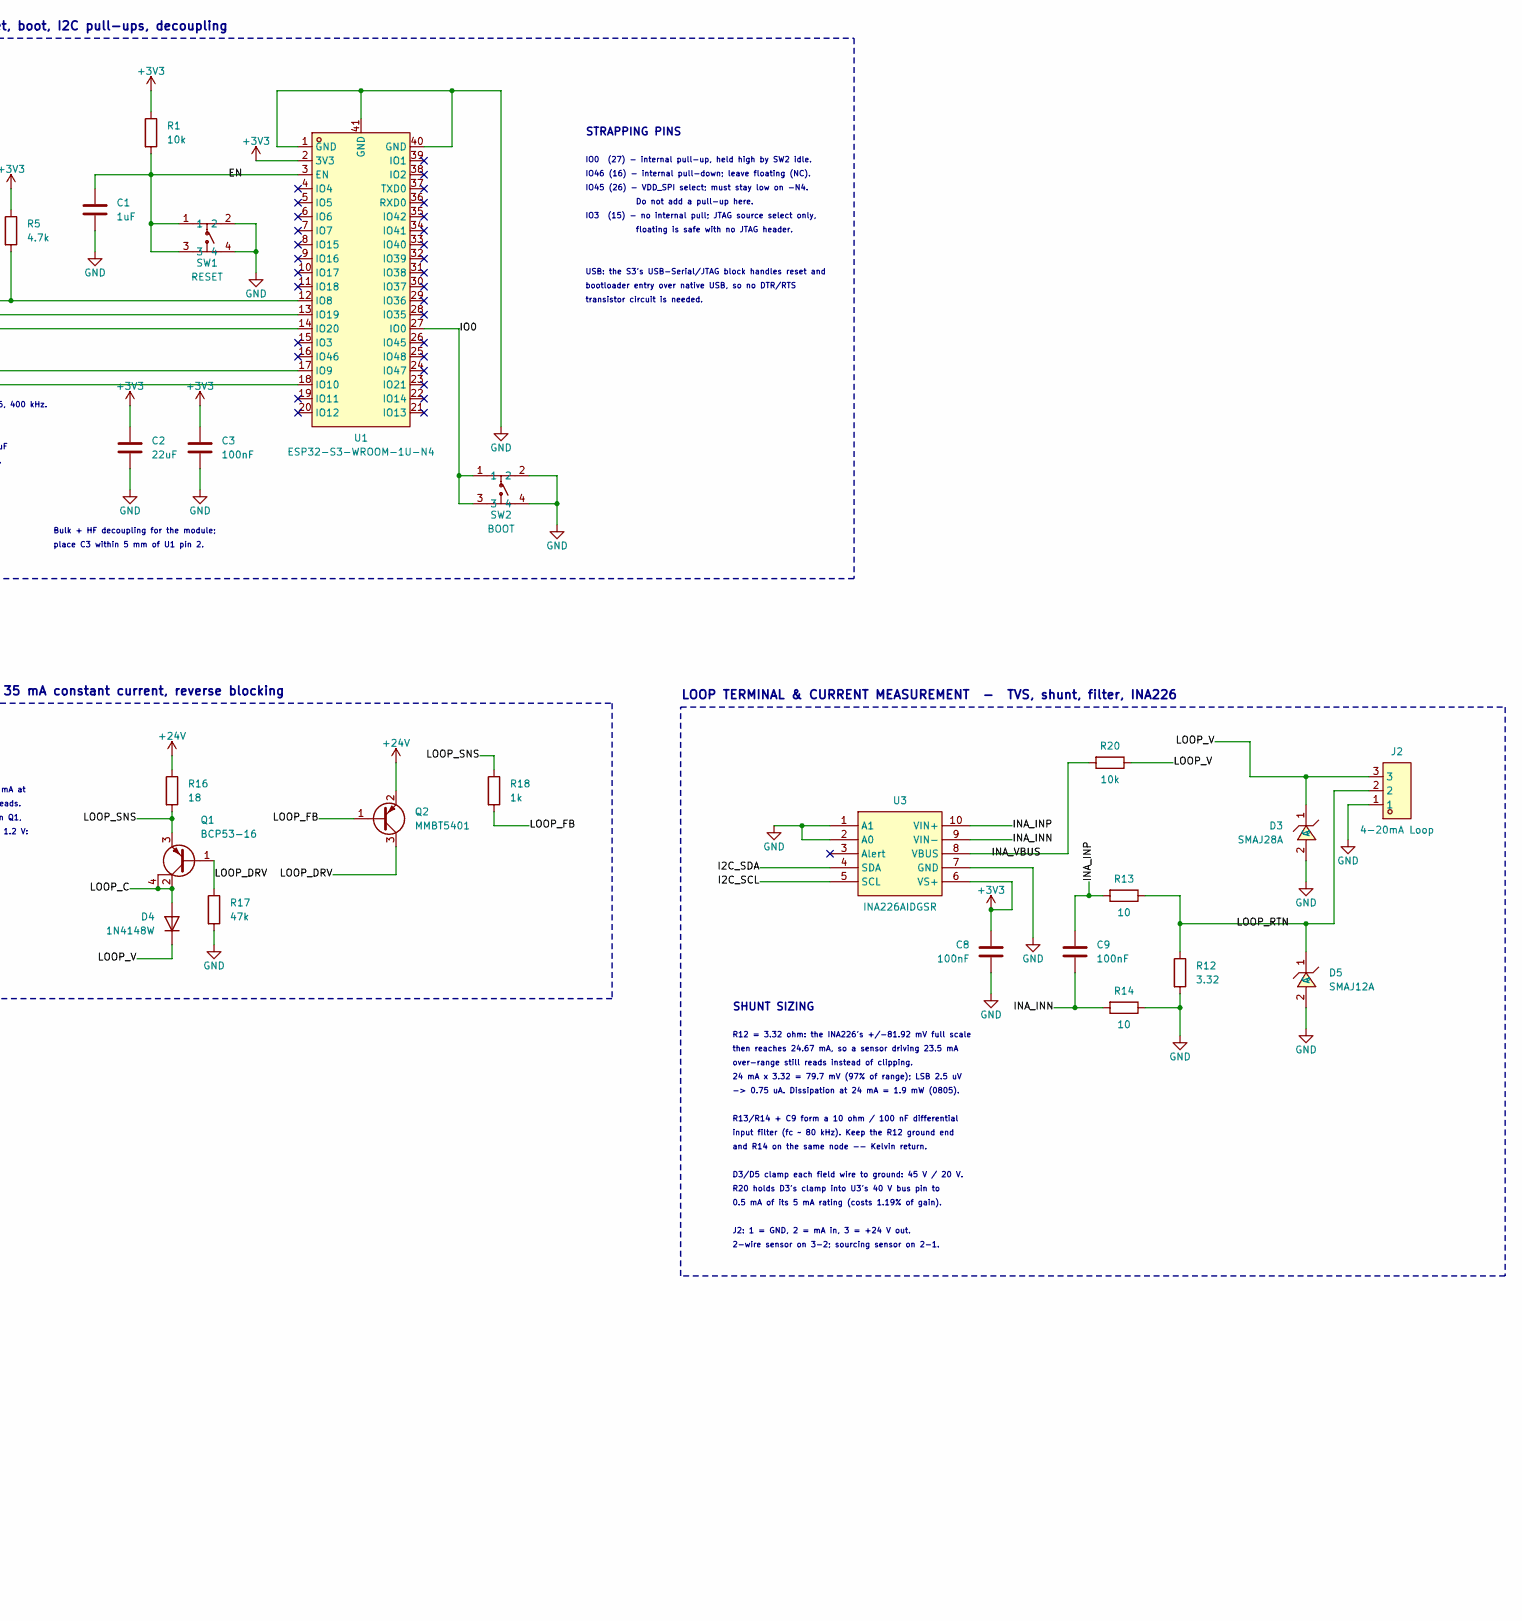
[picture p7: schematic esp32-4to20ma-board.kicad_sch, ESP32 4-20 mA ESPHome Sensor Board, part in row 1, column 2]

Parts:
C1, C6: 1uF; C_0402_1005Metric; MPN CL05A105KA5NQNC; LCSC C52923
C2: 22uF; C_0805_2012Metric; MPN CL21A226MAQNNNE; LCSC C45783
C3, C8, C9, C12: 100nF; C_0402_1005Metric; MPN CL05B104KO5NNNC; LCSC C1525
C7: 10uF; C_0603_1608Metric; MPN CL10A106KP8NNNC; LCSC C19702
C10, C11: 10uF/50V; C_1210_3225Metric; MPN CS3225X7R106K500NRL; LCSC C2918502
D1: USBLC6-2SC6; SOT-23-6_L2.9-W1.6-P0.95-LS2.8-BL; MPN USBLC6-2SC6; LCSC C2687116
D2: SS34; SMA_L4.3-W2.6-LS5.2-RD; MPN SS34; LCSC C8678
D3: SMAJ28A; SMA_L4.3-W2.6-LS5.2-RD; MPN SMAJ28A; LCSC C353458
D4: 1N4148W; D_SOD-123; MPN 1N4148W; LCSC C81598
D5: SMAJ12A; SMA_L4.3-W2.6-LS5.2-RD; MPN SMAJ12A; LCSC C113957
J1: USB-C Receptacle; USB-C-SMD_TYPE-C-16PIN-2MD-073; MPN TYPE-C 16PIN 2MD(073); LCSC C2765186
J2: 4-20mA Loop; CONN-TH_KF250NH-5.0-3P; MPN KF250NH-5.0-3P; LCSC C976567
L1: 22uH; IND-SMD_L4.0-W4.0_FNR40XXS; MPN FNR4030S220MT; LCSC C167883
LED1: Power; LED_0805_2012Metric; MPN NCD0805R1; LCSC C84256
Q1: BCP53-16; SOT-223; MPN BCP53-16; LCSC C148109
Q2: MMBT5401; SOT-23; MPN MMBT5401; LCSC C8326
Q3: AO3401A; SOT-23; MPN AO3401A; LCSC C15127
Q4: 2N7002; SOT-23; MPN 2N7002; LCSC C8545
R1, R11, R20: 10k; R_0402_1005Metric; MPN 0402WGF1002TCE; LCSC C25744
R5, R6: 4.7k; R_0402_1005Metric; MPN 0402WGF4701TCE; LCSC C25900
R7, R8: 5.1k; R_0402_1005Metric; MPN 0402WGF5101TCE; LCSC C25905
R9: 330; R_0402_1005Metric; MPN 0402WGF3300TCE; LCSC C25104
R10, R21: 390k; R_0402_1005Metric; MPN FRC0402F3903TS; LCSC C2909352
R12: 3.32; R_0805_2012Metric; MPN FRC0805F3R32TS; LCSC C3013220
R13, R14: 10; R_0402_1005Metric; MPN 0402WGF100JTCE; LCSC C25077
R15, R22: 100k; R_0402_1005Metric; MPN 0402WGF1003TCE; LCSC C25741
R16: 18; R_0402_1005Metric; MPN RC0402FR-0718RL; LCSC C138043
R17: 47k; R_0402_1005Metric; MPN 0402WGF4702TCE; LCSC C25792
R18: 1k; R_0402_1005Metric; MPN 0402WGF1001TCE; LCSC C11702
SW1: RESET; SW-SMD_4P-L6.0-W6.0-P4.50-LS9.0_H5.0; MPN KH-6X6X5H-STM; LCSC C2837531
SW2: BOOT; SW-SMD_4P-L6.0-W6.0-P4.50-LS9.0_H5.0; MPN KH-6X6X5H-STM; LCSC C2837531
TP1: LOOP_V; TestPoint_Pad_D1.0mm
TP2: LOOP_RTN; TestPoint_Pad_D1.0mm
TP3: +24V; TestPoint_Pad_D1.0mm
TP4: +3V3; TestPoint_Pad_D1.0mm
TP5: MT_EN; TestPoint_Pad_D1.0mm
U1: ESP32-S3-WROOM-1U-N4; WIFIM-SMD_ESP32-S3-WROOM-1U; MPN ESP32-S3-WROOM-1U-N4; LCSC C2980296
U3: INA226AIDGSR; MSOP-10_L3.0-W3.0-P0.50-LS5.0-BL; MPN INA226AIDGSR; LCSC C49851
U4: AP2112K-3.3; SOT-25-5_L2.9-W1.6-P0.95-LS2.8-BL; MPN AP2112K-3.3TRG1; LCSC C51118
U5: MT3608; SOT-23-6_L2.9-W1.6-P0.95-LS2.8-BL; MPN MT3608; LCSC C84817

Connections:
/CC1: J1.A5 (CC1), R7.1
/CC2: J1.B5 (CC2), R8.1
/EN: C1.1, R1.2, SW1.1, SW1.3, U1.3 (EN)
/I2C_SCL: R6.2, U1.17 (IO9), U3.5 (SCL)
/I2C_SDA: R5.2, U1.12 (IO8), U3.4 (SDA)
/INA_INN: C9.2, R14.2, U3.9 (VIN-)
/INA_INP: C9.1, R13.2, U3.10 (VIN+)
/INA_VBUS: R20.2, U3.8 (VBUS)
/IO0: SW2.1, SW2.3, U1.27 (IO0)
/LED_A: LED1.2 (A), R9.2
/LOOP_C: D4.2 (A), Q1.2 (C), Q1.4 (C)
/LOOP_DRV: Q1.1 (B), Q2.3 (C), R17.1
/LOOP_FB: Q2.1 (B), R18.2
/LOOP_RTN: D5.1 (C), J2.2, R12.1, R13.1, TP2.1
/LOOP_SNS: Q1.3 (E), R16.2, R18.1
/LOOP_V: D3.1 (C), D4.1 (K), J2.3, R20.1, TP1.1
/MT_EN: Q4.1 (G), R15.2, TP5.1, U1.18 (IO10)
/MT_FB: R10.2, R11.1, U5.3 (FB)
/MT_SW: D2.2 (A), L1.2, U5.1 (SW)
/SW_GATE: C12.2, Q3.1 (G), R21.2, R22.1
/SW_PD: Q4.3 (D), R22.2
/USB_N: D1.3 (I/O2), D1.4 (I/O2), J1.A7 (Dn1), J1.B7 (Dn2), U1.13 (IO19)
/USB_P: D1.1 (I/O1), D1.6 (I/O1), J1.A6 (Dp1), J1.B6 (Dp2), U1.14 (IO20)

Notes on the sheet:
R12 = 3.32 ohm: the INA226's +/-81.92 mV full scale
Bulk + HF decoupling for the module;
SIGNAL LINKS (net labels)
over the 24 V rail; U5's SW pin is the tight one, 30 V.
+5V USB-C VBUS -> LDO, load switch +3V3 LDO -> ESP32-S3, INA226 +24V boost -> limiter -> loop terminal GND single ground plane
Power LED: (3.3 - 1.9) / 330 = 4.2 mA
VBUS sees 1 uF at attach, not 27 uF (USB limit 10 uF),
24 V BOOST CONVERTER - soft-start load switch, MT3608, feedback
R20 holds D3's clamp into U3's 40 V bus pin to
3.3 V REGULATOR & POWER LED
IO46 (16) - internal pull-down; leave floating (NC).
22.8 V at J2 with 20 mA flowing.
SHUNT SIZING
over-range still reads instead of clipping.
STRAPPING PINS
input filter (fc ~ 80 kHz). Keep the R12 ground end
Load is one 2-wire transmitter at 24 mA max, so the
Dead short: 24 V x 35 mA = 0.85 W in Q1,
IO3 (15) - no internal pull; JTAG source select only,
Worst-case dissipation (5 V in, 3.3 V out, 300 mA)
and MT_EN low now truly disconnects the loop supply.
D3/D5 clamp each field wire to ground: 45 V / 20 V.
Ilim = Vbe(Q2) / R16: 35 / 33 / 27 mA at
then reaches 24.67 mA, so a sensor driving 23.5 mA
-> 0.75 uA. Dissipation at 24 mA = 1.9 mW (0805).
hence SOT-223. R16 + Q1 + D4 cost 1.2 V:
Vout = Vref x (1 + R10/R11), Vref = 0.6 V
LOOP CURRENT LIMITER - 35 mA constant current, reverse blocking
4.7 k pull-ups: one INA226, 400 kHz.
floating is safe with no JTAG header.
R13/R14 + C9 form a 10 ohm / 100 nF differential
POWER RAILS (global power ports)
POWER RAILS & SIGNAL LINKS
bootloader entry over native USB, so no DTR/RTS
LOOP TERMINAL & CURRENT MEASUREMENT - TVS, shunt, filter, INA226
TEST POINTS
= 0.51 W -- well inside SOT-25 on 2 oz copper.
J2: 1 = GND, 2 = mA in, 3 = +24 V out.
CC1/CC2 pulldowns: 5.1 k = UFP,
gives a ~10 ms rise on EN.

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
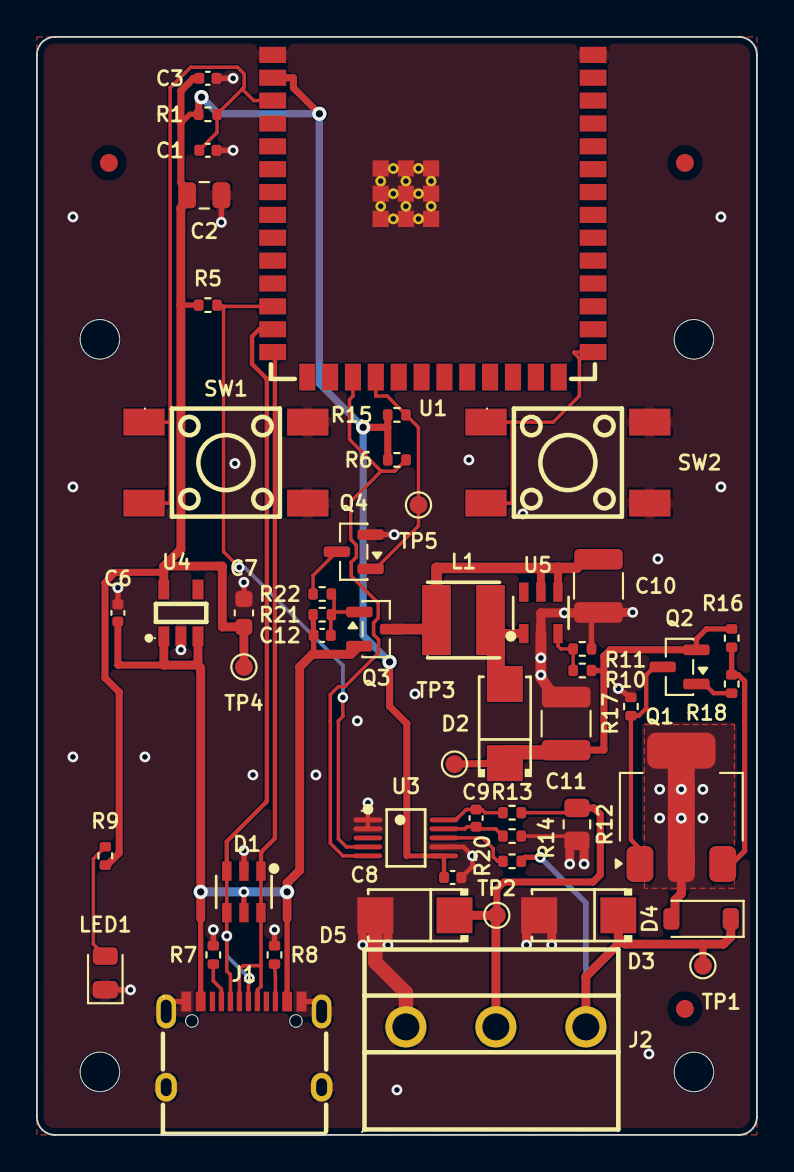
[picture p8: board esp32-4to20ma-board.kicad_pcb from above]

Board: 2 copper layers, 40.0 x 61.0 mm, 59 parts (0 on the bottom side), 28 nets.

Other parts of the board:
FID1, FID2, FID3: Fiducial_1mm_Mask2mm
H1, H2, H3, H4: MountingHole_2.2mm

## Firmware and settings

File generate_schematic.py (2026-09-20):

#!/usr/bin/env python3
"""Generates the ESP32 4-20 mA ESPHome board schematic: one sheet.

The design is small enough (~50 parts) that hierarchy only adds page-flipping,
so it is one sheet of titled blocks, ONE BLOCK PER CIRCUIT, in signal order:

    USB-C input & ESD  ->  3.3 V regulator  ->  ESP32-S3 module
    24 V boost converter  ->  loop current limiter  ->  loop terminal & measurement
    test points, sheet notes

A block is a whole circuit -- the boost converter with its load switch, input
and output, not three boxes for the three of them; the module with its reset,
boot, pull-ups and decoupling, not "module" and "support". That is how the
reference sheets for these parts are drawn (Adafruit's ESP32-S3 Feather:
"POWER AND FILTERING", "USB TO SERIAL CONVERTER", "LIPO CHARGING", and the
module with everything that serves it in one region).

Each block is drawn in its own working coordinates inside s.block_start() /
s.block_end(). schlib derives the outline from what is inside -- parts, field
text, labels, notes -- plus a margin, and arrange() flows the blocks across the
page, so an outline can never cut through a label and no rectangle is typed by
hand. check_text() then reads KiCad's own render and fails on any string that
touches an outline. Blocks connect by net name: rails through power ports,
signals through net labels.

    python generate_schematic.py [--force]

Edit this script, not the .kicad_sch -- it is regenerated. schlib.py is the
builder (copied from the kicad-schematic-layout skill). write() refuses to
overwrite a sheet that was changed in KiCad since the last run; port those
edits here, then rerun with --force.
"""
import argparse
import os
import sys

PROJDIR = os.path.dirname(os.path.abspath(__file__))
sys.path.insert(0, PROJDIR)
from schlib import Design, snap  # noqa: E402

REV = "G"
DATE = "2026-09-20"
LIB = "esp32_4to20ma_lib"
ROOT_FILE = "esp32-4to20ma-board.kicad_sch"


def fp(name):
    return f"{LIB}:{name}"


# ---------------------------------------------------------------------------
# Bill of materials: ref -> (lib_id, value, footprint, LCSC, manufacturer, MPN)
# ---------------------------------------------------------------------------
TP_FP = "TestPoint:TestPoint_Pad_D1.0mm"

PARTS = {
    # The -1U: U.FL connector, no PCB antenna. Same symbol, same pins, and --
    # per Espressif's own land-pattern figures -- the same pads, so the board
    # is untouched. To go back to the PCB-antenna module, restore this line:
    #   fp("WIFIM-SMD_ESP32-S3-WROOM-1-N8"), "C2913197", "Espressif", "ESP32-S3-WROOM-1-N4"
    # The board outline, the antenna overhang and the mounting holes are all
    # still laid out for it.
    "U1":  (f"{LIB}:ESP32-S3-WROOM-1-N4", "ESP32-S3-WROOM-1U-N4",
            fp("WIFIM-SMD_ESP32-S3-WROOM-1U"), "C2980296", "Espressif", "ESP32-S3-WROOM-1U-N4"),
    "U3":  (f"{LIB}:INA226AIDGSR", "INA226AIDGSR",
            fp("MSOP-10_L3.0-W3.0-P0.50-LS5.0-BL"), "C49851", "Texas Instruments", "INA226AIDGSR"),
    "U4":  (f"{LIB}:AP2112K-3.3TRG1", "AP2112K-3.3",
            fp("SOT-25-5_L2.9-W1.6-P0.95-LS2.8-BL"), "C51118", "Diodes Inc", "AP2112K-3.3TRG1"),
    "U5":  (f"{LIB}:MT3608", "MT3608",
            fp("SOT-23-6_L2.9-W1.6-P0.95-LS2.8-BL"), "C84817", "Aerosemi", "MT3608"),
    "J1":  (f"{LIB}:TYPE-C16PIN2MD", "USB-C Receptacle",
            fp("USB-C-SMD_TYPE-C-16PIN-2MD-073"), "C2765186", "SHOU HAN", "TYPE-C 16PIN 2MD(073)"),
    # One-piece push-in spring terminal (WAGO-250 style): a solid or ferruled
    # wire pushes straight in, the button releases it or opens it for bare
    # stranded. Three pins: GND, mA in, +24 V out. The ground pin is what lets
    # a 3-wire or self-powered (sourcing) transmitter be connected at all.
    # Numbered from the left looking into the wire entry, which puts +24 V on
    # the right under the limiter and GND on the left beside D5's anode.
    "J2":  (f"{LIB}:KF250NH-5.0-3P", "4-20mA Loop",
            fp("CONN-TH_KF250NH-5.0-3P"), "C976567", "Cixi Kefa", "KF250NH-5.0-3P"),
    "D1":  (f"{LIB}:USBLC6-2SC6_C2687116", "USBLC6-2SC6",
            fp("SOT-23-6_L2.9-W1.6-P0.95-LS2.8-BL"), "C2687116", "UMW", "USBLC6-2SC6"),
    "D2":  (f"{LIB}:SS34_C8678", "SS34",
            fp("SMA_L4.3-W2.6-LS5.2-RD"), "C8678", "MDD", "SS34"),
    # Both TVS parts share the project's unidirectional TVS symbol (1 = K, 2 = A).
    "D3":  (f"{LIB}:SMAJ36A_C113967", "SMAJ28A",
            fp("SMA_L4.3-W2.6-LS5.2-RD"), "C353458", "Jingdao Microelectronics", "SMAJ28A"),
    "D5":  (f"{LIB}:SMAJ36A_C113967", "SMAJ12A",
            fp("SMA_L4.3-W2.6-LS5.2-RD"), "C113957", "MDD", "SMAJ12A"),
    # Blocks LOOP_V from driving Q1 backwards into the 24 V rail. Deliberately
    # not a Schottky: it sees D3's clamp minus the rail in reverse.
    "D4":  ("Diode:1N4148W", "1N4148W",
            "Diode_SMD:D_SOD-123", "C81598", "ST (Semtech)", "1N4148W"),
    "SW1": (f"{LIB}:KH-6X6X5H-STM", "RESET",
            fp("SW-SMD_4P-L6.0-W6.0-P4.50-LS9.0_H5.0"), "C2837531", "Kinghelm", "KH-6X6X5H-STM"),
    "SW2": (f"{LIB}:KH-6X6X5H-STM", "BOOT",
            fp("SW-SMD_4P-L6.0-W6.0-P4.50-LS9.0_H5.0"), "C2837531", "Kinghelm", "KH-6X6X5H-STM"),
    # 22 uH, the top of the MT3608's 4.7-22 uH range: at ~0.17 A average input
    # it quarters the ripple current of the old 4.7 uH. Isat 1.2 A.
    "L1":  (f"{LIB}:FNR4030S4R7MT", "22uH",
            fp("IND-SMD_L4.0-W4.0_FNR40XXS"), "C167883", "cjiang", "FNR4030S220MT"),

    "R1":  ("Device:R", "10k",   "Resistor_SMD:R_0402_1005Metric", "C25744", "Uniroyal", "0402WGF1002TCE"),
    "R5":  ("Device:R", "4.7k",  "Resistor_SMD:R_0402_1005Metric", "C25900", "Uniroyal", "0402WGF4701TCE"),
    "R6":  ("Device:R", "4.7k",  "Resistor_SMD:R_0402_1005Metric", "C25900", "Uniroyal", "0402WGF4701TCE"),
    "R7":  ("Device:R", "5.1k",  "Resistor_SMD:R_0402_1005Metric", "C25905", "Uniroyal", "0402WGF5101TCE"),
    "R8":  ("Device:R", "5.1k",  "Resistor_SMD:R_0402_1005Metric", "C25905", "Uniroyal", "0402WGF5101TCE"),
    "R9":  ("Device:R", "330",   "Resistor_SMD:R_0402_1005Metric", "C25104", "Uniroyal", "0402WGF3300TCE"),
    "R10": ("Device:R", "390k",  "Resistor_SMD:R_0402_1005Metric", "C2909352", "FOJAN", "FRC0402F3903TS"),   # C25782 had 14 in stock
    "R11": ("Device:R", "10k",   "Resistor_SMD:R_0402_1005Metric", "C25744", "Uniroyal", "0402WGF1002TCE"),
    "R12": ("Device:R", "3.32",  "Resistor_SMD:R_0805_2012Metric", "C3013220", "FOJAN", "FRC0805F3R32TS"),
    "R13": ("Device:R", "10",    "Resistor_SMD:R_0402_1005Metric", "C25077", "Uniroyal", "0402WGF100JTCE"),
    "R14": ("Device:R", "10",    "Resistor_SMD:R_0402_1005Metric", "C25077", "Uniroyal", "0402WGF100JTCE"),
    "R15": ("Device:R", "100k",  "Resistor_SMD:R_0402_1005Metric", "C25741", "Uniroyal", "0402WGF1003TCE"),
    # --- current limiter on the 24 V loop feed (R19, the foldback, is gone) ---
    "R16": ("Device:R", "18",    "Resistor_SMD:R_0402_1005Metric", "C138043", "Yageo", "RC0402FR-0718RL"),
    "R17": ("Device:R", "47k",   "Resistor_SMD:R_0402_1005Metric", "C25792", "Uniroyal", "0402WGF4702TCE"),
    "R18": ("Device:R", "1k",    "Resistor_SMD:R_0402_1005Metric", "C11702", "Uniroyal", "0402WGF1001TCE"),
    # Series protection for the INA226 bus-voltage pin -- see the note on
    # sheet 4. Same part as R1/R11, so it adds no BOM line.
    "R20": ("Device:R", "10k",   "Resistor_SMD:R_0402_1005Metric", "C25744", "Uniroyal", "0402WGF1002TCE"),
    # --- soft-start load switch ahead of the boost ---
    "Q3":  ("Transistor_FET:AO3401A", "AO3401A",
            "Package_TO_SOT_SMD:SOT-23", "C15127", "Alpha & Omega", "AO3401A"),
    "Q4":  ("Transistor_FET:2N7002", "2N7002",
            "Package_TO_SOT_SMD:SOT-23", "C8545", "JSCJ", "2N7002"),
    "R21": ("Device:R", "390k",  "Resistor_SMD:R_0402_1005Metric", "C2909352", "FOJAN", "FRC0402F3903TS"),
    "R22": ("Device:R", "100k",  "Resistor_SMD:R_0402_1005Metric", "C25741", "Uniroyal", "0402WGF1003TCE"),
    "C12": ("Device:C", "100nF",    "Capacitor_SMD:C_0402_1005Metric", "C1525",  "Samsung Electro-Mechanics", "CL05B104KO5NNNC"),
    # Q1 is SOT-223 because a constant-current limiter puts the whole rail
    # across it in a short: 24 V x 35 mA = 0.85 W. hFE >= 100 against 0.5 mA of
    # base drive from R17 supports 50 mA. Pins: 1 B, 2 and 4 (tab) C, 3 E.
    "Q1":  ("Transistor_BJT:BCP53", "BCP53-16",
            "Package_TO_SOT_SMD:SOT-223", "C148109", "JSCJ", "BCP53-16"),
    # C8326 is LCSC's hFE 200-300 bin of the MMBT5401, a JLCPCB basic part.
    "Q2":  ("Transistor_BJT:Q_PNP_BEC", "MMBT5401",
            "Package_TO_SOT_SMD:SOT-23", "C8326", "JSCJ", "MMBT5401"),

    "C1":  ("Device:C", "1uF",      "Capacitor_SMD:C_0402_1005Metric", "C52923", "Samsung Electro-Mechanics", "CL05A105KA5NQNC"),
    "C2":  ("Device:C", "22uF",     "Capacitor_SMD:C_0805_2012Metric", "C45783", "Samsung Electro-Mechanics", "CL21A226MAQNNNE"),
    "C3":  ("Device:C", "100nF",    "Capacitor_SMD:C_0402_1005Metric", "C1525",  "Samsung Electro-Mechanics", "CL05B104KO5NNNC"),
    "C6":  ("Device:C", "1uF",      "Capacitor_SMD:C_0402_1005Metric", "C52923", "Samsung Electro-Mechanics", "CL05A105KA5NQNC"),
    "C7":  ("Device:C", "10uF",     "Capacitor_SMD:C_0603_1608Metric", "C19702", "Samsung Electro-Mechanics", "CL10A106KP8NNNC"),
    "C8":  ("Device:C", "100nF",    "Capacitor_SMD:C_0402_1005Metric", "C1525",  "Samsung Electro-Mechanics", "CL05B104KO5NNNC"),
    "C9":  ("Device:C", "100nF",    "Capacitor_SMD:C_0402_1005Metric", "C1525",  "Samsung Electro-Mechanics", "CL05B104KO5NNNC"),
    "C10": ("Device:C", "10uF/50V", "Capacitor_SMD:C_1210_3225Metric", "C2918502", "Samwha", "CS3225X7R106K500NRL"),
    "C11": ("Device:C", "10uF/50V", "Capacitor_SMD:C_1210_3225Metric", "C2918502", "Samwha", "CS3225X7R106K500NRL"),

    "LED1": ("Device:LED", "Power", "LED_SMD:LED_0805_2012Metric", "C84256", "Nationstar", "NCD0805R1"),

    # Bare copper, not purchased parts: LCSC None marks them out of the BOM.
    # The value is the net, so the fab drawing and the board both name it.
    "TP1": ("Connector:TestPoint", "LOOP_V",   TP_FP, None, None, None),
    "TP2": ("Connector:TestPoint", "LOOP_RTN", TP_FP, None, None, None),
    "TP3": ("Connector:TestPoint", "+24V",     TP_FP, None, None, None),
    "TP4": ("Connector:TestPoint", "+3V3",     TP_FP, None, None, None),
    "TP5": ("Connector:TestPoint", "MT_EN",    TP_FP, None, None, None),
}


def put(sheet, ref, x, y, rot=0, mirror=None):
    lib_id, value, footprint, lcsc, mfr, mpn = PARTS[ref]
    if lcsc is None:
        # a pad, not a part: nothing to order, so keep it out of the BOM
        sheet.place(ref, lib_id, value, x, y, rot, mirror,
                    props={"Footprint": footprint}, in_bom=False)
        return
    sheet.place(ref, lib_id, value, x, y, rot, mirror, props={
        "Footprint": footprint,
        "Datasheet": f"https://www.lcsc.com/product-detail/{lcsc}.html",
        "LCSC": lcsc,
        "Manufacturer": mfr,
        "MPN": mpn,
    })


# ---------------------------------------------------------------------------
# Intended netlist -- the specification the drawn sheets must reproduce.
# verify_schematic.py diffs KiCad's own extracted netlist against this.
# ---------------------------------------------------------------------------
NETS = {
    "GND": [
        ("U1", "1"), ("U1", "40"), ("U1", "41"),
        ("U3", "1"), ("U3", "2"), ("U3", "7"),
        ("U4", "2"), ("U5", "2"),
        ("J1", "A1B12"), ("J1", "B1A12"), ("J1", "13"), ("J1", "14"),
        ("D1", "2"),
        ("SW1", "2"), ("SW1", "4"), ("SW2", "2"), ("SW2", "4"),
        ("LED1", "1"),
        ("C1", "2"), ("C2", "2"), ("C3", "2"), ("C6", "2"), ("C7", "2"),
        ("C8", "2"), ("C10", "2"), ("C11", "2"),
        ("R7", "2"), ("R8", "2"), ("R11", "2"), ("R12", "2"), ("R14", "1"),
        ("R17", "2"), ("Q4", "2"), ("D3", "2"), ("D5", "2"), ("J2", "1"),
    ],
    "+3V3": [
        ("U1", "2"), ("U3", "6"), ("U4", "5"),
        ("R1", "1"), ("R5", "1"), ("R6", "1"), ("R9", "1"), ("R15", "1"),
        ("C2", "1"), ("C3", "1"), ("C7", "1"), ("C8", "1"), ("TP4", "1"),
    ],
    "+5V": [
        ("U4", "1"), ("U4", "3"),
        ("J1", "A4B9"), ("J1", "B4A9"), ("D1", "5"), ("C6", "1"),
        ("Q3", "2"), ("R21", "1"), ("C12", "1"),
    ],
    # Everything the boost hangs on VBUS sits behind Q3, so a USB host sees
    # only C6 (1 uF) at attach. U5's EN rides on its own input.
    "VIN_SW":  [("Q3", "3"), ("U5", "5"), ("U5", "4"), ("L1", "1"), ("C10", "1")],
    "SW_GATE": [("Q3", "1"), ("R21", "2"), ("C12", "2"), ("R22", "1")],
    "SW_PD":   [("R22", "2"), ("Q4", "3")],
    # The rail now stops at the limiter; everything downstream is LOOP_V.
    "+24V": [
        ("D2", "1"), ("C11", "1"), ("R10", "1"), ("R16", "1"), ("Q2", "2"),
        ("TP3", "1"),
    ],
    "LOOP_SNS": [("R16", "2"), ("Q1", "3"), ("R18", "1")],
    "LOOP_DRV": [("Q1", "1"), ("Q2", "3"), ("R17", "1")],
    "LOOP_FB":  [("Q2", "1"), ("R18", "2")],
    "LOOP_C":   [("Q1", "2"), ("Q1", "4"), ("D4", "2")],
    "LOOP_V":   [("D4", "1"), ("J2", "3"), ("D3", "1"), ("R20", "1"), ("TP1", "1")],
    "INA_VBUS": [("R20", "2"), ("U3", "8")],
    "USB_P":   [("J1", "A6"), ("J1", "B6"), ("D1", "1"), ("D1", "6"), ("U1", "14")],
    "USB_N":   [("J1", "A7"), ("J1", "B7"), ("D1", "3"), ("D1", "4"), ("U1", "13")],
    "CC1":      [("J1", "A5"), ("R7", "1")],
    "CC2":      [("J1", "B5"), ("R8", "1")],
    "EN":       [("U1", "3"), ("R1", "2"), ("SW1", "1"), ("SW1", "3"), ("C1", "1")],
    "IO0":      [("U1", "27"), ("SW2", "1"), ("SW2", "3")],
    "I2C_SDA":  [("U1", "12"), ("U3", "4"), ("R5", "2")],
    "I2C_SCL":  [("U1", "17"), ("U3", "5"), ("R6", "2")],
    "MT_SW":    [("U5", "1"), ("L1", "2"), ("D2", "2")],
    "LOOP_RTN": [("J2", "2"), ("R12", "1"), ("R13", "1"), ("D5", "1"), ("TP2", "1")],
    "INA_INP":  [("R13", "2"), ("U3", "10"), ("C9", "1")],
    "INA_INN":  [("R14", "2"), ("U3", "9"), ("C9", "2")],
    "MT_FB":    [("U5", "3"), ("R10", "2"), ("R11", "1")],
    "MT_EN":    [("U1", "18"), ("Q4", "1"), ("R15", "2"), ("TP5", "1")],
    "LED_A":    [("R9", "2"), ("LED1", "2")],
}

NO_CONNECT = [
    # Unused ESP32-S3 GPIOs. Native USB replaces UART0 for flashing and logging,
    # so U0RXD/U0TXD are deliberately left unconnected too.
    ("U1", n) for n in [
        "4", "5", "6", "7", "8", "9", "10", "11", "15", "16", "19", "20",
        "21", "22", "23", "24", "25", "26", "28", "29", "30", "31", "32", "33",
        "34", "35", "36", "37", "38", "39"]
] + [("U3", "3"), ("U4", "4"), ("U5", "6"), ("J1", "A8"), ("J1", "B8")]


# ===========================================================================
# Sheet 1 -- USB-C input, ESD protection, 3.3 V regulation, power LED
# ===========================================================================
def build_usb_power(s):
    s.block_start("USB-C INPUT & ESD PROTECTION")

    # ---- USB-C receptacle -------------------------------------------------
    put(s, "J1", 45.72, 67.31, 180)

    # Both signal grounds and both shell tabs collect onto a rail down the left
    # side of the connector, ending in a single ground port at the bottom.
    s.wire(s.pin("J1", "B1A12"), (52.07, 48.26), (27.94, 48.26))
    # The bottom ground route runs a clear 7.6 mm below the connector body so
    # J1's reference and value have room underneath it -- the connector is
    # otherwise walled in by wires on all four sides.
    s.wire((27.94, 48.26), (27.94, 93.98))
    s.wire(s.pin("J1", "14"), (27.94, 53.34))
    s.wire(s.pin("J1", "13"), (27.94, 81.28))
    s.wire(s.pin("J1", "A1B12"), (57.15, 81.28), (57.15, 91.44), (27.94, 91.44))
    s.gnd(27.94, 93.98)
    # GND and +5V originate at this connector, so the ERC power-source flags
    # for both rails belong here.
    s.wire((27.94, 93.98), (19.05, 93.98))
    s.power("PWR_FLAG", 19.05, 93.98)

    # VBUS: both pairs straight out to +5V ports.
    s.wire(s.pin("J1", "B4A9"), (60.96, 55.88), (68.58, 55.88))
    s.power("+5V", 60.96, 55.88)
    s.power("PWR_FLAG", 68.58, 55.88)
    s.wire(s.pin("J1", "A4B9"), (60.96, 78.74))
    s.power("+5V", 60.96, 78.74)

    # CC pins -> 5.1 k pulldowns (advertise UFP, sink 5 V / default current).
    s.wire(s.pin("J1", "B5"), (66.04, 58.42))
    s.label("CC2", 66.04, 58.42)
    s.wire(s.pin("J1", "A5"), (66.04, 73.66))
    s.label("CC1", 66.04, 73.66)

    put(s, "R7", 74.93, 96.52)
    put(s, "R8", 87.63, 96.52)
    s.wire(s.pin("R7", "1"), (74.93, 88.9))
    s.label("CC1", 74.93, 88.9, 90)
    s.wire(s.pin("R8", "1"), (87.63, 88.9))
    s.label("CC2", 87.63, 88.9, 90)
    s.wire(s.pin("R7", "2"), (74.93, 104.14))
    s.gnd(74.93, 104.14)
    s.wire(s.pin("R8", "2"), (87.63, 104.14))
    s.gnd(87.63, 104.14)
    s.note("CC1/CC2 pulldowns: 5.1 k = UFP,", 68.58, 111.76, 1.0)
    s.note("advertises default 500 mA USB 2.0 sink.", 68.58, 114.3, 1.0)

    # Both D+ halves and both D- halves of the reversible connector.
    for pin, y, name in (("B6", 63.5, "USB_P"), ("A7", 66.04, "USB_N"),
                         ("A6", 68.58, "USB_P"), ("B7", 71.12, "USB_N")):
        s.wire(s.pin("J1", pin), (66.04, y))
        s.label(name, 66.04, y)

    s.nc("J1", "A8", "B8")

    # ---- ESD clamp --------------------------------------------------------
    # Rotated 90 so VBUS faces up and GND down. In its native orientation GND
    # sits *between* the two data pins on the same side, so any ground wire
    # leaving it has to cross the D- line or its label. Connector-side data
    # leaves the bottom, MCU-side data the top, each turning outward.
    put(s, "D1", 99.06, 66.04, 90)
    s.stub("D1", "2", 2.54, power="GND")
    s.stub("D1", "5", 2.54, power="+5V")
    s.wire(s.pin("D1", "1"), (96.52, 82.55), (91.44, 82.55))
    s.label("USB_P", 91.44, 82.55, 180)
    s.wire(s.pin("D1", "3"), (101.6, 82.55), (106.68, 82.55))
    s.label("USB_N", 106.68, 82.55)
    s.wire(s.pin("D1", "6"), (96.52, 49.53), (91.44, 49.53))
    s.label("USB_P", 91.44, 49.53, 180)
    s.wire(s.pin("D1", "4"), (101.6, 49.53), (106.68, 49.53))
    s.label("USB_N", 106.68, 49.53)
    s.note("D1 ESD clamp\n15 kV air /\n8 kV contact\n(IEC 61000-4-2)", 105.41, 60.96, 1.0)

    s.block_end()

    # ---- 3.3 V LDO --------------------------------------------------------
    s.block_start("3.3 V REGULATOR & POWER LED")
    put(s, "U4", 152.4, 66.04)
    put(s, "C6", 133.35, 69.85)      # 5 V input cap
    put(s, "C7", 187.96, 69.85)      # 3.3 V output cap

    # 5 V rail into VIN, with the input cap hanging off it.
    s.wire(s.pin("U4", "1"), (128.27, 63.5))
    s.wire((128.27, 63.5), (128.27, 57.15))
    s.power("+5V", 128.27, 57.15)
    s.wire(s.pin("C6", "1"), (133.35, 63.5))
    s.wire(s.pin("C6", "2"), (133.35, 77.47))
    s.gnd(133.35, 77.47)

    # EN tied high -- the LDO has no shutdown control on this board.
    s.wire(s.pin("U4", "3"), (137.16, 68.58))
    s.power("+5V", 137.16, 68.58)
    s.wire(s.pin("U4", "2"), (135.89, 66.04), (135.89, 82.55))
    s.gnd(135.89, 82.55)
    s.nc("U4", "4")

    # 3.3 V output rail.
    s.wire(s.pin("U4", "5"), (196.85, 63.5))
    s.wire(s.pin("C7", "1"), (187.96, 63.5))
    s.wire(s.pin("C7", "2"), (187.96, 77.47))
    s.gnd(187.96, 77.47)
    s.wire((196.85, 63.5), (196.85, 57.15))
    s.power("+3V3", 196.85, 57.15)
    s.wire((191.77, 63.5), (191.77, 55.88))
    s.power("PWR_FLAG", 191.77, 55.88)
    s.note("AP2112K-3.3: 600 mA LDO, 250 mV dropout.", 124.46, 92.71, 1.0)
    s.note("Worst-case dissipation (5 V in, 3.3 V out, 300 mA)", 124.46, 95.25, 1.0)
    s.note("= 0.51 W -- well inside SOT-25 on 2 oz copper.", 124.46, 97.79, 1.0)

    # ---- Power-on LED -----------------------------------------------------
    # Sits under the regulator rather than beside it, so the sheet stays a
    # sensible shape instead of running off to the right.
    put(s, "R9", 140.97, 119.38)
    put(s, "LED1", 140.97, 133.35, 90)  # anode up (from R9), cathode down to GND
    s.wire(s.pin("R9", "1"), (140.97, 111.76))
    s.power("+3V3", 140.97, 111.76)
    s.wire(s.pin("R9", "2"), s.pin("LED1", "2"))
    # horizontal: a vertical label here runs straight up through R9's body
    s.label("LED_A", 140.97, 125.73)
    s.wire(s.pin("LED1", "1"), (140.97, 140.97))
    s.gnd(140.97, 140.97)
    s.note("Power LED: (3.3 - 1.9) / 330 = 4.2 mA", 149.86, 130.81, 1.0)

    s.block_end()
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

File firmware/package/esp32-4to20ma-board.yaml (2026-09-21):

# =============================================================================
# ESP32 4-20 mA ESPHome Sensor Board  --  shared package, Rev G hardware
# =============================================================================
#
# This file is the whole instrument: board definition, I2C, the INA226, the
# calibration chain, the fault classifier and the short-circuit protection.
# It is meant to be pulled in by a short per-device file, which supplies only
# a name, a Wi-Fi network and the process scaling:
#
#   packages:
#     loop_board: github://Diode663/ESP32_4-20mA_Sensor/firmware/package/esp32-4to20ma-board.yaml@main
#
# See ../loop-sensor-1.yaml for a complete example, and ../README.md for the
# calibration procedure.
#
# -----------------------------------------------------------------------------
# The hardware this file assumes (all of it read out of the board's netlist,
# not a generic template -- see ../../netlist_report.txt)
# -----------------------------------------------------------------------------
#   INA226        I2C 0x40  (U3 pins A0 and A1 both strapped to GND)
#   I2C bus       SDA = GPIO8 (U1 pin 12), SCL = GPIO9 (U1 pin 17), 4.7k pull-ups
#   Shunt         R12 = 3.32 ohm, LOW SIDE, between LOOP_RTN and GND.
#                 VIN+ on LOOP_RTN, VIN- on GND, so loop current reads POSITIVE
#                 and a backwards sourcing transmitter reads NEGATIVE.
#   Full scale    the INA226's shunt input is fixed at +/-81.92 mV with no PGA,
#                 so 3.32 ohm puts the ceiling at 24.67 mA. Above that the ADC
#                 clips -- that is NOT the hardware limiter, which is at ~33 mA.
#   VBUS pin      reads LOOP_V through R20 = 10k into the INA226's 830k input
#                 impedance, so the chip sees 830/840 of the truth -> x1.01205
#   Loop power    MT_EN = GPIO10 (U1 pin 18). HIGH = loop supply ON.
#                 R15 (100k to 3V3) holds it HIGH, so the loop is powered from
#                 the instant 3V3 comes up, before ESPHome runs. See `switch:`.
#   Buttons       SW1 = EN (hardware reset, invisible to firmware)
#                 SW2 = GPIO0 (strapping pin, free to read after boot)
#   LED1          hardwired +3V3 -> R9 -> LED1. NOT controllable. There is no
#                 user LED on this board; all status goes to Home Assistant.
#   USB           native, IO19/IO20, so the logger's default USB_SERIAL_JTAG is
#                 the right console -- there is no UART bridge to fall back on.
#   Flash         N4 module: 4 MB, NO PSRAM. With OTA that leaves about 1.9 MB
#                 for the application. Do not add `psram:`, and think twice
#                 before adding anything that pulls in Bluetooth.
# =============================================================================

substitutions:
  # Every one of these is meant to be overridden by the device file.
  device_name: "loop-sensor"
  friendly_name: "Loop Sensor"

  # --- Hardware constants. Only change these if the board changes. ----------
  shunt_ohms: "3.32"          # R12
  vbus_gain: "1.01205"        # (830k + R20 10k) / 830k
  adc_ceiling_ma: "24.67"     # 81.92 mV / 3.32 ohm -- the INA226 clips here

  # --- Factory calibration --------------------------------------------------
  # The reference currents you will feed in, and the raw readings you get back.
  # Defaults are the identity. These are only the STARTING point: the
  # "Calibrate" buttons overwrite them at runtime and the result survives a
  # reboot. See ../README.md.
  cal_ref_low: "4.000"
  cal_ref_high: "20.000"
  cal_meas_low: "4.000"
  cal_meas_high: "20.000"
  cal_capture_window: "2.0"   # refuse to capture further than this from the reference

  # --- Process variable: what the 4-20 mA actually represents --------------
  pv_name: "Process value"
  pv_unit: "%"
  pv_min: "0.0"               # engineering units at 4 mA
  pv_max: "100.0"             # engineering units at 20 mA
  pv_decimals: "2"
  pv_sqrt: "false"            # true for a DP transmitter measuring flow

  # --- NAMUR NE43 thresholds, in mA ----------------------------------------
  ne43_fail_low: "3.6"
  ne43_under: "3.8"
  ne43_over: "20.5"
  ne43_fail_high: "21.0"

  # --- Loop supply health --------------------------------------------------
  loop_v_low: "20.0"          # below this with current flowing = not trustworthy
  loop_v_short: "3.0"         # below this = the field pair is shorted
  open_circuit_ma: "0.1"      # below this = nothing connected / wire broken
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

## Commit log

2026-09-20 Rev G: board placed, ESPHome firmware, licences
    Single-channel industrial 4-20 mA current-loop reader, USB-C powered,
    built for ESPHome. KiCad 10, schematic and placement both generated from
    Python.
    Hardware (Rev G, placed but not routed):
    - 28 nets / 35 no-connects match the specification exactly, ERC 0 errors,
    schematic parity clean, placement DRC 4 (all deliberate silk-at-edge)
    plus 5 library-internal, 52 parts + 4 holes + 3 fiducials.
    - Constant-current loop limiter, series blocking diode, one TVS per field
    wire to ground, soft-start USB load switch. Every circuit change was
    simulated first; the ngspice decks are in sim/.
    - ESP32-S3-WROOM-1U-N4 with a U.FL connector, fitted with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
    [bom.csv, esp32-4to20ma-board.kicad_pcb, esp32-4to20ma-board.kicad_sch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]
2026-09-20 firmware: pull the package from GitHub now the repo is public
    The device file is the thin per-board half of the split, so it should
    track the shared definition rather than a copy sitting next to it. Keeps
    the local !include documented for working on the package itself, where
    github://@main would silently compile the last PUSHED version instead of
    what is on disk.
2026-09-20 docs: describe the firmware as a published remote package
    [esp32-4to20ma-board.dsn, esp32-4to20ma-board.kicad_pcb, placed_backup.kicad_pcb]
2026-09-20 Rev G: board routed, schematic regrouped, JLCPCB package
    Routing
    - route_board.py on routelib.py: the MT3608 loop (datasheet Figure 3), the
    INA226 Kelvin taps (Figure 30), the USB-C entry and pair, the power trunks,
    the 24 V loop, Q1's copper on both layers, every ground via and both pours
    are scripted; ten signal nets are Freerouting 2.4.1's, stored in
    routing/autoroute.json and replayed, so the board rebuilds byte-identically
    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
    [bom.csv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]
2026-09-21 firmware: catch a dead INA226 instead of reporting stale readings
    ESPHome's ina226 component does not publish NAN when an I2C read fails.
    update() calls status_set_warning() and returns, so every sensor keeps
    its last good value indefinitely. The classifier's isnan() test for "no
    sensor data" could therefore never fire: a cracked joint, a bus fault or
    a brown-out on the 3V3 rail would leave the board reporting the last
    current it happened to see, forever. For a measuring instrument that is
    the worst available failure, because it looks entirely plausible.
    Stamp millis() on every successful shunt read and treat more than
    stale_timeout_ms (5 s) without one as a fault, ahead of every other
    stat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
    [esp32-4to20ma-board.yaml]
2026-11-11 Review branch: own grid router (gridroute.py) replaces Freerouting; module supply scripted through C3; limiter and boost blocks redrawn wired
    Not for fabrication. Rev G netlist and pin map unchanged.
2026-11-11 Rev H schematic: input protection, loop supply off by default, sheet redrawn on A3
    Circuit (owner decisions 2026-11-11):
    - D5 SMAJ12A -> SMAJ28A, new F1 (100 mA / 60 V PPTC) in series with the mA
    input and D6 (1N4007W) across the shunt: a surge or 24 V wired to the mA
    pin now puts D6's 1 V across the shunt instead of the fault.
    New nets LOOP_IN (terminal side) and LOOP_RTN (shunt side).
    - R15 is a pull-down: the loop supply stays off until firmware turns it on.
    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
2026-11-11 Rev H board: protection parts placed, corner re-laid, legend, routed, fab rebuilt
    - F1 and D6 placed; the row above the terminal is now D5 | TP2 | F1 | D6 | D3
    (upright), D4 moved into the strip right of the terminal, TP1 beside R20
    (designator hidden), third fiducial moved to the west edge. Nothing live is
    within 2.6 mm of the centre of the corner mounting hole.
    - R15 turned round: MT_EN pad under pin 18, ground pad on its own via.
    - Scripted routes for LOOP_IN, LOOP_RTN, LOOP_C, LOOP_V and the new grounds;
    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
